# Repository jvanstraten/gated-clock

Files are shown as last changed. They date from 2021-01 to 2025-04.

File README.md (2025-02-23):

Gated Clock
===========

A clock suitable for electronics nerds, built out of 3-input NAND gates.

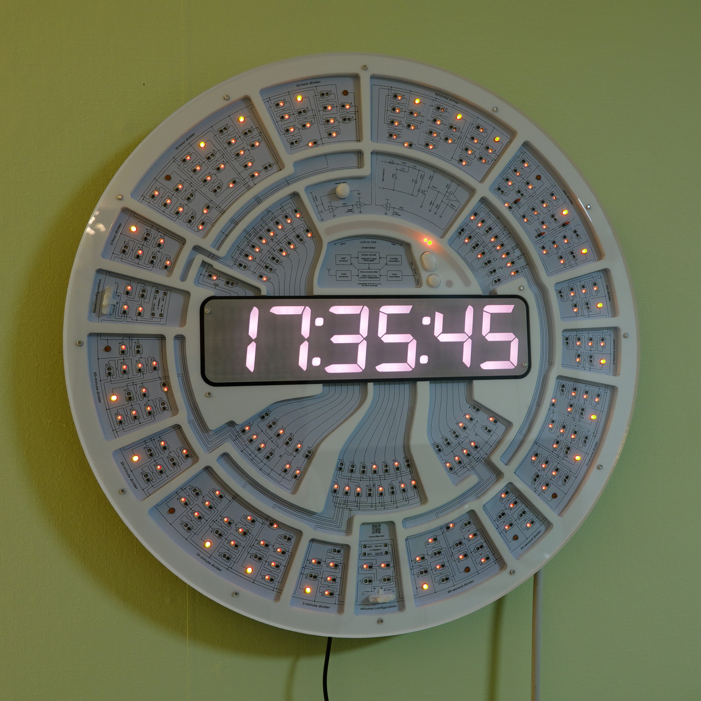
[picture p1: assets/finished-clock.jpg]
Clock


The point of this project is to:

 - build a functional digital clock out of only discrete logic gates (74LVC1G10
   3-input NANDs to be specific) and passives;
 - make sure the entire circuit for as far as this is needed to make it work is
   visible on the front, with LEDs for (almost) all digital signals;
 - actually make it look pretty; and
 - actually make it useful.

Note that none of the above include anything about BOM cost. See the section on
cost below.

The status of the project is that I've manufactured a total of nine clocks for
myself, friends, and family at this point. There's some renewed interest, so a
second run might happen; however, the Teensy LC that the old design used for
misc UI tasks is now EoL. Work is in progress to replace it with a Raspberry Pi
Pico W.

License
-------

Let's get the fine print out of the way first. The license for this stuff is
[Creative Commons BY-NC-SA 4.0](https://creativecommons.org/licenses/by-nc-sa/4.0/).
See also the LICENSE file for the full plaintext.

Note: if anyone out there would like to commercialize this somehow and needs a
different license, I'm all ears. I mostly just want to know about it if someone
does. See also: "why not build a bunch of them and sell them?"

The only exceptions to the license are the 3D models of the electrical parts I
used for the renders (basically, any of the .blend files in the `models`
directory); some of these are converted directly from the STEP files provided
by the part manufacturers and are thus licensed under different terms. I'm
honestly not too sure what these terms are, since most of the legalese they try
to make you read is about limitation of warranty with regards to model
accuracy.

How does it work
----------------

The short version is as follows.

 - The electricity grid oscillates at 50Hz or 60Hz depending on where you live,
   with stipulations about long-term accuracy by law in most places. So, while
   synchronizing clocks to the grid frequency is old-fashioned, it's actually a
   supported use case.

 - A circuit based on a capacitive dropper, an optocoupler, and some active
   filtering translates the high-voltage AC signal to a logic-level clock
   source.

 - A bunch of NAND-gate-based D-flipflops divide this frequency down to
   increasingly lower frequencies. Divider circuits exist for a factor 2,
   factor 3, and factor 5. The chain used is as follows:

    - divide by 5 to get 10Hz or 12.5Hz;
    - divide by 5 or 2x3 (jumper-configurable) to get to 2Hz;
    - divide by 2 to get to 1Hz;
    - divide by 2 to get to 1/2Hz (= 2 seconds);
    - divide by 5 to get to 1/10Hz (= 10 seconds);
    - divide by 2 to get to 1/20Hz (= 20 seconds);
    - divide by 3 to get to 1/60Hz (= 1 minute);
    - divide by 2 to get to 1/120Hz (= 2 minutes);
    - divide by 5 to get to 1/600Hz (= 10 minutes);
    - divide by 2 to get to 1/1200Hz (= 20 minutes);
    - divide by 3 to get to 1/3600Hz (= 1 hour);
    - divide by 2 to get to 1/7200Hz (= 2 hours);
    - divide by 5 or 2 based on the last divider to get to an average of
      1/28800Hz (= 8 hours);
    - divide by 3 to get to 1/86400Hz (= 1 day).

   Note that the division works very different than how you would do it in an
   FPGA. In an FPGA you'd probably have binary counters with a clock-enable
   signal on the registers and call it a day. But that requires *considerably*
   more logic to do. The dividers here are all clocked based on the previous
   output, which omits the clock enable requirement, and they are based on
   shift registers rather than regular binary counters. Note also that the
   dividers are chosen such that each decimal digit of the time it represents
   has its own set of counters, with states independent from the counters for
   the other digits.

 - A bunch more NAND gates in an and-or-invert configuration take the state
   signals and convert them to (active-low) 7-segment display signals for the
   clock readout. These drive the LEDs more-or-less directly.

 - A clock needs to be configurable, of course. It'd be a bit inconvenient if
   you'd have to turn it on at midnight exactly. Therefore, the clock signal
   for the minutes and for the hours passes through a configuration circuit
   with a three-way switch that allows you to override it: the circuit either
   forwards the clock signal in one extreme position of the switch, overrides
   it high in the middle position, and overrides it low in the non-latching,
   opposite position. The subsequent dividers increment on the rising edge of
   the clock signal, so releasing the switch from its non-latching position
   always increments the time, and going from the passthrough position to the
   middle position *may* increment the time (this is an unwanted side effect
   that would require an XOR to avoid, which would take more gates than I had
   room for).

 - Flipflops require a reset signal to be put in a well-defined state. A
   power-on reset circuit asserts this global reset line to do this at powerup,
   and a button allows you to override. This button could also be used to
   synchronize the seconds counter, as the clock starts at 00:00.

 - Because I don't like manually configuring clocks, and especially setting the
   time with the above interface would be annoying, there's also a
   microcontroller in here somewhere. This microcontroller can also override
   the minutes and hours clock signals, so it can also set the time. It can
   also read and override the non-latching position of the manual configuration
   switch, allowing it to convert its function to increment the time when
   you're pushing it outward rather than when you release it, and to
   auto-increment it when you hold it in the extreme position. Different-color
   LEDs are used to indicate the state of these override signals, so it's clear
   when the microcontroller is doing something. The microcontroller can
   synchronize itself using a GPS module (GPS is about the most accurate time
   reference you can get in your home that isn't a literal atomic clock!).

 - Because I had some room left on the board visually, I added a sort of
   synchroscope to it for showing the speed difference between the
   GPS-referenced and grid-referenced time signals. This is completely
   unnecessary for the operation of the clock, but I'm generally also
   interested in seeing the grid frequency fluctuations, so it's kind of a
   two-projects-in-one thing for me.

 - The microcontroller can also override the reset signal, read and override
   the grid frequency clock signal, and read and override the state of the
   7-segment display. This allows it to do fancy stuff like a self-test of the
   circuit (so you don't have to wait a day for it to pass through all states),
   and to override the display with a menu structure in conjunction with three
   soft buttons.

 - Finally, the microcontroller controls LED brightness and (in case of the
   7-segment display) color using not only PWM but also analog dimming.
   Basically, I hate flickering LEDs and LEDs that are way too bright, and
   couldn't make up my mind about the display color so I rammed some RGB LEDs
   in there.

For more details, check out the `primitives` and `subcircuits` directories.
Most of the circuitry is ASCII-art'ed in there, with more elaborate
descriptions.

How did you design it
---------------------

Yeah, about that. I'm used to working in Altium, but didn't want to use it for
this because:

 - arcs, arcs everywhere;
 - it's ridiculously slow nowadays;
 - I only have access to a sponsored license through a student association
   which has nothing to do with this project, and their licenses are
   unaffordable when you're not designing PCBs for profit full-time.

I heard KiCad is good and tried it, but started hating my life within a few
hours. Altium has spoiled me.

So, I did what any reasonable person would do and ~~abandoned the project~~
built my own PCB design flow from scratch using Blender and Python. More
details on this are in the README file of the `primitives` directory.

The practical upshot of doing everything from scratch however is that I could
hook into it wherever I wanted. For example, the Python scripts also generate
VHDL to test the actual circuit logically, with some best-effort timing
estimates even. After generating everything, you can just run `vhdeps ghdl`
or `vhdeps vsim` (see the [vhdeps](https://github.com/abs-tudelft/vhdeps)
for more info) and it will check everything (GHDL is super slow for the
main test case however). It also allowed me to make proper no-compromises 3D
models of the PCBs, something that I always wished Altium would let me do. I
don't just want the holes and outline, damnit, I want the copper traces and
silkscreen and soldermask and whatever as well! Seeing as part of the goals
is for it to be pretty, being able to make proper renders in advance was pretty
important for me.

How do I get one
----------------

tl;dr: I do not sell these, nor do I plan to do so personally. You're free to
build one yourself though (and I'd love to hear about it if you do!), and I'm
open for discussion on commercializing it if that's your cup of tea.

### BOM cost

I personally didn't care too much about this. I mentally give myself an
approximate monthly allowance for hobby stuff, and because this project has
taken so long already, I'm actually way under budget. That means I did
basically *no* cost-optimization.

I can't put an accurate price tag on the thing because I split everything over
multiple orders while prototyping, but I would expect the whole thing to set
you back somewhere around **€500-€800**, assuming you already have the
necessary equipment for SMD soldering and a 3D printer with sufficient build
area.

A lot of that is startup cost though. For example, the main PCB is ~€200 for
the minimum quantity of five even at insanely cheap places like JLCPCB. One
does not simply a 40x40cm four-layer PCB with white soldermask, I guess. The
acrylic lasercutting also has a significant startup cost, and of course part
cost at Mouser or whatever distributor you prefer will go down for higher
volumes as well. The price per clock probably drops off to around €300 or so
per clock for five of them.

### But if it's so much cheaper at scale, why not build a bunch of them and sell them?

I can't believe I'm writing this; it feels so "full-of-myself". The only reason
I'm putting this here is because multiple people have asked me to make one for
them.

No, I won't personally be commercializing these. I honestly can't be bothered
dealing with things like shipping, managing payments, taxes, supply chain,
redesigning the whole thing for pick & placing rather than manual soldering,
and so on. I'm the kind of person to hand perfectly resellable stuff over to a
local goodwill or whatever for free because trying to do anything more stresses
me out so much that it's just not even close to worth it.

*However.*

I love the idea of this thing hanging on someone else's wall as well.
Therefore, I made sure not to use any software or whatever that does not allow
commercial usage, and I did make sure that the thing should work worldwide
(50/60Hz selection, 100-250VAC input voltage, and using GPS instead of DCF77
for time sync). So, in case someone with a more entrepreneurial spirit than I
have wants to pick things up from where I left off to sell these for a profit,
it should be no problem aside from the things I mentioned above. I would expect
*some* compensation (hence why I've slapped a noncommercial license on this
thing for now), but ultimately this is just a hobby project for me. Mostly I
just want to know about it if someone does this. You can contact me at
e.

Above does not apply if you just want to build one yourself and sell the other
four to friends to recoup some of the one-off costs, like I might do. If that's
all you want to do, go for it; I'd still like to know out of curiosity, but I
don't expect anything in return. The limit for me would be when you start making
profit.

Okay, then how do I build one
-----------------------------

You're going to need the following things.

 - A Linux computer or VM, probably. Some or all of it may work on Windows/Mac
   too, but your mileage may vary. The following software is needed:
    - Blender. Scripts updated for blender 4.2. Blender is good with
      compatibility, but with all the scripting going on, you might want to get
      that exact version. The makefiles look for `blender-4.2` in your `PATH`
      first if it exists, before defaulting to just `blender`.
    - Python 3.x. It used to work back on 3.6, nothing has meaningfully changed
      since, and it still works on 3.13 now that I'm writing this update. It
      probably doesn't matter too much if your version is newer than that.
    - [Gerbertools](https://github.com/jvanstraten/gerbertools). Depending on how
      lazy I am you might have to build it yourself, but that should be pretty
      easy.
    - The following regular Python modules: `matplotlib` (3.10) and `qrcode`
      (worked with 6.1 initially, still works with 8.0 without changes).
    - ImageMagick for converting huge SVGs that take forever to render to
      big-enough PNGs.
    - Inkscape for making PDFs out of SVGs (part of the acrylic plate pipeline,
      you'll probably have to customize/redo this though).
    - `git`, as in the commandline version, should exist. It's used by the
      generator to tag the generated boards with the current revision.
    - `make` is abused for some things.
    - `7z` (7zip) is used for packing the generated gerber files into a zip
      file.
    - You may also want [`vhdeps`](https://github.com/abs-tudelft/vhdeps) and a
      compatible simulator, if you intend to change any circuitry.

 - Soldering equipment. If you've never soldered (SMD) before, this might not
   be the best project to start with. The LED drivers in particular are 0.5mm
   pitch TSSOPs with a thermal pad. The boards are designed to be hand-soldered
   though, so the pads are relatively long, and I took care to only connect
   traces to the end that you stuff the soldering iron into, so heating them up
   should be relatively easy. Unless you like to live dangerously, you should
   also have anti-ESD gear and actually use it during assembly.

 - A current-limited lab power supply, multimeter, waveform generator, and
   oscilloscope are very much nice-to-have. I don't think it's humanly possible
   to solder everything correctly the first time, so you will be doing some
   debugging.

 - A 3D-printer with at least 21x25cm build area. I'm using a Prusa MK3s with
   a stock 0.4mm nozzle and print in PETG. I'm not sure how much filament is
   used exactly. You'll want some 3D-print post-processing stuff as well, which
   I'm assuming you'll have if you have a printer.

 - An M3 tap for inner thread.

 - A source for the lasercut acrylic plates. I'm using a local Dutch shop
   ([laserbeest.nl](https://www.laserbeest.nl/)). Unfortunately I'm not sure if
   they ship internationally. Their ordering instructions are a bit "custom",
   so you'll probably have to change the pipeline or do some manual conversion
   work of the generated PDF/SVG files.

 - A source for the two PCBs. I'm used to ordering from JLCPCB, but there are
   more of them out there.

 - A source for the components. I'm using Mouser for everything now, so the
   generated ordering information is for them.

 - A source for the Teensy LC, the GPS module, and the antenna. I got those
   from [TinyTronics](https://www.tinytronics.nl/shop/en); a local shop again,
   but I'm pretty sure they ship internationally, or at least within Europe.
   Either way, the Teensy in particular shouldn't be hard to get your hands on,
   and you can probably jury-rig any GPS module you want in there (or leave it
   out entirely if you don't care enough about GPS sync). The headers you'd
   probably want to mount the Teensy to the support board are not included in
   any ordering list; you can do anything between proper male/female headers
   and just sticking wires through the holes and soldering them.

 - Some miscellaneous parts not in any ordering list because I had them laying
   around:

    - 41 M3x12mm screws with a domed head of at most 6.2mm diameter and about
      2mm thickness, though if you don't have a bunch of screws in stock you
      might want to get longer ones and cut them to size with a thread cutting
      tool;
    - 25 standard M3 hex nuts, 2.5mm thick;
    - a long M3 screw is nice to have to help pull the nuts into the printed
      parts;
    - a screwdriver for the above, obviously;
    - calipers are very useful to have lying around, if only to measure the
      thickness of the acrylic you got;
    - a mains power cord to mount to screw terminals on the support board
      (preferably with grounding lead, though this is technically not necessary
      due to the lack of exposed metal);
    - stuff to clean the acrylic with when you're done (I used "wasbenzine,"
      but that stuff doesn't seem to have a proper English translation for some
      reason. The best translation I suppose would be pure gasoline. Contrary
      to what Google et al will tell you it is *not* white spirit, which would
      be "terpentine" in Dutch, and would be likely to mess up your acrylic).

 - An appropriately filled wallet, because this is not a cheap project. But we
   went over that already.

### 1) File generation

If you're ordering via laserbeest and want to use the existing pipeline, you
will want to set the following environment variables:

 - `ACRYLIC_NAME`: your full name;
 - `ACRYLIC_EMAIL`: your e-mail address; and
 - `ACRYLIC_PHONE`: your phone number.

These are added to the SVG/PDF files that are generated for Laserbeest for
their reference, as per their instructions.

You'll also want to update the header of `generator/orderlist.py` to select
the LED color you want. Seven color schemes are predefined. At the time of
writing I've only tried orange; your mileage may vary with the resistor values
for other colors. LED brightness differs a lot based on color.

Once you have all that, or the computer part at least, run `make` in the root
directory and go get coffee. It takes 20 minutes or so to generate everything
on my fairly beefy computer, though most of it is single-threaded because I'm
lazy, so the beefyness of your computer might not make too much of a
difference.

Note that the root makefile is *not at all* intelligent, and may as well be a
shell script. You may therefore want to comment out part of the `make` recipe
manually while iterating to not regenerate literally everything each time.
There's also `generator/config.py`; if you set the `LAYOUT_ONLY` constant,
things will be way faster, but won't generate any copper, and use
reduced-complexity routing for the circuit on the silkscreen.

Anyway, the pipeline generates the `output` directory, with about a GB's worth
of files in it (hence why I don't try putting the generated files on github).
The filenames should be fairly self-explanatory, at least in conjunction with
the documentation scattered about this repo in the form of README files.
Nevertheless, the most important ones are:

 - `mainboard.zip`: Gerber production files for the main PCB;
 - `support_board.zip`: Gerber production files for the support PCB;
 - `*.*.traces.png`: circuit board assembly instructions (and copper layout);
 - `mainboard.laserbeest.pdf`/`.svg`: acrylic plate production files;
 - `mouser.txt`: Mouser ordering list; and
 - `tinytronics.txt`: TinyTronics ordering list (the Teensy, GPS, and antenna).

### 2) Ordering

You should start by ordering the parts, obviously: the Mouser/TinyTronics
electronics parts, the PCBs, the acrylic sheets, and the consumables if you
don't have them laying around like I do.

As stated, the build process generates `mouser.txt` for the mouser ordering
list, usable [here](https://nl.mouser.com/Tools/part-list-import.aspx). If
things are not in stock, you'll either have to wait or look for alternatives
yourself; you can specify these alternatives in `generator/orderlist.py`, after
which you can regenerate by just running `python3 generator/orderlist.py`. If
you (have to) go for the backorder route, I strongly recommend the "ship items
as they become available" option; in my experience, Mouser doesn't reserve
anything for your order, so by the time the originally problematic part is
finally back in stock, something else might be out of stock again.

After you copy the part list into your basket, make sure to round up the part
count, especially for uncommonly used resistor values and such: Mouser levies
what I can only describe as an "asshole tax" for people who order small amounts
of these, as ordering more will often cost *less*. I've seen an extreme case
where the price break for 10+ was so much cheaper than the price break for 1+
that buying ten was cheaper than buying one! The ordering system does not
notify you of this. In general, by the way, it's good practice to over-order
the tiny parts a little bit, so you don't have to place a new order if you
misplace or break a few of them.

As for the Tinytronics parts, the actual parts are a Teensy LC (which you can
get just about anywhere), and any GPS module with a VCC|GND|TX|RX|PPS pinout
using a standard 2.54mm header. You can probably source both from wherever if
Tinytronics doesn't work for you. Don't forget to buy an antenna with a long
lead as well; they're commonly available for use in cars. Headers to mount
these are not included in the Mouser order either, so you'll need to get them
yourself.

For the PCBs, everything assumes standard 1.6mm 4-layer PCBs with 1oz copper on
the outer layers and something around .5oz on the inner layers. The mainboard
is visible and is assumed to be built with a white soldermask and black
silkscreen, but it's up to you; the support board is not visible and thus the
color does not matter. Stackup was designed with 0.1mm between the outer and
inner layers in mind, but I later found out that JLC only does this for green
soldermask PCBs, so I ended up with 0.2mm separation. Doesn't really matter;
nothing is explicitly impedance-matched. The only thing is that the trace
capacitance calculations I did assume .1mm separation, but that would be the
worse case anyway.

The footprints are designed for conventional soldering by hand. If you want to
use solder paste with an oven or hot air, you might want to rework some
footprints here and there. In particular, the support board has four components
with a thermal pad (the LED drivers and the hot-swap controller), which have a
large hole under the pad to provide access to a conventional soldering iron;
you'll probably want to remove those holes when using solder paste.

As for the acrylic, three sheets are needed:

 - `Front`: clear, 3mm, at least 40x40cm. Includes engraving instructions in
   addition to cuts.
 - `Highlight`: opaque white, 5mm, at least 40x40cm.
 - `Display`: opaque black, 3mm, at least 23x6cm.

The thickness tolerance of Laserbeest's acrylic source is abysmal, apparently
due to how the sheets are made. So everything is designed with about +/-1mm
thickness tolerance in mind. However, you may need to adjust some 3D-printed
parts here and there, or you may need slightly shorter or longer M3 screws.
Of particular importance is that the button and slide switch caps have the
right height,

You may also need to adjust the hole sizes in the `Front` sheet based on laser
width and how gutsy you're feeling. They need to be threaded, so the finished
hole size should be 2.5mm. They are 2.35mm in the design files for Laserbeest,
which worked well based on experimentation.

When you receive the acrylic, don't throw the bubble wrap it undoubtedly comes
wrapped in away! It'll be useful during assembly.

### 3) 3D-printing

I would recommend to wait with this until you have the acrylic, because some of
the parts depend on its thickness to various degrees. I was far too impatient
for this, myself; just be aware that you may need to reprint parts later if you
don't wait. The following parts depend on the thickness of the acrylic:

 - the four quarter panels of the back shell have the clamping surface for the
   screw heads at just the right size for the bottom of the M3x12 screws that
   mate with the clear acrylic sheet to be flush with the front, so this
   recess depends on the thickness of the white and clear acrylic sheets;
 - likewise for the "display extender" part, of which both the total height and
   mounting flange thickness depends on the thickness of the black and clear
   acrylic parts;
 - the button and slide switch caps depend on the thickness of the white
   acrylic sheet.

The Blender sources for the parts are in the `printed` folder, the main one
being `assembly.blend`. When you open it (give it time, the boolean operations
and geometry involved are considerable) you will be presented with some text
and a few "empties;" the axis-looking things in the middle. Their negative-Z
position represents the thickness of the three acrylic sheets. You can select
them by right-clicking (or left-clicking I think, if you're using the 2.8+
keybinds), and then use the transform panel on the top-right of the viewport to
change the Z coordinate to negative the thickness.

Once you've done that, note the note the panel on the top-right of the screen,
listing the assembly steps. You can disable visibility of all the steps except
the first by clicking the eye icons, then work from there. Use numpad 7 to view
the clock from the back (as you will be assembling it), or numpad 9 to view it
from the front. Dragging the middle mouse button will drag the view around,
holding shift as well will pan, and scrolling zooms in and out.

STL files can be generated by selecting the object you want (right/left-click
as before), selecting File -> Export -> STL, ticking the "Selection Only"
checkbox on the right, and picking a nice filename. You'll have to orient them
onto the build plate (most parts have an obvious flat side) using the slicer
for your printer.

I use PETG for everything. PLA might be fine as well, but be careful that in
particular the mounting bracket is strong enough -- wouldn't want the clock to
break off your wall in the middle of the night. I don't exactly consider myself
to be a very experienced 3D-printer, so your mileage may vary.

Some of the parts need build plate supports, so some post-processing is
involved. The slide switch caps in particular needed some TLC for me before
they would slide properly, and I had to drill out the holes in the spacers for
the extra-long headers. If you don't have a 1mm drill and a drill press to do
this with, you can probably mess with the part and print settings until that
one works straight out of the printer though, or you could probably also just
eyeball the correct insertion depth for the headers when soldering.

### 4) Mechanical assembly (dry run)

Once you have the 3D-printed parts, acrylic, and bare PCBs, I would suggest a
dry run of assembling the thing, so you know what goes where and you can be
sure everything fits before all the delicate parts are populated.

 - Carefully clean the clear acrylic sheet. There will be debris from the
   engraving; make sure it doesn't cause scratches! I personally messed up here
   because I assumed there would be protective foil on both sides; there was
   not.

 - Carefully tap the holes in the clear acrylic sheet. Be patient; acrylic
   cracks if you're too rough. Don't use power tools!

 - Place the clear acrylic sheet on bubblewrap, to avoid causing scratches and
   allow the button and slide switch caps to stick out slightly. The rough,
   engraved side should be facing up.

 - Place the black acrylic sheet on top. It is *not* symmetrical in any
   direction: make sure that the colons are off-center *away* from the side
   with the synchroscope and pushbutton cutouts, and of course that the
   screw holes align.

 - Place the printed display extender part on top of the display, again
   ensuring that it is oriented correctly.

 - Mount the black acrylic sheet and display extender using two M3x12 screws.
   Be careful not to exert too much torque; threaded holes in acrylic are
   quite fragile!

 - Place the white acrylic sheet on top. The cutout for the display should
   constrain it in roughly the right place aside from 180deg rotation symmetry;
   align based on the synchroscope engraving and/or button cutouts to avoid
   mounting the plate upside down.

 - Place the three button caps (2x round, 1x oblong) and the two slide switch
   caps in the appropriate cutouts.

 - Carefully place the mainboard on top. First align the slide switch caps with
   the slots in the PCB (and the slide switches themselves if you already
   soldered then), then align the pins on the bottom of the button caps with
   the holes in the PCB, and finally align the holes.

 - If you haven't already, insert nuts in the hex recesses of the four quarter
   panels. There are eleven of these. Pull them in with a screw if necessary,
   and make sure they're all the way in (they should be flush or slightly
   recessed into the bosses. If your print is undersized and they fall out, you
   might want to glue them in.

 - Slot the quarter panels together. They are all different, so there's only
   one way to do this. Secure them by placing screws in the four shared screw
   holes; the assembly shouldn't fall apart anymore after you do this, although
   it will still be quite floppy.

 - Carefully place the panels over the rest of the assembly. The triangular
   screw hole pattern should be at the top of the clock, i.e. the side with the
   synchroscope and buttons.

 - Start by tightening the four screws that hold the quarters together. Again,
   be careful not to exert too much force. Be especially careful if you're
   impatient and are doing this before you have the PCBs: you can easily break
   the 3D-printed parts by tightening the screws without the 1.6mm spacing
   provided by the PCB. Once these four screws are in, screw the remaining ten
   in in any order.

 - Flip the clock over and make sure that the slide switches and buttons move
   freely. If not, disassemble in reverse order and file them down a bit.
   Repeat ad nauseum until they work right. Once done, place the clock down
   on its front again on the bubble wrap.

 - Mount the wall mount bracket to the assembly with three screws. The screws
   mate with the triangular-pattern nuts in the top quarter panel. Be careful
   when tightening these the first time; the screws should be too short to
   reach the PCB, but if they do, you can easily damage the PCB.

 - If you haven't already, insert nuts in the hex recesses of the support board
   interface part. There are four of these. Pull them in with a screw if
   necessary. If your print is undersized and they fall out, you might want to
   glue them in.

 - Mount the panel-mount SMA antenna connector end of the SMA to uFL adapter
   cable that comes with the GPS antenna to the small square SMA insert part,
   making sure to align the flat side of the panel-mount connector with the
   flat side of the hole.

 - Slide the above assembly into the corresponding retaining structure of the
   support board interface part. Note that this might require some "gentle
   persuasion" the first time; it should be more-or-less press-fit.

 - Mount the support board interface assembly onto the main assembly with eight
   screws. They mate in the same way as the wall mount bracket, so be careful
   if the screws may be too long.

 - If you haven't already, insert nuts in the hex recesses of the display light
   guide. There are six of these. Pull them in with a screw if necessary. If
   your print is undersized and they fall out, you might want to glue them in.

 - Mount the display light guide to the support board using six screws. Be
   careful not to place it upside down; follow the silkscreen on the PCB.

 - If you haven't already, insert nuts in the hex recesses of the high-voltage
   top cover and strain relief. There are two of these in either part. You
   know the drill by now.

 - Mount the top and bottom high-voltage covers to the support board using two
   screws. There should only be one way to do this.

 - Mount the strain relief to the bottom high-voltage cover.

 - Place the support board onto the main assembly, making sure to align the
   screw holes. The upright flanges inside the support board interface part
   should constrain it.

 - Place the support board cover on top. Again, some "gentle persuasion" may be
   needed for the SMA connector insert the first time. Finally, clamp it down
   with four screws, that should mate with the four nuts in the support board
   interface part.

 - Carefully lift the clock up by the wall mount. Make sure it's strong enough
   to hold the weight with ease.

 - Find a nice place to mount it to a wall! You can just use a nail or screw to
   do it, or you could print a part that mates with the wall mount bracket if
   you're worried about the strength of the part.

Disassemble in the reverse order as usual. The wall mount can stay mounted to
its quarter panel, but note that you can't remove the quarter panels from the
acrylic without removing the support board assembly, because it hides one of
the fourteen screws that mate with the acylic.

### 5) Electronic assembly

Some preprocessing is required:

 - The 3D-printed parts include a small lead bending tool for the 3mm LEDs. It
   consists of two square printed parts, and is completed using four M3 nuts
   and four M3x12 screws. To use it, push the LED into the hole, bend the leads
   outward far enough for the screws to reach the recesses for the nuts on the
   other side, then carefully tighten the screws while guiding the leads into
   the cutouts for them. Once tightened, cut the exposed part of the leads off
   with pliers. Finally, disassemble everything again to retrieve the LED. I've
   found that two screws on opposite sides is enough.

 - The trace connecting the USB bus voltage to the 5V rail on the Teensy LC
   must be cut, to prevent the power supply on the support board from trying to
   power your PC.

 - The mainboard to support board connectors are slightly too short right out
   of the box: the male side should be soldered flush to the opposite side of
   the PCB rather than having it stick through slightly as usual.

Ultimately, the order in which you solder the parts is up to you. Here's some
tips and recommendations, however.

 - I couldn't be bothered to add part designators to the board generation
   scripts and design entry file formats, so you'll have to use the
   `*.*.traces.png` output files to figure out what to solder where. However,
   the circuitry is so repetitive that you won't need it most of the time.

 - The mainboard circuitry is highly linear, which means you can solder one or
   a few subcircuits at a time and then test whether everything works. Start
   with the reset circuit and the clock pulldown resistor (the 10k resistor
   near the TSSOP I/O expander), then work your way around clockwise for the
   dividers, and finally solder the decoders. You can test using the staggered
   receptable for a standard 2.54mm 5-pin header (push it in upside-down; the
   spring force of the pins will friction-lock it in place). The `f50Hz` signal
   should receive a 0V..5V clock signal, `Vled` and `Vffled` should be pulled
   *down* to somewhere between 2.5V (max brightness) and 4.5V (least
   brightness) to turn the LEDs on, and `0V`/`5V` should be self-explanatory.
   A two-channel waveform generator is ideal for the `f50Hz` and
   `Vled`/`Vffled` signals, the latter because a waveform generator can pull
   down as well (unless you have a super-fancy power supply, it won't be able
   to). If you don't have a waveform generator or only have a single-channel
   generator however, you can probably get the LEDs to light up with a 1:1
   voltage divider using 100R resistors as well, and you can strobe the clock
   by just pushing a 5V wire into the `f50Hz` signal (it will bounce though,
   so this won't be very controlled). Use a properly current-limited power
   supply (somewhere around 400mA should be enough for the whole clock with
   the default LEDs), such that you don't fry something if you accidentally
   short-circuited something. Being able to see the current is also very
   useful, because then you'll see the current rise when a gate output is
   shorted. Other than that, ensure that all LEDs blink when you apply enough
   clock pulses. Some common symptoms:

    - Current shoots up by about 40mA for some flipflop states: there's
      probably a short-circuit to 0V or 5V *after* a 100R filter resistor.

    - Current shoorts up by about 150-200mA for some flipflop states: there's
      probably a short-circuit to 0V or 5V between a gate output and the
      100R filter resistor.

    - Current limit kicks in at around 1.0V to 1.5V: you probably mounted a
      gate rotated 180-degrees.

    - Current limit kicks in immediately: you have a dead short somewhere. You
      can trace this by measuring the voltage across the decoupling capacitors
      while the power supply is on. I got about 2.7mV over the decoupling
      capacitors serving good circuits and less than 2mV for the one that had
      the short, for only 200mA supply current.

    - No unexpected current (the current should be <1mA when the `f50Hz` input
      is idle and the LEDs are off), but one or more flipflops/decoder outputs
      don't work right: usually this is due to a bad soldering joint for one
      of the gates. You'll have to debug this by finding the gate that doesn't
      perform its logic function properly.

    - The circuit works, but a LED doesn't light up: check for bad soldering
      joints in the LED circuitry.

    - Everything is fine in steady-state, but a flipflop doesn't work: I didn't
      personally encounter this, but this is what I'd expect to see if you
      misplaced a capacitor or resistor somewhere in the RC filter circuits.
      The filters are there to solve worst-case hold timing, so the flipflops
      might misbehave with improper filters. I've found that leaving the 330pF
      and 2.2nF capacitors out entirely also works, however (with a sample size
      of only 1 flipflop, though).

 - While soldering the mainboard, put short screws in the screw holes that
   prevent you from accidentally exerting force on the 3mm LEDs or 1.27mm
   jumpers when the board is upside-down. Otherwise, you can easily bend the
   headers, or push the SMD pads for the LEDs right off the board.

 - For the support board, first solder the hot-swap controller circuit and test
   it. There's a lot of critical resistor values there, and if they're wrong,
   the board won't do anything or won't be as protected against
   over/undervoltage and overcurrent as it can be. I would furthermore suggest
   leaving the mains stuff for last, because it's large, and because you'll
   then lose the ability to power the board with a better-protected lab power
   supply.

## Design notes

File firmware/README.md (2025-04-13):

Firmware
========

By design, the clock can operate entirely without any microcontroller firmware.
After all, the whole point is to demonstrate that you can make a useful circuit
with only NAND gates and some discretes. Nevertheless, some auxiliary functions
are handled by a microcontroller:

 - LED brightness and color control;
 - automatically configuring the time using GPS after a blackout;
 - blinking the display before a time is set (either manually or automatically)
   after a blackout;
 - automatic DST changes;
 - the synchroscope display; and
 - handling UI stuff for configuring all of the above.

Build process
-------------

The microcontroller (board) in question is a Teensy LC. I opted for such a
board versus a "discrete" microcontroller primarily because you don't need a
programmer for them, and because Arduino makes it so easy to set something up
quickly. Arduino is however hardly a platform for distributing a reproducible
build with: the user has to manually set options like board, operating
frequency, and USB mode, and many times for Teensy you end up changing system
files to change a buffer size somewhere or something. Therefore, to try to make
things a little better, a docker-based build is provided.

When you run `make` in this directory, the following things will happen:

 - docker will be used to do a build using exactly the Teensy core library
   version I use;
 - the [Teensy loader CLI](https://github.com/PaulStoffregen/teensy_loader_cli)
   will be downloaded and compiled;
 - an attempt will be made to put the first Teensy connected to your system in
   programming mode (this only works when it has a program on it that uses the
   USB for serial communication); and
 - an attempt will be made to program the Teensy (if aforementioned fails,
   you'll have to press the programming button).

So, before running `make`, make sure that you have a working Docker, working
dev essentials (GCC, make, etc), and the libusb 0.1 development headers that
the Teensy loader CLI uses.

### Updating timezone definitions

You can automatically update the timezone database that the clock uses for
auto-DST by running `src/timezones.py`. The database is based on data provided
by [timezonedb.com](https://timezonedb.com/).

User interface and configuration
--------------------------------

The clock has three software-only buttons (labelled up, down, and mode), one
hardware reset button, and two slide switches. To the right of the mode button
there is also a dedicated RGB LED for status information. These elements,
combined with the main 7-segment display and the synchroscope bar, are used to
configure the clock.

Under normal circumstances, the 7-segment display displays the time, the status
LED is off, and the synchroscope display behaves as configured (by default, the
LEDs act like the needle of a electromechanical synchroscope). But there are a
few exceptional cases:

 - If the GPS module is not locked and GPS time synchronization is enabled, the
   status LED turns red.
 - If the time is invalid (for example, after a power cycle), the 7-segment
   display blinks.

The buttons and switches have the following functions in this state.

 - The hardware reset button resets the time. This also "invalidates" the time,
   making the display blink. If GPS synchronization is enabled, you can press
   this button to force resynchronization.
 - The slide switches may be used to manually configure the clock. The left
   switch controls the hours, the bottom switch controls minutes. To configure
   the time, you can use the following procedure.
    - Move both switches to the center position. This prevents the minutes and
      hours counters from updating when the seconds and minutes counters
      overflow.
    - Optionally, press the reset button when you want the seconds counter to
      read zero. There's no way to configure the seconds otherwise. Note that
      you'll want to disable GPS synchronization if you do this, or the clock
      may try to automatically configure itself instead.
    - Configure hours and minutes independently by pushing the respective slide
      switches into their clockwise position. If auto-increment is enabled in
      the clock's settings, the microcontroller will make this process more
      convenient: the counters will then increment when you push the button
      towards the clockwise position and will auto-increment if you keep
      holding it. If you disable this setting, the counters will instead
      increment only when you release the respective switches, but everything
      is handled by the discrete NAND circuit.
    - Move both switches back to the anti-clockwise position.
 - Pressing the down button enables "distraction-free" mode. In this mode, all
   LEDs except for the hours and minutes 7-segment displays and the status LED
   (if the GPS signal is used and lost) are disabled. Press the up button to
   exit this mode.
 - Briefly pressing the mode button will display the date in YYMMDD format, if
   GPS is currently available or has been available at some point since the
   last power cycle. The status LED will turn green to indicate that the clock
   isn't displaying time; also, the colons are turned off. Press mode again to
   return to normal operation.
 - Hold mode down for at least one second to enter the setup menu.

The setup menu consists of a number of configuration parameters, that you can
cycle through using the up and down buttons. You can leave the menu by holding
down the mode button again, by pressing up and down simultaneously, or simply
by waiting. When you leave the menu, any changes made to the configuration are
written to non-volatile memory, so the configuration survives a power cycle.

While in the menu, the current parameter is shown on the left side of the
7-segment display via an abbreviation. Its current value is shown on the right.
The status LED turns dark blue to indicate that you can cycle through the
values with up and down. The behavior of the synchroscope display depends on
the selected parameter.

The mode button is used to change the value of the current parameter. For
"enumerated" values, pressing mode simply advances to the next value. For
numeric values, the status LED will instead turn light blue, at which point
you can change the value by means of the up and down buttons. For most
parameters, the value will also blink to indicate that you can change it;
the only exception is the "display brightness" parameter. Instead, the display
will read `888888` while you're adjusting it, to give you a better idea of what
the brightness looks like, and also such that the clock can better monitor the
worst-case effect of the brightness on its own power consumption. For all
numeric options, pressing mode again confirms the new value, and allows you to
select a different parameter again.

The following parameters are available.

 - Flipflop LED brightness (`Fb`).
 - NAND gate LED brightness (`Gb`).
 - Synchroscope LED brightness (`Sb`).
 - 7-segment display brightness (`db`).
 - 7-segment display color saturation (`dS`).
 - 7-segment display color hue (`dh`).
 - Whether the 7-segment display brightness is automatically adjusted based on
   ambient lighting conditions. This requires an LDR to be installed. When
   enabled, the display brightness setting controls the maximum brightness.
 - Whether the seconds digits should be shown (`Sd`).
 - Configuration of the timing source of the clock and the synchroscope
   (`SYn`). Five modes are available.
    - Normal synchroscope operation (`1`). The clock is timed via the 50Hz or
      60Hz utility frequency, and the synchroscope shows whether the grid (and
      thus the clock itself!) is running slow or fast. Every 360-degree
      revolution of a real synchroscope represents a full 50/60Hz cycle lost
      or gained, which the display tries to model (despite not being a full
      circle) by moving with the same angular rate as a real synchroscope
      would, and rolling over every 84 degrees.
    - Lead-lag mode (`LL`). Like above, but instead, the synchroscope display
      shows the current offset of the seconds counter compared to GPS time.
      When the two center LEDs are both on, the clock is synchronized. When the
      outermost LEDs are both on, the clock is running exactly 30 seconds fast
      or slow. Note that this mode is not available when the seconds display
      is turned off.
    - Synchroscope display off, but still using the utility frequency as the
      clock source (`0`).
    - Synchroscope display off, using an internally-generated 50Hz timing
      source (`50`). When GPS is available, the frequency is referenced to it,
      so long-term stability should be extremely good. When GPS is not
      available, the crystal oscillator of the microcontroller takes over,
      making stability similar to a normal digital clock.
    - As above, but generating 60Hz (`60`).
 - Whether the software-controlled auto-increment logic is enabled for manually
   configuring the clock (`AInc`).
 - The [location code](timezones.md) corresponding to your timezone for GPS
   synchronization and automatic daylight-saving time adjustment (`LC`). Set to
   0 to disable automatic time synchronization.
 - Daylight-saving time configuration (`dSt`). This option is only available
   when automatic time synchronization is enabled. You can set it to `A` (auto)
   to have the clock update the time automatically when DST changes, or you can
   manually enable or disable daylight-saving time using values `1` and `0`.
   This is of course particularly relevant if your region decides to get rid of
   DST, or change its implementation. You can also choose to update the
   firmware in that case; you don't have to change any code to do this, but
   you will need to open the clock back up to attach a USB cable, and of course
   you need a computer that meets the system requirements for building and
   uploading the firmware.

For some of the options, the synchroscope display will show additional
information while the option is selected.

 - When LED brightness/color options are active, the synchroscope depicts the
   current power consumption of the clock. Full-scale is about 2.5A at 5V. When
   you somehow end up drawing too much current by making the displays too
   bright, software and/or hardware will kick in to reduce power consumption;
   at 3A or above brightness levels are automatically reduced across the board.
   Furthermore, if 3.5A or more is sustained, hardware protection circuitry
   will kick in and disable the clock until the next power cycle to prevent
   damage.
 - When the LDR option is selected, the synchroscope depicts the current
   (low-pass-filtered) value of the ambient light sensor.
 - When the location code option is selected, the synchroscope gives a rough
   indication of the GPS signal strength, which may help you find a good place
   for the antenna.

If necessary, you can do a "factory reset" of all options by holding down the
mode button while the clock powers up.

Debugging / Development notes
-----------------------------

### Listening to the serial port

When connected via USB, the board acts as a serial device, and can print some
debug data over serial. It will however only do so after being sent any
character from the host first. In a linux terminal, you can for instance use
the `screen` command to read this data. Note that the device file name may
differ depending on your setup.

- run `screen /dev/ttyUSB0`
- press any character

### Programming using Windows

While the default build process is gearded towards linux, it is possible to
program and debug the board from windows, using WSL. You will need to use
`usbipd-win` to forward the USB connection from windows to the WSL instance.
The workflow is as follows:

- install `usbipd-win` on the host computer.
- start your WSL instance on the host computer.
- in a windows terminal, run `usbipd list` before connecting the Teensy board.
- connect the Teensy board
- run `usbipd list` again to identify the bus id of the Teensy board
- run `usbipd bind --busid=BUSID`, where BUSID is the bus id of the Teensy board
- run `usbipd attach --wsl --busid=BUSID`, to attach the Teensy board to the wsl
  instance
- in WSL, install the required dependencies as stated above, and manually start
  the docker service if needed.
- run `make build` to build the firmware
- run `make program` to start the programming process. This will put the Teensy
  board in programming mode, which will cause it to reconnect.
- run `usbipd attach --wsl --busid=BUSID` again from the windows side to reattach
  the teensy board to WSL
- the programming process should now continue to completion.
- the board will detach again after programming is finished. If you want to
  debug it using the serial connection, simply reattach it again with the same
  command as before.

Note: while developing using WSL, the device will likely show up with a different
name like `/dev/ttyACM0`.

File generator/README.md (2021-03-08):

Circuit board (and acrylic) generator code
==========================================

This hot mess is what generates everything from the various other components in
the repository. The rough structure is as follows:

 - *parts* define off-the-shelf stuff;
 - *models* define 3D models for them (some parts share the same model, hence
   the distinction);
 - *primitives* are things drawn in Blender that define what (parts of) the
   circuit board looks like, which components go where, and the net names for
   their pins; and
 - *subcircuits* connect multiple primitives together via the generated,
   visually-pleasing routing on the front of the mainboard.

Primitives and subcircuits both operate on a CircuitBoard class, which in turn
contains a bunch of layers, as well as tacked-on acrylic plate definitions and
other mechanical data. The local coordinate system of a subcircuit can be
"warped" to achieve the circular transformation you see on the mainboard,
without actually warping the primitives they're built from -- the logic for
this is certainly the most complex part of all this, and god help you if you
have to or want to touch it. Finally, there is some text rendering support. The
text rather arbitrarily uses the Montserrat font from Google, and is rendered
with matplotlib (stop judging me!)

Once the gerbers are generated, [gerbertools](https://github.com/jvanstraten/gerbertools)
is used to turn them into SVGs and Wavefront OBJs, and to run electrical DRC on
them. Depending on how lazy I've been, you may have to build that module
yourself (it should be easy though, since it has virtually no dependencies
outside of a sane compiler toolchain). In total, the rules checked are short
circuits, unrouted nets, clearance (only logic-level, the 230V stuff is checked
manually), annular ring, and hole-to-hole distance. There is also some basic
netlist DRC support that ensures that logic nets in the clock circuit have
exactly one driver and at least one user, and that non-logic nets have at least
two connection points.

The entry point for all this is `compose_*.py`, awkwardly duplicated for the
two PCBs. As if that wasn't ugly enough yet, `post.py` post-processes the SVGs
generated by this and gerbertools to make see-through SVGs of the PCB, along
with net names and a notes layer that shows the pinout and sizing of all
components, which is quite useful for manually checking the circuit. In
general, the circuits are also listed in ASCII art in the primitives
directory... but I didn't go so far as to read those and do circuit-to-PCB
matching automatically. The PCB *is* the circuit.

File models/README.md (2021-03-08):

3D models for parts
===================

This folder contains 3D models for all the parts.

`template.blend` may be used as a template for them; it doesn't have the usual
light and camera and stuff and has the coordinate system scaling properly set
up. `materials.blend` is used as a library for all the materials that the parts
use, so they can be tweaked easily; thus, all part blend files link to this
file. Other than that, however, there's nothing special about these blend
files; their main collection is simply instanced whenever a part is used
somewhere.

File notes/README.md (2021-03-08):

Notes
=====

Assorted notes and LTspice simulation circuits. No clear structure. Basically,
nothing to see here, move along.

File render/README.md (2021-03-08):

Renderings and mechanical integration
=====================================

The stuff in this folder is used to get a "3D CAD" overview of the entire
assembly, and of course to make nice renders of it. The file you're looking for
is `top.blend`, but make sure to run the makefile in the root first, or you'll
get errors about missing links.

The various Python scripts and template files are used to build blend files for
the PCBs, acrylic plates, and their part instances. This is all managed by the
makefile in the root directory. All output products land in the `output`
directory.

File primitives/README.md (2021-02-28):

Circuit primitives
==================

These represent the primitive components for as far as the netlist and PCB
generator is concerned.

Each component consists of a readme file with the circuit, a VHDL model for
simulation, and a .blend file for everything else.

"A .blend file? What?"
----------------------

Yes.

I'm used to working with Altium, but for performance and legal/fiscal reasons
that it just wouldn't cut it for this project. Too many arcs/primitives for it
to reach workable FPS while editing, polar grids are terrible to work with as
I've learned, and ultimately, even if it would have worked, the license I have
access to is not meant for random hobby projects.

I tried KiCad, but started questioning life choices and was ready to ragequit
the whole project within two hours. So I took a step back. "What do I actually
need?"

Well, since the circuit and most of the placement data is generated, and I
worked out the schematics and routing largely in ASCII art, I would at least
want a way to import the bulk of that into whatever PCB design program I'd
use. Like, make "symbols" for the various subcircuits and routing repeated all
over, and then copypaste orientation and coordinate data into the design. Then
do the global routing, stare at 3D models, run DRC, generate gerbers, and
that's basically it.

So, I thought, why go through the trouble of finding a new free or cheap PCB
design tool that might not even exist (at least not to my liking) and then
spend the trouble actually learning to use it sufficiently to make the final
result look nice, when I can just cut out the middle man and generate the damn
Gerber files myself?

This had a few snags of itself, of course.

 - I need DRC of some kind; this PCB is way too expensive for me to want to
   fuck up. Mere electrical DRC (clearance/short circuit, unconnected net) is
   sufficient though, since JLCPCB (and most other fabs) do an online
   manufacturing DRC before you can even place an order. That's just a few
   cleverly chosen boolean operations on polygons; surely there's
   [a library for that?](http://www.angusj.com/delphi/clipper.php)
 - I need a way to visualize the result in 3D to judge how it looks, for the
   same reasons as above.
 - Above things should be done from purely the Gerber files I output (not from
   some internal representation) to check the export process. I can test the
   DRC/3D conversion with known-good stuff that I've already ordered in the
   past, so then everything is checked at least once.
 - I need some way to input coordinate data, because manually calculating
   everything, even procedurally, would be an absolute pain in the ass
   otherwise.

The first few points are handled by the tool in the gerber directory (unnamed
as of the time I'm writing this). It reads Gerber files, can (or will be able
to) output SVGs for quick verification and OBJ files for 3D verification in
Blender, and can do the basic DRC I mentioned. That just leaves coordinate
entry, and, well... I'm used to Blender, and Blender is super easy to script.
So why not.

Blend file data extraction
--------------------------

The data can be extracted from the `.blend` files by just running `make` here.
This runs `blend-export.py` within Blender for all primitives. That generates
`.blend.txt` files, which are straightforward, easy-to-parse text files.

Since these files are just glorified coordinate entry, a couple of rules need
to be adhered to for the scripts to make sense of them.

 - The function of a Blender object depends on the collection it is in. These
   collections roughly correspond to the Gerber layers of a PCB. These layers
   are:

    - `Ctop`: top-side components;
    - `GTO`: top overlay;
    - `GTS`: top soldermask opening;
    - `GTL`: top copper;
    - `G1`: inner copper, just below top;
    - `G2`: inner copper, just above bottom;
    - `GBL`: bottom copper;
    - `GBS`: bottom soldermask openings;
    - `GBO`: bottom overlay;
    - `Cbottom`: bottom-side components;
    - `Mill`: mill data & board outline;
    - `Drill`: drill data;
    - `Acrylic.Display.Cut`: laser cutting data for the display sheet;
    - `Acrylic.Highlight.Cut`: laser cutting data for the highlight sheet;
    - `Acrylic.Front.Cut`: laser cutting data for the front sheet;
    - `Acrylic.Front.Engrave`: engraving data for the front sheet.

   Refer to the README file in mainboard for more information on the acrylic
   sheets.

   An object may be linked in multiple collections at once to easily get the
   same shape on multiple Gerber layers.

 - The following object types are supported:

    - Linear interpolations & flashes (i.e. traces). These may be placed in all
      layers except Drill, Ctop, and Cbottom. They are represented as mesh
      objects. The object center must be at the origin, with no transformation
      applied. A single solidify operator must be present, with mode complex,
      boundary round, offset 0, and the thickness set to the desired trace
      thickness. The exporter only uses vertices and edges with Z=0, but these
      verts/edges are extruded downward to make the thickness operator work,
      allowing you to see more-or-less what you're doing in Blender.

    - Polygonal apertures to represent pads. These may be placed in all layers
      except Drill, Ctop, Cbottom, and Mill. They are represented as mesh
      objects as well, with the same requirements, except without the solidify
      operator. Each polygon becomes an aperture flash on the circuit board.
      The center for the flash is just the median. Note that these regions do
      not automatically receive soldermask openings; for that, the shape must
      be present on both the copper and respective soldermask layer. Soldermask
      expansion is post-processed for all shapes on the soldermask layer,
      however, so the shape can be the same on both.

    - Via/hole objects. These are represented as mesh objects in the Drill
      layer. The mesh data must consist of one or two circular polygons,
      centered around the object origin; the location of the origin is used for
      the drill center. The smaller of the two polygons, or the only polygon,
      represents the (finished) hole size. If there is a second polygon, the
      hole will be plated, and receive a circular pad of its size on all layers
      to form a via. Vias are tented unless a soldermask opening is manually
      added for them. If there is only one polygon, a non-plated hole is made.

    - Text objects. These may be placed in copper, mask, component, and GTO
      layers. Text should be centered; the object origin and orientation around
      Z are used for the location data. Rotation around the other axes should
      be 0. Text objects represent different things for the different layer
      types.

       - Copper layers: text objects represent ports for the primitives, to be
         connected via routing traces (note that Vcc and Gnd do not receive
         such ports, because they are connected via polygon pours on G2 and G1
         respectively).

       - Mask layers: text objects represent net labels for component pins,
         intended for electrical DRC.

       - Component layers: text objects represent references to components, to
         be placed in the 3D model and used for BOM generation. The components
         will be flipped horizontally in their local coordinate system when
         placed on the bottom side.

       - GTO layer: text object are converted to labels. X scale is used for
         the size; Y scale should be the same, as it is ignored. Be aware that,
         due to font differences, the size in Blender does not properly
         correspond to the actual size. Some replacements are made in the text:
          - `#REVISION` is replaced with the short git hash;
          - `#VERSION` is replaced with the latest tag; and
          - `#DATE` is replaced with an ISO 8601 datestamp.

 - Objects not within the classes above are ignored, and may thus be used for
   notes.

 - Five type of net labels are distinguished by a symbol prefix:

    - no prefix: global net. The name will appear in the final netlist as
      written.
    - `~`: global net connection point. The name will appear in the final
      netlist as written, and a global routing connection point is added to the
      primitive for that layer and coordinate.
    - `.` prefix: local net. The name will be prefixed with the instance name
      to make it unique.
    - `>` prefix: input port. Same as `.`, but the net is treated as an input
      of this primitive. A similarly-named input is expected in the VHDL model.
    - `<` prefix: output port. Same as `.`, but the net is treated as an output
      of this primitive. A similarly-named output is expected in the VHDL
      model.

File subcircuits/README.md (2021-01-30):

Circuit descriptions
====================

This directory describes the subcircuits built with the primitive NAND gates to
form the components of the clock. This is done via a netlist, annotated with
the information to do local routing as well.

Local placement and routing can only be done in an axis-aligned grid layout, of
which the gridpoints are described via the `columns` and `rows` directives.
These directives have a list of arguments of which each has the form
`<count>x<length><alignment>`, followed by one argument of the form `<ref>`,
where:

 - `<count>` indicates a number of rows/columns which are specified at once;
 - `<length>` specifies the width/height of the row/column in mm;
 - `<align>` specifies the alignment of the components w.r.t. the column/row,
   where `C` is centered, `L`/`T` is at the lower end of the axis, and `R`/`B`
   is at the upper end; and
 - `<ref>` is the grid position that should be at the subcircuit origin.

Note that columns and rows are specified from top-left to bottom-right, as you
would read a table. That means the Y axis is flipped as the grid coordinates
are converted to PCB coordinates. Note also that fractional grid positions can
be used, which will then be linearly interpolated.

Input and output pins of the subcircuit are placed using
`<in|out> <net> <col> <row>`, where `<net>` is a local netname and `<col>` and
`<row>` are zero-referenced grid coordinates.

Primitives or subcircuits are placed using
`prim <ref> <name> <angle> <col> <row> <pin>=<net> [...]`. Here:

 - `<ref>` is the name of the referenced primitive or subcircuit;
 - `<name>` is the instance name;
 - `<angle>` is a counterclockwise orientation of the primitive/subcircuit
   around its reference point in degrees;
 - `<col>` and `<row>` are zero-referenced grid coordinates;
 - `<pin>` is the name of a pin in the referenced primitive or subcircuit;
 - `<net>` is the net it should be connected to.

Finally, routing is instantiated using `route <col> <net> [...]`, where
`<col>` is the column for the (vertical) routing, and the nets are a list of
local nets routed in that column. Vertical routing is placed on the bottom
layer; horizontal routing is placed on the top layer. All routing is made
visible on the top overlay, using bridges for crossings and thick points for
connection points. Horizontal routing is placed from every pin in a net to
the column, and vertical routing is placed between the topmost and bottommost
connection.

In order to route between columns, special feedthrough primitives are needed.
These are placed as if they are gates. However, this implies that multiple
net names are needed for the same logical net; if both columns have the same
net name, too much horizontal routing would be placed; if they have a
different net name, the electrical DRC would start screaming. Therefore, nets
in subcircuits may be suffixed with an `*` followed by whatever. The router
will consider nets with different suffixes as different, but electrical DRC
will consider them to be aliases for the same electrical net.

During generation, all subcircuits are checked for basic DRC violations. These
are:

 - all true nets must have exactly one driver (either an input pin or a
   subcircuit/primitive output);
 - all true nets must drive at least one thing (either an output pin or a
   subcircuit/primitive input);
 - all net aliases must be associated with exactly one routing column;
 - different nets routed in a single column must not overlap.

Besides the regular Cartesian grid, subcircuits can also be placed on a polar
grid. In this case, the horizontal axis will be treated as an angle, and the
vertical access becomes the radius. The reference radius (along which the
horizontal coordinates are properly millimeters) is configured along with the
polar coordinate system. In polar coordinate systems, primitives are only
rotated around their reference; they are never warped. Subcircuits of
subcircuits however *are* warped.

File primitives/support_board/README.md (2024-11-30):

Support PCB
===========

The support PCB is done entirely in Blender with a single primitive. So, this
comprises the entire board. Its tasks are:

 - supply 5V power (4A) from mains with soft-start, proper UVLO/OVLO, and
   monitoring;
 - detect, isolate, and filter the grid frequency as a clock source for the
   discrete clock circuit;
 - drive the LEDs for the 7-segment displays and colons;
 - control LED PWM and voltage for the gate LEDs, flipflop LEDs, two
   synchroscope channels, and the microcontroller status LED;
 - provide support for a GPS module;
 - control everything using a microcontroller (Teensy LC).

Power supply and grid frequency
-------------------------------

### Mains circuitry

The mains circuitry is as follows.

```
   Screw terminals
       .-----.                5x20 T1A                                       class X 100nF
       |  _  |         L    .----------.     Lp                                  . .    Lc    ____   Lt    ____   Lo
 L ====| (-) |--------------|----------|-----o-------------o----------------o----| |-----o---|____|---o---|____|---.
       |  _  |              '----------'     |             |                |    ' '     |    47R     |    470R    |
 N ====| (-) |---------.                     |             | .-------~      |    ____    |            |            | LTV-816
       |  _  |         |                    .-._           '-|L             '---|____|---'            |         .--|-----~
PE ====| (-) |----.    |                    | / 275VAC       |  RAC20           1Meg HV              ---        | ---
       |     |    |    |                   _|/| 430VDC       |  -05SK            0.5W        SMBJ3V3 \ /        | / \ -->
       '-----'    |    |                    '-'            .-|N                                     .---'       | ---
                -----  |                     |             | '-------~                                |         '--|-----~
                 Gnd   |                     |             |                                          |            |
                       '---------------------o-------------o------------------------------------------o------------'
                       N
```

Between the following groups, minimum creepage is 4mm and minimum clearance is
1mm:

 - L;
 - Lp;
 - Lc, Lt, Lo, and N;
 - everything else.

The 430V varistor and 3V3 transzorb aim to protect the power supply and
optocoupler against spikes when the clock is plugged in. The fuse prevents a
failed-short varistor or safety capacitor from burning the house down. The
power supply has its own fuse built in, but that one's next to impossible to
get to. The 1Meg resistor acts as a bleed resistor for the 100nF capacitor,
draining it to ~30V within about 260ms.

Depending on input voltage and to some extent frequency (designed for
100-250VAC, 50-60Hz), the current through the capacitive dropper will peak at
somewhere between 3mA and 8mA.

The PE connection is kind of optional, since the clock does not have any
exposed metal that doesn't float. I'd always recommend connecting it anyway,
however. Especially while testing it's good not to blow everything up when you
touch something (non-live), regardless of whether it electrocutes you or not.

### Power supply

The main component of the power supply is an off-the-shelf module, the Recom
[RAC20-05SK](https://recom-power.com/pdf/Powerline_AC-DC/RAC20-K.pdf). This
module takes 85-264VAC at its input to provide an isolated 5V at 4A. It seemed
like a safe idea to me to use a module rather than to try to design a live SMPS
myself, especially for something that will be on for long periods of time.

To be safe, however, the module isn't directly connected to the power rail: it
goes through a [TPS26631](https://www.ti.com/lit/ds/symlink/tps2663.pdf)
hot-swap controller that provides undervoltage, overvoltage, and overcurrent
protection, soft-starts the power supply to prevent excessive capacitor inrush
current, and has a current monitor output that's tied to an ADC of the
microcontroller. Furthermore, the output of the module is kind of noisy, so
we'll add an LC filter.

```
                                                _ _ R_ser
                                   . - - - - - . _ _'- - - - - .
                                   .                31mΩ       .                                   Vcc
                                   .         TPS26631          .                                  -----
~------.    I                 L    .   .-------------------.   .                                    |
    V+ |---------^^^^^--------o--------| In            Out |-------o------------------------o-------o-------------o---------------------------o----------.
       |         100nH        |   1,2,3| ____              |18,    |                        |       |             |             '             |          |
       |         15mΩ         |     X--| Shdn              |19,   .-.                       |       | +           | +           '             |          |
 RAC20 |                      |      13|                   |20    | | 16k9                -----   -----         -----         - - - C_load    |        ----- 100nF
 -05SK |           .----------o--------| In_sys            |      | |                10uF -----    .-.  100uF    .-.  100uF   - - - ~340uF    |        -----
       |           |          |       6|                   |      '-'                       |     ' | `         ' | `           .             |          |
       |   100nF -----       .-.    X--| B_gate            |       |     ____      ____     |       |             |             .             |          |
    V- |--.      -----  16k9 | |      4|              Pgth |-------o----|____|----|____|----o-------o-------------o---------------------------)----------'
~------'  |        |         | |    X--| Drv               |16   Pgth    680  Pgl  5k11             |                                         |
          |        |         '-'      5|                   |                                        |                              .----------)----------.
          |        |          |        |                   |                                        |                              |          |          |
          |        |     UVLO o--------| UVLO              |                                        |                              |  4 .-._  | 5        |
          |        |          |       7|             Pgood |-------> Pgood                          |                              '----| - `-._         |
          |        |         .-.       |               ___ |17                                      |                                   |       `-._  1  |     ____
          |        |    1k27 | |       |               Flt |--X                                     |                                   | MCP6#01  _:----o----|____|----o----> Imon
          |        |         | |       |                   |15                        Imon.I        |                                 3 |      _.-'   Imon.B    1k      |
          |        |         '-'       |              Imon |-----------------------------o----------)-----------------------------------| +_.-'                         |
          |        |          |        |                   |14                           |          |                                   '-'   | 2                       |
          |        |      OVP o--------| OVP          Ilim |------------------.          |          |                                         |                         |
          |        |          |       8|                   |11         Ilim   |          |          |                                         |                       ----- 1uF
          |        |         .-.       |             dV/dT |-------.         .-.        .-.         |                                         |                       -----
          |        |    5k11 | |       |                   |10 dVdT| 100nF   | |        | |         |                                         |                         |
          |        |         | |    X--| Mode   Gnd        |     -----       | | 5k11   | | 16k9    |                                         |                         |
          |        |         '-'     12'-------------------'     -----       '-'        '-'         |                                         |                         |
          |        |          |                  |9,EP             |          |          |          |                                         |                         |
        -----    -----      -----              -----             -----      -----      -----      -----                                     -----                     -----
         Gnd      Gnd        Gnd                Gnd               Gnd        Gnd        Gnd        Gnd                                       Gnd                       Gnd
```

The LED controllers draw quite a bit of quiescent current. While the total
current drawn is still less than the maximum that the Teensy board can provide,
it's cutting it close. Therefore, a dedicated 3.3V LDO was added.

```
      Vcc                   3V3
     -----                 -----
       |    .-----------.    |
       o----| In    Out |----o
       |    | BD33FC0FP |    |
       |    |    Gnd    |    |
10uF -----  '-----------'  ----- 10uF
     -----       |         -----
       |         |           |
       |         |           |
     -----     -----       -----
      Gnd       Gnd         Gnd
```

This regulator is overkill; it should supply about 90mA, and can do 1A. The
footprint should be large enough that it shouldn't get too warm.

#### Noise filter

The LC filter is formed by the 100nH inductor, its 15mΩ series resistance,
the 31mΩ equivalent series resistance of the TPS26631's internal FET, the
electrolytic 100uF bulk capacitor, and the ~350uF total capacitive load on
the Vcc rail due to the decoupling capacitors all over the place. This gives
a cutoff frequency of 23.7kHz and a damping ratio of ~1.51.

#### Voltage-based protection

The UVLO, OVP, and Pgth thresholds in the TPS26631 are 1.2V rising, 1.12V
falling. With the selected resistors, this puts the trigger points at:

 - turn on above 4.38V, below 5.00V;
 - power good above 4.71V;
 - power bad below 4.30V;
 - turn off below 4.00V, above 5.47V.

The system may or may not recover from overvoltage, because the 5V happens to
end up at exactly the nominal voltage. However, it shouldn't need to, because
overvoltage should never happen in the first place. The power good signal is
just an I/O signal for the microcontroller, informing it that it should
probably reset everything if it's been low. The microcontroller's internal
pullup will be used.

Note that the resistor values were chosen to limit unique part count, with
minor sacrifices in the trip points. Hence also the usage of 680R and 5k11 in
series; both were already used elsewhere, but the desired resistance value
was not.

#### Current-based protection and monitoring

The 5k11 resistor programs the current limit of the TPS26631 to 3.52A. The
devices allows momentary overcurrent of 2x the set current (so 7.04A) for up
to 25ms, after which it will limit current at the set current for 162ms more.
When that timer expires, it will latch off until a power cycle. At 3x the set
current (10.56A), the device will ignore the timers, and latch off within
3.2us. Finally, at 45A or more, it will latch off within 1us.

The microcontroller can get a reading of the total current draw through the
Imon signal. At 3V3 ADC full scale, the current will be around 7A. The
datasheet mentions vaguely that the Imon signal should not have a capacitor,
but doesn't mention if this is because it affects the frequency response of
the monitoring signal (duh, that's the point), or if it affects internal
behavior. Therefore, to be safe, it's buffered by an opamp before it's
filtered. The microcontroller wants at most 5k source impedance anyway.

### Grid frequency filter

The following circuit is used to filter and amplify the grid frequency signal
from the optocoupler.

```
        3V3                     3V3        3V3                                                      Vcc
       -----                   -----      -----                                                    -----
         |                       |          |   100nF                                                |   100nF
        .-.                     .-.         |    . .                                                 |    . .
        | | 10k                 | | 10k     o----| |----.                                            o----| |----.
        | |                     | |         |    ' '    |                                            |    ' '    |
        '-'                     '-'         |         -----                                74LV1T125 |         -----
         |    ____    F1         |  4 .-._  | 5        Gnd                                     .-._  | 5        Gnd
       I o---|____|---o----------)----| - `-._                                                 |   `-._
         |    100k    |          |    |       `-._  1     F2    ____   F3    ____    O       2 |       `-._  4  ____
         |            |          |    | MCP6#01  _:--------o---|____|---o---|____|---o---------|A        Y_:---|____|---o---> f50hz
 LTV-816 |            |          |  3 |      _.-'          |    100R    |     10k    |       1 |__    _.-'   B  100R    |
~--------|--.         |        H o----| +_.-'              |            |            |      .--|OE_.-'                  |
     .  .'  |         |          |    '-'   | 2    ____    |            |            |      |  '-'   | 3                |
     |-'    |       ----- 100n   o----------)-----|____|---'    100nF -----      Readout/   |        |                ----- 330pF
 --> |      |       -----        |          |      16k9               -----      override   |        |                -----
     |>.    |         |         .-.         |                           |                   |        |                  |
     '  '.  |         |         | | 10k     |                           |                   |        |                  |
~--------|--'         |         | |         |                           |                   |        |                  |
         |            |         '-'         |                           |                   |        |                  |
         |            |          |          |                           |                   |        |                  |
       -----        -----      -----      -----                       -----               -----    -----              -----
        Gnd          Gnd        Gnd        Gnd                         Gnd                 Gnd      Gnd                Gnd
```

The circuit uses the 3V3 rail because it should be less noisy than Vcc, and to
prevent complexity for the readout & override signal to/from the
microcontroller.

The first RC filter stage combined with the Schmitt-trigger configuration of
the opamp should get rid of essentially all transients, and the second RC
filter should get rid of any remaining noise. The resulting signal can be
read by the microcontroller using the readout/override GPIO signal; the 10k
resistor limits current in case it wants to override. What follows is a basic
level shifter to 5V, with a slew-rate limiter similar to those used for the
NAND gates.

LED controllers
---------------

LED brightness and color control is managed by three excessively overpowered
[TLC6C5748QDCARQ1](https://www.ti.com/lit/ds/symlink/tlc6c5748-q1.pdf) LED
controllers. In a nutshell, each of these has 3x16 channels with independent
16-bit enhanced-spectrum PWM output, using a current sink with configurable
current (the product of 3x3-bit max current selection from 3.2mA to 31.9mA,
3x7-bit @ 10-100% per color group, and 48x7-bit @ ~26-100% per channel), with
stuck-at-high and stuck-at-low fault detection per channel.

Most of the 3x48 channels are used for the RGB LEDs of the 7-segment display;
it has 46 RGB LEDs, to be specific. The 47th channel is used for the
microcontroller status LED on the mainboard. Finally, the 48th channel controls
LED brightness of the synchrometer (current only), the gate LEDs
(current + PWM), and the flipflop LEDs (current + PWM) with its red, green, and
blue channels. This means that the color group dimming feature can't really be
used, but the current can still be set between 26% and 100% of the maximum
current.

The design point for the maximum current is 8.0mA (configuration 0b001): 6mA
for just the red color channel was found to be enough to read the display in
sunlight. Thus, the LED current can be configured between about 2mA and 8mA.
The rest is done via the also rather overkill 16-bit PWM.

### 7-segment display channel circuit

The regular 7-segment display LEDs are driven as follows. This circuit is
instanced 6 x 7 = 42 times.

```
               Vcc     Vcc          Vcc
              -----   -----        -----
                |       |            |
               .-.      |            |
      header   | | 100k |            |
         |     | |      |            |
         v     '-'      |            | 5   SN74LVC1G10DCKR
 _______        |       |    1 .---------..
 Segment )------o-------)------|A   Vcc    `.
________                |    3 |             \  _  4   A
Override ---------------)------|B           Y |(_)-----.
                        |    6 |             /         |
                        o------|C   Gnd    ,'          |
                        |      '---------''            | ASMB-KTF0-0A306
                        |            | 2        - - - -|- - - -
                        |            |         :   .---o---.   :
                        |            |         :   |   |   |   :
                        |            |         :  --- --- ---  :
                      ----- 100nF    |         :  \R/ \G/ \B/  :
                      -----          |         :  --- --- ---  :
                        |            |         :   |   |   |   :
                        |            |          - -|- -|- -|- -
                        |            |             |   |   |
                        |            |             |R  |G  |B
                        |            |             |   |   |
                      -----        -----        ---------------
                       Gnd          Gnd          1 RGB channel
                                                  (TLC6C5748)
```

The segment is thus controlled directly by the (active-low) signal from the
discrete circuit without microcontroller involvement, as long as override (an
output from the microcontroller) is inactive (high). When override is activated
however, all high-side segment drivers are on, regardless of the state of the
discrete circuit. The LEDs can then be individually controlled by the
microcontroller using the TLC6C5748.

The SN74LVC1G10DCKR can source up to 32mA (recommended) at 5V. As long as the
maximum current is configured correctly, at maximum brightness this current
would be 24mA, so that's fine.

This circuit should also allow the microcontroller to read out the state of the
segment signal, as long as override is inactive and at least one RGB channel
is on at the 33rd GSCLK cycle. This state is reflected in the LED open
detection flags.

The pullup resistor on the segment line ensures that the segment is off when
the support board is not connected to the mainboard, allowing it to be tested
independently.

Some segments share a single control line (ADn for seconds and minutes tens,
ADEGn for hours tens). For these segments, only one pullup resistor exists, but
the rest of the circuit is repeated. "Logically" speaking the NAND gates could
be "optimized away" because they perform the same logic function, but
electrically this would put too much load on them in the worst case.

### Colon LED circuit

The four colon dots are driven as follows.

```
              Vcc          Vcc
             -----        -----
               |            |
               |            |
               |            |
               |            |
               |      .-._  | 5  SN74LVC1G17DCKR
               |      |   `-._
________       |    2 |     __`-._  4     A
Override )-----)------|   _||    _:-----------.
               |      |      _.-'             |
               |      |  _.-'                 |
               |      '-'   | 3               | MB-KTF0-0A306
               |            |          - - - -|- - - -
               |            |         :   .---o---.   :
               |            |         :   |   |   |   :
               |            |         :  --- --- ---  :
             ----- 100nF    |         :  \R/ \G/ \B/  :
             -----          |         :  --- --- ---  :
               |            |         :   |   |   |   :
               |            |          - -|- -|- -|- -
               |            |             |   |   |
               |            |             |R  |G  |B
               |            |             |   |   |
             -----        -----        ---------------
              Gnd          Gnd          1 RGB channel
                                         (TLC6C5748)
```

This means that they are hardwired to always be on when the clock circuit is
in control of the display, and always off when the microcontroller is in
control. Off course the microcontroller can always turn individual segments
*off*, but it can't turn them on without also turning the colons off.
Basically, this is a hardwired anti-cheating measure.

### Microcontroller status LED circuit

The microcontroller status LED is driven trivially.

```
       Vcc
      -----
        |
        ~   <-- header
        |
        |
        | MB-KTF0-0A306
 - - - -|- - - -
:   .---o---.   :
:   |   |   |   :
:  --- --- ---  :
:  \R/ \G/ \B/  :
:  --- --- ---  :
:   |   |   |   :
 - -|- -|- -|- -
    |   |   |
    ~   ~   ~   <-- header
    |   |   |
    |R  |G  |B
    |   |   |
 ---------------
  1 RGB channel
   (TLC6C5748)
```

### Gate and flipflop LED drive voltage circuits

The control voltage for the gate and flipflop LEDs is generated as follows.

```
       Vcc              Vcc                                Vcc
      -----            -----                              -----
        |                |                                  |
        |                |     . .                          |
        |                o-----| |------.                  .-.
        |                |     ' '      |                  | | 10k
        |                |    100nF   -----                | |
       .-.               |             Gnd                 '-'
  470R | |               |                                  |
       | |               |          F         ____          |
       '-'    .----------)--------------o----|____|---------o-----( Vled
        |     |          |              |     10k           |
        |     |  4 .-._  | 5    100nF -----               2 |
        |     '----| - `-._           -----             .  .'
        |          |       `-._  1  O   |     ____    1 |<'
        |          | MCP6#01  _:--------o----|____|-----|   MMBT4403WT1G
        |   A    3 |      _.-'                 1k    C  |-.
        o----------| +_.-'                              '  '.
        |          '-'   | 2                              3 |R
        |                |                                  |
 ---------------         |       # = 0 or L                .-.
 1 color channel         |                                 | | 100R
   (TLC6C5748)           |                                 | |
                         |                                 '-'
                         |                                  |
                         |                                  |
                       -----                              -----
                        Gnd                                Gnd
```

The current from the TLC6C5748 channel is converted to a voltage by the 470R
resistor, varying between about 1.2V and 4.1V when the channel is on based on
the dot correction value, and 5V when the channel is off. The remainder of
the circuit simply serves to mirror this voltage at Vled, regardless of the
amount of current drawn from it. The transistor is in a voltage follower
configuration, with the base and collector resistors only serving to limit
currents in fault conditions, and the 10k resistor only serving to define the
Vled voltage when the mainboard is not connected. The MCP6001 combined with
the 10k/100nF RC circuit serves to calibrate the Vbe voltage drop of the
transistor out; this voltage drop depends somewhat on the amount of current
drawn otherwise, which in turn would depend on the amount of LEDs that are
on. The RC circuit serves mostly to ensure stability of the opamp. It's
entirely possible that the circuit will work just fine in practice without
any of the 100R/1k/10k resistors or the 100nF capacitor in the filter, in
which case they can just be omitted/bridged.

### Synchroscope drive voltage circuits

Because only one (color) channel remains, while we need two synchroscope
control voltages, some shenanigans are needed here.

```
                     Vcc                Vcc           Vcc                Vcc
                    -----              -----         -----              -----
                      |                  |             |                  |
                      |                  |             |                  |
                     .-.                .-.           .-.                .-.
                     | | 10k            | | 10k       | | 10k            | | 10k
                     | |                | |           | |                | |
                     '-'                '-'           '-'                '-'
                      |                  |             |                  |          _
                      |                  |             o------------------)-----( V1  \_ Output
     PWM A @ 5V ------o A                o-------------)------------------)-----( V2 _/  voltages
 (microcontroller)    |                  |             |                  |
                      |                2 |             | 2                |
                      |              .  .'             '.  .              |
      Vcc             |    ____    1 |<'                 '>| 1    ____    |
     -----            '---|____|-----|   2x MMBT4403WT1G   |-----|____|---o------ PWM B @ 5V
       |                   100k   AR |-.                 .-| BR   100k         (microcontroller)
       |                             '  '.             .'  '
      .-.                              3 |             | 3
 470R | |                                '------o------'
      | |                                       |M
      '-'                                     2 |
       |                                    .  .'
       |   C                              1 |<'
       o------------------------------------|   MMBT4403WT1G
       |                                    |-.
       |                                    '  '.
---------------                               3 |R
1 color channel                                 |
  (TLC6C5748)                                  .-.
                                               | | 100R
                                               | |
                                               '-'
                                                |
                                                |
                                              -----
                                               Gnd
```

The intended mode of operation is that the TLC6C5748 output is always on; it is
only used as a current-mode DAC. As in the Vled circuit, a 470R resistor is
used to convert it to a voltage between 1.2V and 4.1V. The bottom transistor
mirrors this voltage at the M net, with a 100R series resistor for protection.
The remaining two transistors are configured as switches controlled by the
microcontroller; they allow the microcontroller to PWM the two channels
individually. The 10k pullup resistors only serve to define the output voltages
when the mainboard is not connected.

Note that an opamp isn't necessary for the synchrometer, because during normal
operation, there is always only one LED on per channel. Therefore, the current
sourced by V1 and V2 is approximately constant for a given voltage.

### GSCLK and other support circuitry

The three LED controllers are connected as follows.

```
                          3V3       Vcc                            3V3       Vcc                            3V3       Vcc
                         -----     -----                          -----     -----                          -----     -----
                           |         |                              |         |                              |         |
                           |         |                              |         |                              |         |
                           |       ----- 10uF                       |       ----- 10uF                       |       ----- 10uF
                           |       -----                            |       -----                            |       -----
                           |         |                              |         |                              |         |
             .       . .   |   . .   |   .            .       . .   |   . .   |   .            .       . .   |   . .   |   .
         Gnd |---o---| |---o---| |---o---| Gnd    Gnd |---o---| |---o---| |---o---| Gnd    Gnd |---o---| |---o---| |---o---| Gnd
             '   |   ' '   |   ' '   |   '            '   |   ' '   |   ' '   |   '            '   |   ' '   |   ' '   |   '
                 |  100nF  |  100nF  |                    |  100nF  |  100nF  |                    |  100nF  |  100nF  |
                 |29       |54       |56                  |29       |54       |56                  |29       |54       |56
              .-------------------------.              .-------------------------.              .-------------------------.
              | Gnd       Vcc       Gnd |              | Gnd       Vcc       Gnd |              | Gnd       Vcc       Gnd |
            1 |                         | 28         1 |                         | 28         1 |                         | 28
         .----| SIN    TLC6C5748   SOUT |--------------| SIN    TLC6C5748   SOUT |--------------| SIN    TLC6C5748   SOUT |-----.
         |    |                         |     SIO1     |                         |     SIO2     |                         |     |
         |    | SCLK      LAT     GSCLK |              | SCLK      LAT     GSCLK |              | SCLK      LAT     GSCLK |     |
         |    '-------------------------'              '-------------------------'              '-------------------------'     |
 SIN ----'        |2       |3       |55                    |2       |3       |55                    |2       |3       |55       |
SCLK -------------o--------)--------)----------------------o--------)--------)----------------------'        |        |         |
 LAT ----------------------o--------)-------------------------------o--------)-------------------------------'        |         |
SOUT -------------------------------)----------------------------------------)----------------------------------------)---------'
                                    |                                        |                                        |
                         Hours      |                            Minutes     |                            Seconds     |
                                    |                                        |                                        |
                                    '----------------------------------------o----------------------------------------'
                                                                             |
                                                                             |
                                                     3V3                     |
                                                    -----                    |
                                               100nF  |                      |
                                                . .   |                      |
                  3V3                       .---| |---o                      |
                 -----                      |   ' '   |                      |
                   |                      -----       |                      |
                   o-----------.           Gnd  .-._  | 5  SN74LVC1G17DCKR   |
                   |           |                |   `-._                     |
             100nF |       .-------.          2 |     __`-._  4    ____      |
                 -----     | 32MHz |------------|   _||    _:-----|____|-----'
                 -----     '-------'            |      _.-'        47R
                   |           | ECS-3225MV-    |  _.-'
                   o-----------' 320-BN-TR      '-'   | 3
                   |                                  |
                 -----                              -----
                  Gnd                                Gnd
```

Note that they run on 3V3 rather than the standard Vcc (5V). The current sinks
can handle voltages up to 10V regardless of supply voltage, so this is fine,
and saves a few level shifters for the microcontroller.

The oscillator connects to the GSCLK inputs via a buffer, because the trace and
input capacitance would otherwise be greater than what it can drive (max is
15pF, and the trace alone is about that much already).

### Connection table

First TLC6C5748 in daisy chain:

 - OUTx0: hours, tens, segment F
 - OUTx1: hours, tens, segment A
 - OUTx2: hours, units, segment A
 - OUTx3: hours, units, segment B
 - OUTx4: hours, tens, segment G
 - OUTx5: hours, tens, segment B
 - OUTx6: hours, units, segment F
 - OUTx7: hours, units, segment G
 - OUTx8: hours, tens, segment E
 - OUTx9: hours, tens, segment D
 - OUTx10: hours, units, segment D
 - OUTx11: hours, units, segment C
 - OUTx12: hours, tens, segment C
 - OUTx13: colon between minutes and hours, upper segment
 - OUTx14: colon between minutes and hours, lower segment
 - OUTx15: hours, units, segment E

Second TLC6C5748 in daisy chain:

 - OUTx0: minutes, tens, segment F
 - OUTx1: minutes, tens, segment A
 - OUTx2: minutes, units, segment A
 - OUTx3: minutes, units, segment B
 - OUTx4: minutes, tens, segment G
 - OUTx5: minutes, tens, segment B
 - OUTx6: minutes, units, segment F
 - OUTx7: minutes, units, segment G
 - OUTx8: minutes, tens, segment E
 - OUTx9: minutes, tens, segment D
 - OUTx10: minutes, units, segment D
 - OUTx11: minutes, units, segment C
 - OUTx12: minutes, tens, segment C
 - OUTR13: brightness control for flipflop status LEDs
 - OUTB13: brightness control for gate status LEDs
 - OUTG13: brightness control for synchroscope LEDs (analog only, PWM done by
   microcontroller)
 - OUTx14: microcontroller status LED
 - OUTx15: minutes, units, segment E

Third TLC6C5748 in daisy chain:

 - OUTx0: seconds, tens, segment F
 - OUTx1: seconds, tens, segment A
 - OUTx2: seconds, units, segment A
 - OUTx3: seconds, units, segment B
 - OUTx4: seconds, tens, segment G
 - OUTx5: seconds, tens, segment B
 - OUTx6: seconds, units, segment F
 - OUTx7: seconds, units, segment G
 - OUTx8: seconds, tens, segment E
 - OUTx9: seconds, tens, segment D
 - OUTx10: seconds, units, segment D
 - OUTx11: seconds, units, segment C
 - OUTx12: seconds, tens, segment C
 - OUTx13: colon between seconds and minutes, upper segment
 - OUTx14: colon between seconds and minutes, lower segment
 - OUTx15: seconds, units, segment E

Microcontroller and GPS
-----------------------

The clock is controlled using a microcontroller board. This is a little more
expensive than just using a discrete microcontroller, but compared to the rest
of the clock's pricetag it shouldn't really matter too much. Convenience was
more important to me than price.

Originally, the clock used a [Teensy LC](https://www.pjrc.com/teensy/teensyLC.html).
However, they've since reached end of life (and were unobtanium for a long time
anyway, thanks covid), so now there's a revision that uses a Raspberry Pi Pico
W instead. This is now the default, but if you want the original Teensy variant,
you can rename `support_board_teensy.blend` to `support_board.blend`.

In both cases, the board is powered by 5V, but the I/O voltage is 3V3, and the
pins are not 5V-tolerant. Therefore, signals going to and coming from the
5V clock circuitry need to be translated up and down. This is done using
74LV1T125s, with the /OE pin tied to Gnd. In the Teensy's case, the VUSB trace
is to be cut, so it will operate from the local 5V rail rather than USB power.
For the Pico W, there is no such sanity, and instead we need a diode from 5V to
VSYS to avoid USB from trying to power the clock. The circuitry is otherwise
trivial.

GPS connectivity is also achieved with a daughterboard. The connector uses the
pinout of an ATGM336H: 5V, Gnd, TX, RX, PPS. Similar to the microcontroller
boards, this board has its own 3V3 LDO that the I/Os are referenced to.
Therefore, no level shifters are included here.

The Pico W's pinout is as follows.

 - GP0: hours configuration increment switch enable (`hcfg.Ien.L`)
 - GP1 (SPI0 CS): display data latch control (`disp.LAT`)
 - GP2 (SPI0 SCK): display clock (`disp.SCLK`)
 - GP3 (SPI0 TX): display data input (`disp.SIN`)
 - GP4: hours configuration increment switch readout (`hcfg.Isw.L`)
 - GP5: automatic configuration, enable (`cfg.Ren.L`)
 - GP6: automatic configuration, increment hours (`hcfg.Inc.L`)
 - GP7: power good input, GPIO pullup needed (`pwr.Pgood`)
 - GP8 (SPI1 RX): mainboard I/O expander read data (`uc.MISO.L`)
 - GP9 (SPI1 CS): mainboard I/O expander chip select (`uc.CS.L`)
 - GP10 (SPI1 SCK): mainboard I/O expander clock (`uc.SCK.L`)
 - GP11 (SPI1 TX): mainboard I/O expander write data (`uc.MOSI.L`)
 - GP12 (UART0 TX): GPS configuration output (`gps.U2G`)
 - GP13 (UART0 RX): GPS data input (`gps.G2U`)
 - GP14 (input capture?): PPS signal from the GPS (`gps.PPS`)
 - GP15 (input capture?): 50/60Hz readback & override (`f50hz.O`)
 - GP16 (SPI0 RX): display fault data output (`disp.SOUT`)
 - GP17: minutes configuration increment switch readout (`mcfg.Isw.L`)
 - GP18: minutes configuration increment switch enable (`mcfg.Ien.L`)
 - GP19: automatic configuration, increment minutes (`mcfg.Inc.L`)
 - GP20: display override (inverted, `override_n.L`)
 - GP21 (PWM): synchroscope PWM channel B (`sync.BL`)
 - GP22 (PWM): synchroscope PWM channel A (`sync.AL`)
 - GP26: mainboard I/O expander interrupt request (`uc.IRQ.L`)
 - GP27 (ADC1): current monitor ADC (`pwr.Imon`)
 - GP28 (ADC2): LDR (`uc.LDR`)

The Teensy's pinout is as follows.

 - Arduino 0, used as MOSI1: display data input (`disp.SIN`)
 - Arduino 1, used as MISO1: display fault data output (`disp.SOUT`)
 - Arduino 2: minutes configuration increment switch readout (`mcfg.Isw.L`)
 - Arduino 3, usable as PWM or input capture for FTM2 channel 0: 50/60Hz
   readback & override (`f50hz.O`)
 - Arduino 4, usable as input capture for FTM2 channel 1: PPS signal from the
   GPS (`gps.PPS`)
 - Arduino 5: minutes configuration increment switch enable (`mcfg.Ien.L`)
 - Arduino 6, possibly used as CS1: display data latch control (`disp.LAT`)
 - Arduino 7, RX3: GPS data input (`gps.G2U`)
 - Arduino 8, TX3: GPS configuration output (`gps.U2G`)
 - Arduino 9: automatic configuration, increment minutes (`mcfg.Inc.L`)
 - Arduino 10, possibly used as CS0: mainboard I/O expander chip select
   (`uc.CS.L`)
 - Arduino 11, used as MOSI0: mainboard I/O expander write data (`uc.MOSI.L`)
 - Arduino 12, used as MISO0: mainboard I/O expander read data (`uc.MISO.L`)
 - Arduino 13 (LED): display override (non-inverted, `override.L`)
 - Arduino 14, used as SCK0: mainboard I/O expander clock (`uc.SCK.L`)
 - Arduino 15: mainboard I/O expander interrupt request (`uc.IRQ.L`)
 - Arduino 16, used as FTM1 PWM: synchroscope PWM channel B (`sync.BL`)
 - Arduino 17, used as FTM1 PWM: synchroscope PWM channel A (`sync.AL`)
 - Arduino 18, automatic configuration, increment hours (`hcfg.Inc.L`)
 - Arduino 19, hours configuration increment switch readout (`hcfg.Isw.L`)
 - Arduino 20, used as SCK1: display clock (`disp.SCLK`)
 - Arduino 21: hours configuration increment switch enable (`hcfg.Ien.L`)
 - Arduino 22, used as analog 8: current monitor ADC (`pwr.Imon`)
 - Arduino 23: power good input, GPIO pullup needed (`pwr.Pgood`)
 - Arduino 26: automatic configuration, enable (`cfg.Ren.L`)

For the Teensy variant, the LDR was an afterthought. I ended up 3D-soldering a
small circuit with a GL5528 LDR on top of the Teensy for it, using pin 24/A10.
The LDR is connected between 0V and A10, with a 220k pullup resistor from A10
to 3V3, facing down out from the support board cover/housing using some
creative soldering and shrinkwrap. The circuit lets the clock detect ambient
light conditions, and dim itself accordingly.

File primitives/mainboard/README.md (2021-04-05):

Manually placed features of the main PCB
========================================

Includes the board outline, screw holes, etc., and everything else that isn't
generated. This also includes the microcontroller-controlled circuitry, i.e.
the Vled routing, the buttons (including the manual reset button), the
microcontroller status LED, and the synchroscope LEDs.

Mechanical notes
----------------

The mainboard primitives define the shapes of four things: the PCB (of course),
a 5+/-0.9mm thick white acrylic sheet named "Highlight", a 3+/-0.7mm black
acrylic sheet named "Display", and a 3+/-0.7mm transparent acrylic sheet named
"Front". The design is specifically engineered for a local laser cutting shop,
laserbeest.nl. To have them cut elsewhere, you probably need to do some file
conversion work, and might have to change some dimensions here and there (the
2.35mm holes in particular).

They PCB and acrylic sheets are layered as follows:

```
      ⌀ 2.35+0.2                                            ⌀ 2.35+0.2
       |<--->|                   Outside                     |<--->|
       |     |                                               |     |
       |     |                                               |     |
.------. - - .-----------------------------------------------. - - .-----------  ------
|      |     |                                               |     |                 ^
|      |     |              Front (transparant)              |     |              3.0±0.7
|      |     |                              Engraving --> ___|     |___________      v
:------' - - '.----------------.-----------.----------..--==.' - - '.==========  ----------------
| \ \ |       | \ \ \ \ \ \ \ \|           |\ \ \ \ \ ||X X |       |X X X X X       ^         ^
|\ \ \|       |\ \ \ \ \ \ \ \ |           | \ \ \ \ \|| X X|       | Display X   3.0±0.7      |
| \ \ |       | \ \Highlight\ \|           |\ \ \ \ \ ||X X |       |X X X X X       v      5.0±0.9
|\ \ \|       |\ \ \ \ \ \ \ \ | Top side  | \ \ \ \ \|'----' - - - '----------  ------        |
| \ \ |       | \ \ \ \ \ \ \ \|   .--.    |\ \ \ \ \ |     |       |                          v             v
:-----: - - - :-----------------------------------------. - | - - - | - - - - -  ------------------------------
| / / |       | / / / / / PCB / / / / / / / / / / / / / |   |       |                                     1.6±0.1
'-----' - - - '-----------------------------------------' - | - - - | - - - - -  ------------------------------
      |       |   '--'        '--'           '--'           |       |                                      ^
      |       |                Bottom side                  |       |
      |<----->|                                             |<----->|
      ⌀ 3.2±0.2                  Inside                     ⌀ 3.2±0.2
        (14x)                                                  (2x)
```

The highlight sheet serves as a spacer between the front sheet and the PCB, and
to highlight the borders around the many subcircuits. The tallest component on
the front side of the PCB is 4mm high (the 50/60Hz jumpers), so the spacing
must be at least 4mm. The tolerances on sheet thickness at Laserbeest are quite
abysmal; a nominally 5mm thick sheet is just barely thick enough in the worst
case.

The front sheet serves to protect the system from dust and the likes, and allows
it to be cleaned easily. It is also used to form good-looking displays through
engraved surfaces: these surfaces become opaque but translucent, scattering the
LED light and making the segment shapes almost invisible when the LEDs are off.
Note however that the engraved side must be facing inside for this to work,
thus the drawing for the front sheet is mirrored.

The display sheet serves as a black backing for the engraved surfaces on the
front to increase contrast, and the display sheet is intentionally a bit larger
than the engraved surface, thus outlining the display with a thick, black line.

It'd be great if the display and highlight sheets would have a nice press fit,
but this is not doable with a laser. Instead, there is a gap between them of
the thickness of the laser, which seems to be about 0.1 to 0.2mm for
Laserbeest. The 3D-printed part underneath the display might be tweakable to
fit snugly, however.

The whole thing is assembled using a few M3 screws. They screw in from the
back, mating with tapped holes in the front sheet. Being able to see the end
of the screws isn't ideal, but doesn't look *too* too bad, and it beats gluing
everything together. The correct drill size for an M3 tap is 2.5mm, but we need
to account for laser thickness; experimentally, a 2.3mm hole was found to be
uncomfortably tight to tap (lots of squeeking and mild cracking noises, though
the sheet remained visibly intact), while a 2.4mm hole was still slightly
oversized. Thus, 2.35mm was chosen.

The PCB (and the 3D-printed shell structure on the back) screws into the front
panel using 14 screws; 12 on the border, and 2 diagonally across the display.
The highlight sheet is probably quite weak due to all the cutouts, so it's
important for structural integrity that it's firmly clamped between the front
sheet and the PCB. The display sheet and 3D-printed spacer between it and the
support PCB are mounted to the front directly 2 more screws, and are only
fixed this way; this is necessary to clamp everything down to the front sheet
properly despite the large sheet thickness tolerances, which in turn is
necessary for aforementioned structural integrity and to minimize any gap
between the engraved surface on the front sheet and the display sheet.

Support board interface
-----------------------

The mainboard connects to the support board through five extra tall but
otherwise standard 2.54mm 16-pin headers; TSW-108-12-T-S-RA headers on the
mainboard, mating with SSQ-108-01-T-D sockets on the support board, leading
to a board-to-board distance of about 27.5mm when the headers are soldered
flush to the board. The headers surround the display area, so they are just
barely covered by the display sheet, but can still be through-hole.

The headers carry the following signals:

 - 5V power and ground;
 - the 50/60Hz grid-based clock signal;
 - display data (as the LEDs for the time display are on the support board);
 - SPI/I2C+IRQ interface to a 16-bit I/O expander on the mainboard;
 - microcontroller interface for the hours and minutes configuration; and
 - LED control voltages for the flipflop LEDs, NAND gate LEDs, synchroscope,
   and microcontroller status RGB LED.

I/O expander
------------

To limit the amount of signals that need to pass through the headers, an I/O
expander is added to the mainboard. This can be either an MCP23017T (I2C) or an
MCP23S17T (SPI), though SPI must be used with the current control board (or the
I2C protocol would need to be bit-banged). The SPI/I2C pins are pulled high by
10k resistors to allow the mainboard to work without support board while
testing, without noise causing all kinds of stuff to happen. The address and
reset pins are pulled up via a 1k resistor. Only the INTA pin is forwarded to
the support board. The GPIO pinout is as follows:

 - GPA0: mode button, active low with no hardware debouncing.
 - GPA1: down button, active low with no hardware debouncing.
 - GPA2: up button, active low with no hardware debouncing.
 - GPA3: synchroscope H6.
 - GPA4: synchroscope H4.
 - GPA5: synchroscope H2.
 - GPA6: synchroscope H5.
 - GPA7: synchroscope H3.
 - GPB0: synchroscope L6.
 - GPB1: synchroscope L5.
 - GPB2: synchroscope L4.
 - GPB3: synchroscope L3.
 - GPB4: synchroscope L2.
 - GPB5: synchroscope L1.
 - GPB6: synchroscope H1.
 - GPB7: reset readout/override.

Reset circuit
-------------

The mainboard includes the following reset conditioning circuit.

```
                    Vcc          Vcc                                           Vcc
                   -----        -----        100nF                  100nF     -----
                     |            |           . .                    . .        |
                    .-.           o-----------| |-----------o--------| |--------o
               100k | |           |           ' '           |        ' '        |
                    | |     .-._  | 5  SN74LVC1G17DCKR      |             .-._  | 5  SN74LVC1G17DCKR
                    '-'     |   `-._                        |             |   `-._
          ____       |    2 |     __`-._  4  B   ____       |      O    2 |     __`-._  4  B   ____
  .------|____|------o------|   _||    _:-------|____|------)------o------|   _||    _:-------|____|------o------ Arn
  |        1k        |      |      _.-'          10k        |      |      |      _.-'          100        |
  o                  |      |  _.-'                         |      |      |  _.-'                         |
   \  Manual   1uF -----    '-'   | 3                       |      |      '-'   | 3                     ----- 330pF
  o \ reset        -----          |                         |      |            |                       -----
  |                  |            |                         |      |            |                         |
  |                  |            |                         |      |            |                         |
-----              -----        -----                     -----    |          -----                     -----
 Gnd                Gnd          Gnd                       Gnd     |           Gnd                       Gnd
                                                                   |
                                                           From GPIO expander
```

The circuit provides a reset pulse at least 35ms in length at powerup, assuming
Vcc rises fast enough. The circuit can be reset manually by pushing the manual
reset button. Furthermore, the microcontroller can read the state of the reset
circuit and override it in either direction using the GPIO expander. The RC
circuit at the end is a copy of the one used for "fast" NAND gates; it limits
the slew rate to prevent ringing.

The reset signal is not synchronized with the incoming clock in any way.
Therefore, weird stuff might happen when the reset is released at the wrong
time. However, all flipflop circuitry should automatically recover from
invalid states, and the odds of the reset being timed this way are extremely
low during normal operation, as the incoming clock frequency is only 50/60 Hz.

The reset circuit is depicted on the silkscreen as well, although the
decoupling capacitors, switch current limit resistor, and RC filer are omitted.

Clock circuit
-------------

While a clock generation circuit is depicted on the silkscreen, this circuit
is not implemented on the mainboard for the following reasons:

 - the required anti-creepage slots would be ugly;
 - the high-voltage components are large and through-hole, which would again be
   ugly;
 - strong electric fields and the relatively high temperatures of some of the
   parts might cause the circuit board to blacken; and
 - when the cover is off, you don't want surprise electric shocks.

Instead, the clock signal comes straight from the support board. It does
however have a 10k pullup resistor to properly define the signal when the
support board is not connected.

Microcontroller user interface
------------------------------

The microcontroller is controlled using three pushbuttons, and can provide
visual feedback using a dedicated RGB LED next to these buttons. It can of
course also override the value displayed on the synchroscope, and it can
override all display segments on, at which point it can control them
individually using the LED controllers. Thus, a menu structure can be
programmed into it.

The buttons are marked Up, Down, and Mode, the former sharing a single
3D-printed cap. A short press of mode should cycle through the various
configuration parameters, such as time zone and DST setup for GPS
synchronization and LED color/brightness. When any configuration parameter
is active, the display content is overridden to show an abbreviation of the
parameter name and its value; this override is visible by way of the four
colon LEDs turning off (this should be hardwired). The clock should always
return to normal operation after a timeout.

The configuration parameters might be:

 - `br   0`..`br 100` for overall LED brightness control;
 - `GPS  0`..`GPS  1` for enabling or disabling daily GPS synchronization at
   3:00;
 - `nS xxx` depicts number of GPS satellites in view (up/down does nothing);
 - `utc-12`..`utc 12` for timezone setup;
 - `dSt  0`..`dSt  1` to enable/disable automatic DST switching (the DST
   switching date logic would need to be programmed into it via Arduino
   however);
 - `Fb   0`..`Fb 100` for flipflop LED brightness;
 - `Gb   0`..`Gb 100` for NAND gate LED brightness;
 - `Sb   0`..`Sb 100` for synchroscope LED brightness;
 - `db   0`..`dB 100` for setting display and status LED brightness;
 - `dh   0`..`dB 359` for setting display hue;
 - `dS   0`..`dB 100` for setting display saturation.

Letters on 7-segment displays are a bit awkward, but (most) are possible:

```
  b      c      d      F      G      h      n      P      r     S      t      u
                      ---    ---                  ---          ---
|                 |  |      |      |             |   |        |      |
 ---    ---    ---    ---           ---    ---    ---    ---   ---    ---
|   |  |      |   |  |      |   |  |   |  |   |  |      |         |  |      |   |
 ---    ---    ---           ---                               ---    ---    ---
```

A long press of the mode switch should toggle the microcontroller altogether.
When the microcontroller is powered down, all outputs to the clock circuit
are high, the microcontroller status LED is off, and the synchroscope is off.
Only LED brightness setup is retained. The former also means that
auto-increment control of the hours/minute configuration circuit is disabled.
Thus, in this state, the discrete clock circuit is operating without any
"cheating" going on.

Synchroscope
------------

A sort of synchroscope is included (mostly as filler) to show the difference
between the grid frequency and the supposedly much more stable GPS clock.
Hopefully it'll be possible to see load fluctuations in the electrical grid by
this means. For those unaware, the electrical grid "communicates" the current
discrepancy between power consumption and production via minute frequency
fluctuations. When consumption is greater than production, all synchronous
generators physically slow down, thus reducing grid frequency, which is then
detected and results in an increase in production in all power plants
simultaneously merely by regularing the RPM of the generators (and vice versa).
In Europe, the nominal instantaneous frequency is about +/-0.05Hz. That means
the clock will run 1ms slow or fast each second, thus one "revolution" of the
synchrometer per ms of phase shift between the grid and GPS signal is probably
good.

The synchroscope is built using 30 LEDs arranged in an unusual multiplexing
circuit that allows these LEDs to be controlled with only 12 slow GPIO pins and
two DAC/PWM channels, such that any two (modulo) consecutive LEDs can be on
simultaneously with independent dimming for antialiasing and brightness control.
The circuit for this is as follows.

```
         H1                      H2                      H3                      H4                      H5                      H6
          |                       |                       |                       |                       |                       |
          |                       |                       |                       |                       |                       |
         .-.                     .-.                     .-.                     .-.                     .-.                     .-.
         | | Depends             | | Depends             | | Depends             | | Depends             | | Depends             | | Depends
         | | on LED              | | on LED              | | on LED              | | on LED              | | on LED              | | on LED
         '-'                     '-'                     '-'                     '-'                     '-'                     '-'
          |                       |                       |                       |                       |                       |
          |                       |                       |                       |                       |                       |
          |H1R                    |H2R                    |H3R                    |H4R                    |H5R                    |H6R
          |                       |                       |                       |                       |                       |
          | 2                     | 2                     | 2                     | 2                     | 2                     | 2
          '.  .                   '.  .                   '.  .                   '.  .                   '.  .                   '.  .
            '>| 1                   '>| 1                   '>| 1                   '>| 1                   '>| 1                   '>| 1
MMBT4403WT1G  |-----.   MMBT4403WT1G  |-----.   MMBT4403WT1G  |-----.   MMBT4403WT1G  |-----.   MMBT4403WT1G  |-----.   MMBT4403WT1G  |-----.
            .-|     |               .-|     |               .-|     |               .-|     |               .-|     |               .-|     |
          .'  '     |             .'  '     |             .'  '     |             .'  '     |             .'  '     |             .'  '     |
          | 3       |             | 3       |             | 3       |             | 3       |             | 3       |             | 3       |
          |         |             |         |             |         |             |         |             |         |             |         |
V1 -------)---------o-------------)---------)-------------)---------o-------------)---------)-------------)---------'             |         |
V2 -------)-----------------------)---------o-------------)-----------------------)---------o-------------)-----------------------)---------'
          |                       |                       |                       |                       |                       |
          |H1L                    |H2L                    |H3L                    |H4L                    |H5L                    |H6L
          |                       |                       |                       |                       |                       |
          '-o---------------------)-o---------------------)-o---------------------)-o---------------------)-.                     |
            |   .-----------------o-)---o-----------------)-)---o-----------------)-)---o-----------------)-)---.                 |
            |   |   .---------------)---)---o-------------o-)---)---o-------------)-)---)---o-------------)-)---)---.             |
            |   |   |   .-----------)---)---)---o-----------)---)---)---o---------o-)---)---)---o---------)-)---)---)---.         |
            |   |   |   |   .-------)---)---)---)---o-------)---)---)---)---o-------)---)---)---)---o-----o-)---)---)---)---.     |
            |   |   |   |   |   .---)---)---)---)---)---o---)---)---)---)---)---o---)---)---)---)---)---o---)---)---)---)---)---o-'
            |   |   |   |   |   |   |   |   |   |   |   |   |   |   |   |   |   |   |   |   |   |   |   |   |   |   |   |   |   |
            |   |   |   |   |   |   |   |   |   |   |   |   |   |   |   |   |   |   |   |   |   |   |   |   |   |   |   |   |   |
           --- --- --- --- --- --- --- --- --- --- --- --- --- --- --- --- --- --- --- --- --- --- --- --- --- --- --- --- --- ---
           \ / \ / \ / \ / \ / \ / \ / \ / \ / \ / \ / \ / \ / \ / \ / \ / \ / \ / \ / \ / \ / \ / \ / \ / \ / \ / \ / \ / \ / \ /
           --- --- --- --- --- --- --- --- --- --- --- --- --- --- --- --- --- --- --- --- --- --- --- --- --- --- --- --- --- ---
           1|  2|  3|  4|  5|  6|  7|  8|  9| 10| 11| 12| 13| 14| 15| 16| 17| 18| 19| 20| 21| 22| 23| 24| 25| 26| 27| 28| 29| 30|
            |   |   |   |   |   |   |   |   |   |   |   |   |   |   |   |   |   |   |   |   |   |   |   |   |   |   |   |   |   |
            '---o---o---o---'   '---o---o---o---'   '---o---o---o---'   '---o---o---o---'   '---o---o---o---'   '---o---o---o---'
                    |                   |                   |                   |                   |                   |
                    |                   |                   |                   |                   |                   |
                   L1                  L2                  L3                  L4                  L5                  L6
```

Here, H1..6 and L1..6 are outputs of an MCP23S17T GPIO expander, and V1/V2 are
LED control voltages generated on the support board. The control scheme is as
follows.

```
.-------..----.----.----.----.----.----..----.----.----.----.----.----..----.----..------.
| LEDs  || H1 | H2 | H3 | H4 | H5 | H6 || L1 | L2 | L3 | L4 | L5 | L6 || V1 | V2 ||  x   |
|-------++----+----+----+----+----+----++----+----+----+----+----+----++----+----++------|
|  1-2  || 1  | 1  | 0  | 0  | 0  | 0  || 0  | Z  | Z  | Z  | Z  | Z  || 1  | 2  ||  0.* |
|  2-3  || 0  | 1  | 1  | 0  | 0  | 0  || 0  | Z  | Z  | Z  | Z  | Z  || 3  | 2  ||  1.* |
|  3-4  || 0  | 1  | 1  | 1  | 0  | 0  || 0  | Z  | Z  | Z  | Z  | Z  || 3  | 4  ||  2.* |
|  4-5  || 0  | 0  | 0  | 1  | 1  | 0  || 0  | Z  | Z  | Z  | Z  | Z  || 5  | 4  ||  3.* |
|  5-6  || 0  | 0  | 0  | 0  | 1  | 1  || 0  | 0  | Z  | Z  | Z  | Z  || 5  | 6  ||  4.* |
|  6-7  || 1  | 0  | 0  | 0  | 0  | 1  || Z  | 0  | Z  | Z  | Z  | Z  || 7  | 6  ||  5.* |
|  7-8  || 1  | 1  | 0  | 0  | 0  | 0  || Z  | 0  | Z  | Z  | Z  | Z  || 7  | 8  ||  6.* |
|  8-9  || 0  | 1  | 1  | 0  | 0  | 0  || Z  | 0  | Z  | Z  | Z  | Z  || 9  | 8  ||  7.* |
|  9-10 || 0  | 1  | 1  | 1  | 0  | 0  || Z  | 0  | Z  | Z  | Z  | Z  || 9  | 10 ||  8.* |
| 10-11 || 0  | 0  | 0  | 1  | 1  | 0  || Z  | 0  | 0  | Z  | Z  | Z  || 11 | 10 ||  9.* |
| 11-12 || 0  | 0  | 0  | 0  | 1  | 1  || Z  | Z  | 0  | Z  | Z  | Z  || 11 | 12 || 10.* |
| 12-13 || 1  | 0  | 0  | 0  | 0  | 1  || Z  | Z  | 0  | Z  | Z  | Z  || 13 | 12 || 11.* |
| 13-14 || 1  | 1  | 0  | 0  | 0  | 0  || Z  | Z  | 0  | Z  | Z  | Z  || 13 | 14 || 12.* |
| 14-15 || 0  | 1  | 1  | 0  | 0  | 0  || Z  | Z  | 0  | Z  | Z  | Z  || 15 | 14 || 13.* |
| 15-16 || 0  | 1  | 1  | 1  | 0  | 0  || Z  | Z  | 0  | 0  | Z  | Z  || 15 | 16 || 14.* |
| 16-17 || 0  | 0  | 0  | 1  | 1  | 0  || Z  | Z  | Z  | 0  | Z  | Z  || 17 | 16 || 15.* |
| 17-18 || 0  | 0  | 0  | 0  | 1  | 1  || Z  | Z  | Z  | 0  | Z  | Z  || 17 | 18 || 16.* |
| 18-19 || 1  | 0  | 0  | 0  | 0  | 1  || Z  | Z  | Z  | 0  | Z  | Z  || 19 | 18 || 17.* |
| 19-20 || 1  | 1  | 0  | 0  | 0  | 0  || Z  | Z  | Z  | 0  | Z  | Z  || 19 | 20 || 18.* |
| 20-21 || 0  | 1  | 1  | 0  | 0  | 0  || Z  | Z  | Z  | 0  | 0  | Z  || 21 | 20 || 19.* |
| 21-22 || 0  | 1  | 1  | 1  | 0  | 0  || Z  | Z  | Z  | Z  | 0  | Z  || 21 | 22 || 20.* |
| 22-23 || 0  | 0  | 0  | 1  | 1  | 0  || Z  | Z  | Z  | Z  | 0  | Z  || 23 | 22 || 21.* |
| 23-24 || 0  | 0  | 0  | 0  | 1  | 1  || Z  | Z  | Z  | Z  | 0  | Z  || 23 | 24 || 22.* |
| 24-25 || 1  | 0  | 0  | 0  | 0  | 1  || Z  | Z  | Z  | Z  | 0  | Z  || 25 | 24 || 23.* |
| 25-26 || 1  | 1  | 0  | 0  | 0  | 0  || Z  | Z  | Z  | Z  | 0  | 0  || 25 | 26 || 24.* |
| 26-27 || 0  | 1  | 1  | 0  | 0  | 0  || Z  | Z  | Z  | Z  | Z  | 0  || 27 | 26 || 25.* |
| 27-28 || 0  | 1  | 1  | 1  | 0  | 0  || Z  | Z  | Z  | Z  | Z  | 0  || 27 | 28 || 26.* |
| 28-29 || 0  | 0  | 0  | 1  | 1  | 0  || Z  | Z  | Z  | Z  | Z  | 0  || 29 | 28 || 27.* |
| 29-30 || 0  | 0  | 0  | 0  | 1  | 1  || Z  | Z  | Z  | Z  | Z  | 0  || 29 | 30 || 28.* |
| 30-1  || 1  | 0  | 0  | 0  | 0  | 1  || 0  | Z  | Z  | Z  | Z  | 0  || 1  | 30 || 29.* |
'-------''----'----'----'----'----'----''----'----'----'----'----'----''----'----''------'
```

That is:

 - Hi = 1 if ⌊x+i⌋ % 6 < 2 else 0
 - Li = 0 if ⌊x/5⌋ == i-1 or ⌊(x+1)/5⌋ == i-1 else Z
 - V1_pwm = x-⌊x⌋ if ⌊x/2⌋ == 1 else 1-x+⌊x⌋
 - V2_pwm = x-⌊x⌋ if ⌊x/2⌋ == 0 else 1-x+⌊x⌋

where x is a real number in [0,30> (or any real modulo 30).

Li could probably be driven high when disabled as well, and Hi could probably
be Z when disabled as well. This configuration is mostly gut feeling; it makes
sure that the base-emitter junction of the transistors always has a defined
voltage, but prevents the LEDs from ever being reverse-biased without at least
another forward-biased LED in the path to drop the voltage. In theory, some
slight ghosting might occur this way if the reverse leakage current is high
enough, but with the engraved panel in front there's no way you'd see that.

Also, yes, 30 LEDs with antialiasing is ridiculously overkill for a gimmick
like the synchroscope. Just wait until you see the 7-segment display drivers.

The current sinked by V1/V2 is approximately constant during normal operation,
because they always drive only one LED. Therefore, they can be driven directly
by a LED control channel with pullup resistor.

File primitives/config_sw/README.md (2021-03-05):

User configuration interface
============================

```
                         Vcc                            Vcc              Vcc
                        -----                          -----            -----
                          |                              |                |
                          |                              |                |
                         .-.                             |                |
                         | | 22k                         |                |
                         | |                             |                |
                         '-'                             |                | 5   SN74LVC1G10DCKR
                          |      ____                    |        1 .---------..
                    .-----o-----[____]-----o-------------)---o------|A   Vcc    `.
                    |    RunS    22k       |     RunC    |   |    3 |             \  _  4
     Run            |                      |             |   '------|B           Y |(_)----- Run
 (retaining)        |                      |             |        6 |             /
                    |                      |             o----------|C   Gnd    ,'
     :'''''''': 1   |                      |             |          '---------''
     :    <---------'                      |             |                | 2
  ^  '   .    : 2                          |             |                |
  |    .-|<---------o----------.         ----- 1uF     ----- 100nF        |
.------| '    :     |          |         -----         -----              |
|      |  <-. :     |          |           |             |                |
'------| .  | : 3   |          |           |             |                |
  |    '-|<-o-------'          |           |             |                |
  v  .   '    : 4            -----       -----         -----            -----
     :    <---------.         Gnd         Gnd           Gnd              Gnd
     :........:     |
                    |
  Increment         |
 (momentary)        |    Vcc                            Vcc              Vcc
                    |   -----                          -----            -----
JSM07011SAQNL       |     |                              |                |
   switch           |     |                              |                |
                    |    .-.                             |                |
                    |    | | 22k                         |                |
                    |    | |                             |                |
                    |    '-'                             |                | 5   SN74LVC1G10DCKR
                    |     |      ____                    |        1 .---------..
                    '-----o-----[____]-----o-------------)---o------|A   Vcc    `.
                         IncS    22k       |     IncC    |   |    3 |             \  _  4
                                           |             |   '------|B           Y |(_)----- Inc
                                           |             |        6 |             /
                                           |             o----------|C   Gnd    ,'
                                           |             |          '---------''
                                           |             |                | 2
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

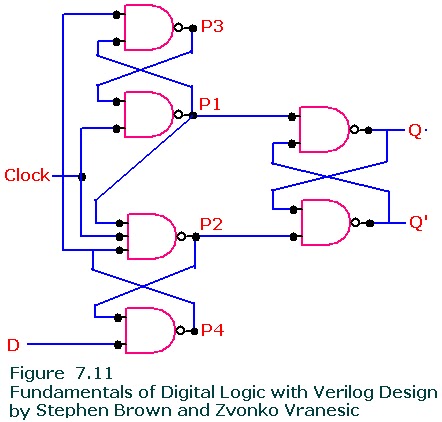
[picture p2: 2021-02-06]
subcircuits/dffn/flipflop.jpg

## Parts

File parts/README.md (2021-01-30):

Part database
=============

Database with metadata for all the parts needed to build the clock. All parts
have a `<name>.meta.txt` file with some ordering information in them. For most
of the parts this is the only thing, but some parts, like the PCBs and the
lasercut acrylic sheets need manufacturing files as well. These also live here.
Note that some (notably the PCBs) are generated.

Most parts also have a 3D model. These models live in the `models` directory
however, as some parts (like different-valued resistors) reuse the same model.
They are linked via the `model` key in `.meta.txt`.

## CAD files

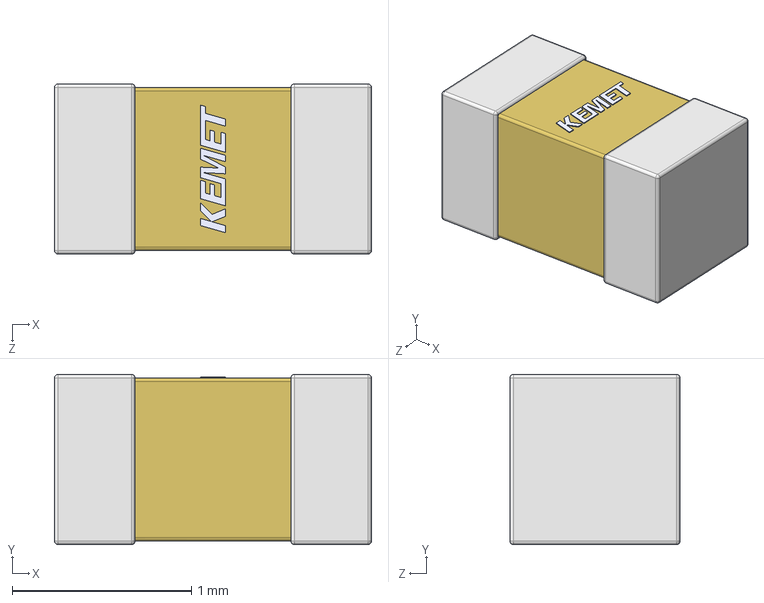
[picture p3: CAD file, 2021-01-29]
models/0603C/0603C.stp
1.77 x 0.95 x 0.95 mm

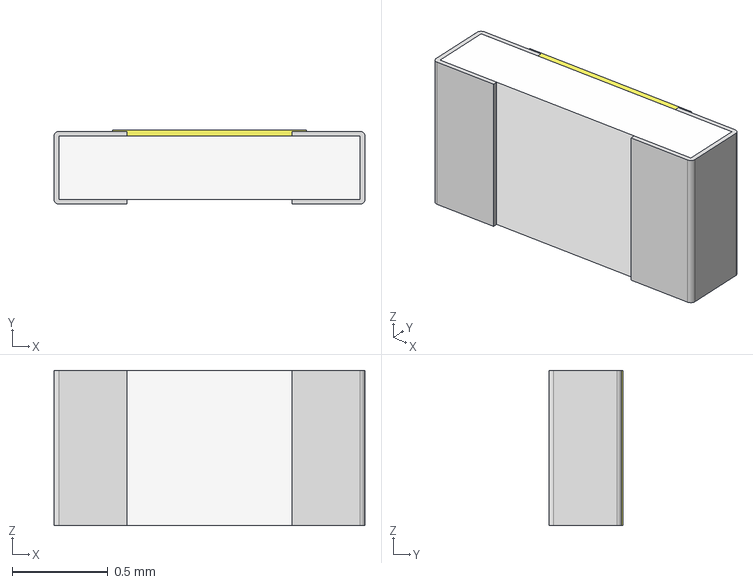
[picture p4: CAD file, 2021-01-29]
models/0603R/0603R.stp
1.63 x 0.389 x 0.813 mm

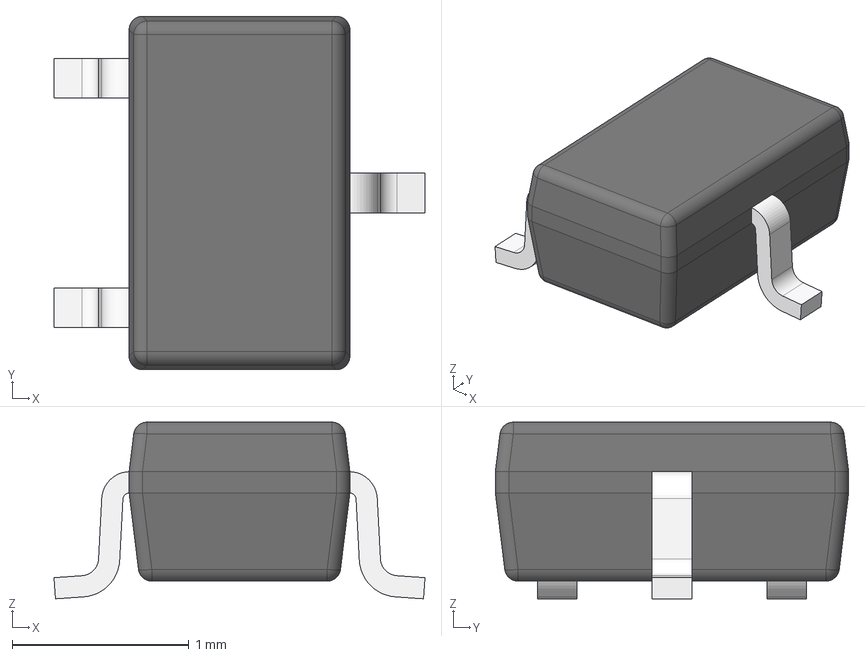
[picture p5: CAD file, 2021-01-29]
models/DCK3/DCK0003A.stp
2.10 x 2.00 x 1.00 mm
BODY-SOT
LEAD-SOT x 3
PIN1-ID

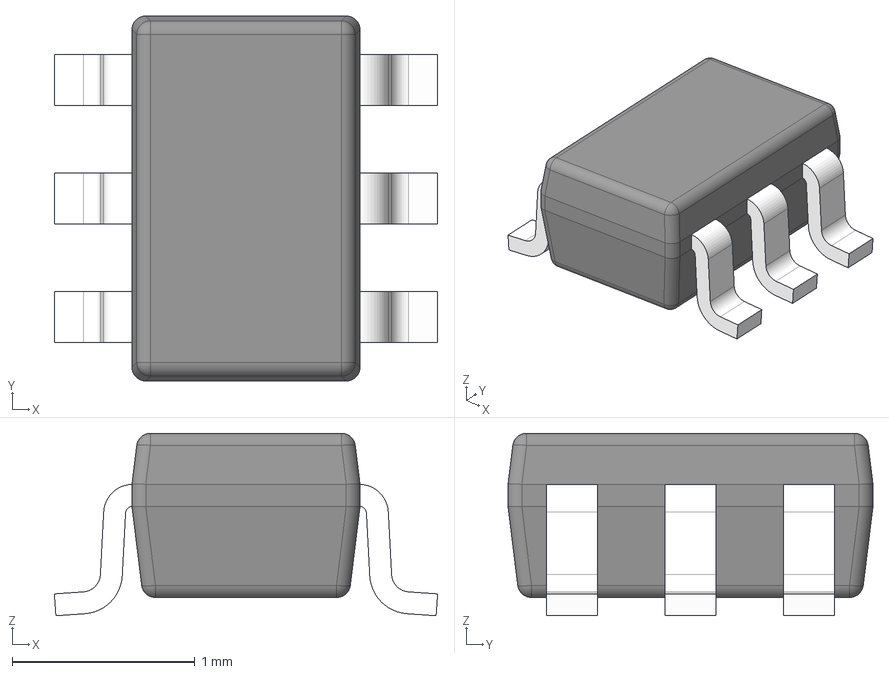
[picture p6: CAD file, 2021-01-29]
models/DCK6/DCK0006A.stp
2.10 x 2.00 x 1.00 mm
BODY-SOT
LEAD-SOT x 6
PIN1-ID

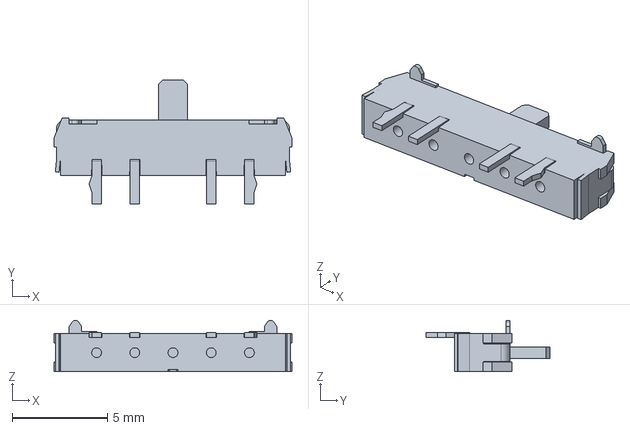
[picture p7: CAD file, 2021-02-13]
models/JSM07011SAQNL/JSM07011SAQNL.stp
12.5 x 6.50 x 2.70 mm

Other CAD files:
manual/renders/bracket.blend
models/0603C/0603C.blend
models/0603R/0603R.blend
models/1206C/1206C.blend
models/APD3224/APD3224.blend
models/B78108E/B78108E.blend
models/C5X11/C5X11.blend
models/DCA56/DCA56.blend
models/DCK3/DCK3.blend
models/DCK5/DCK5.blend
models/DCK6/DCK6.blend
models/ECS-3225/ECS-3225.blend
models/FC-203/FC-203.blend
models/FUSE5X20/FUSE5X20.blend
models/GPS/GPS.blend
models/JSM07011SAQNL/JSM07011SAQNL.blend
models/LED-T1/LED-T1.blend
models/LTST-C230/LTST-C230.blend
models/LTV-816/LTV-816.blend
models/M3NUT/M3NUT.blend
models/M3x12/M3x12.blend
models/M50-19X0005/M50-19X0005.blend
models/M50-3530342/M50-3530342.blend
models/PLCC4/PLCC4.blend
models/PTS526/PTS526.blend
models/PWP20/PWP20.blend
models/R-OL/R-OL.blend
models/RAC20-05SK/RAC20-05SK.blend
models/RPI-PICO-W/RPI-PICO-W.blend
models/RX1M/RX1M.blend
models/SMB/SMB.blend
models/SOD123/SOD123.blend
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

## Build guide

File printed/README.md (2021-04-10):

3D-printed parts
================

Aside from the lasercut acrylic plates, all structural parts, buttons, and
switches are 3D-printed. The parts are sized for a Prusa MK3S, so a build
surface of 21x25cm; this is not just the boundary for packing multiple parts
in one print, but the actual part boundary. The clock has a 40cm diameter,
after all.

Some of the printed parts depend on the actual acrylic thickness that you got.
You can set the sheet thicknesses in the `Makefile` and run `make`, or override
on the command line with
`make FRONT_THICKNESS=... DISPLAY_THICKNESS=... HIGHLIGHT_THICKNESS=...`.
The sizes are set in mm. Note that the generator only tolerates +/-1mm
deviation from nominal; anything more than that will be clamped.

Running this will give you an `stl` directory with a three directories;
`white`, `black`, and `any`. The parts in the `white` directory are visible
from the front of the clock, and should thus be printed in white (assuming
you're using the same color scheme as I did). The parts in the `black`
directory need to be printed black, in order to avoid light bleed between the
segments of the display. The remaining parts can be printed in any color.

Some STL files have `.###` suffixes, with a shared filename as prefix. This
just means the part with the shared filename needs to be printed more than
once. So if you print all the STL files once, you should have exactly the
amount of parts you need.

Here's a list of the parts:

 - `StrainRelief`: mounts to the `HighVoltageBottom` part to clamp down on the
   mains cable.
 - `QP.Grid`, `QP.Seconds`, `QP.Minutes`, and `QP.Hours`: the "quarter panels"
   that, together with the acrylic sheets, sandwich the mainboard for
   protection and slightly improved structural integrity (the prints themselves
   are super flimsy though, they only become somewhat rigid when the clock is
   fully assembled). The screw head recess depths of this part depend on the
   thickness of the acrylic sheets.
 - `WallMountBracket`: a bracket that mounts to the top of the back of the
   clock, providing something that the clock can be hung from. A nail or screw
   will work, but to be safe, you might want to use the following part;
 - `WallMountBracketB`: a bracket that mounts to a wall and mates nicely with
   its counterpart. It's mounted to the wall with two up-to 4mm thick screws,
   spaced 75mm+/-2mm apart.
 - `SupportBoardInterface`: the part that the support board mounts to. It
   itself mounts to the back of the quarter panels.
 - `SupportBoardCover`: the protective cover for the support board.
 - `SMAInsert` OR `NoSMAInsert`: these slot into the square hole formed when
   mating the support board cover and interface parts. The former has a cutout
   for a panel-mount SMA connector; the latter is a blind insert. You only need
   one of these; which you use depends on whether you intend to populate the
   clock with a GPS module or not.
 - `HighVoltageBottom` and `HighVoltageTop`: plastic shielding for the
   mains-referenced parts of the support board. When these are mounted to the
   board, you *SHOULD* not be able to touch any live metal accidentally. But
   be careful anyway when the thing is plugged in! This is just an extra
   precaution.
 - `DisplayExtender`: a printed light guide for the 7-segment displays that
   sits immediately behind the acrylic. The dimensions of this part depend on
   the acrylic thickness.
 - `DisplayLightGuide`: counterpart of the above part, that mounts to the
   support board. Its dimensions do not depend on the acrylic.
 - `SingleButton`, `DualButton`, and `SlideSwitch`: these form the caps for the
   four pushbuttons and two slide switches. `SingleButton` and `SlideSwitch`
   need to be printed twice. These parts heavily depend on the thickness of the
   acrylic, and relatively difficult to print compared to the other parts due
   to their shape; they rely heavily on build plate supports. You'll probably
   need to do some post-processing on these to make them work; this goes
   especially for the slide switches.
 - `HeaderSpacer`: a small part that you can slide over the extra-tall headers
   to give the plastic part the right height. Needs to be printed five times.
   You'll probably need to post-process these with a small drill to make the
   holes large enough for the headers; they're so small that the printer tends
   to clog them.
 - `LedBendBottomDie` and `LedBendTopDie`: these parts aid in bending the leads
   of the 3mm flipflop LEDs. They are not part of the actual clock.

I printed everything with the Prusa defaults for PETG and the
default 0.20mm SPEED setting for the stock 0.4mm nozzle, aside from enabling
build-plate supports for the parts that need it; that worked for me. Your
mileage may vary with other printers or settings.

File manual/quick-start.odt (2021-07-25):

# Installation

While the clock can be hung from a single screw or nail directly, it is recommended to use the included bracket, screws, and wall plugs, as the clock is rather heavy. The wall plugs are suitable for walls made of concrete or solid drywall, using a 5mm drill bit. For wooden walls, the screws can be used directly, using a (roughly) 3mm drill bit. For plasterboard walls, you will need special plugs and screws. The holes must be placed horizontally level, 75mm apart. Small deviations can be corrected when the bracket is installed by means of the slotted holes in the bracket. Placement of the clock on the bracket should be self-explanatory.

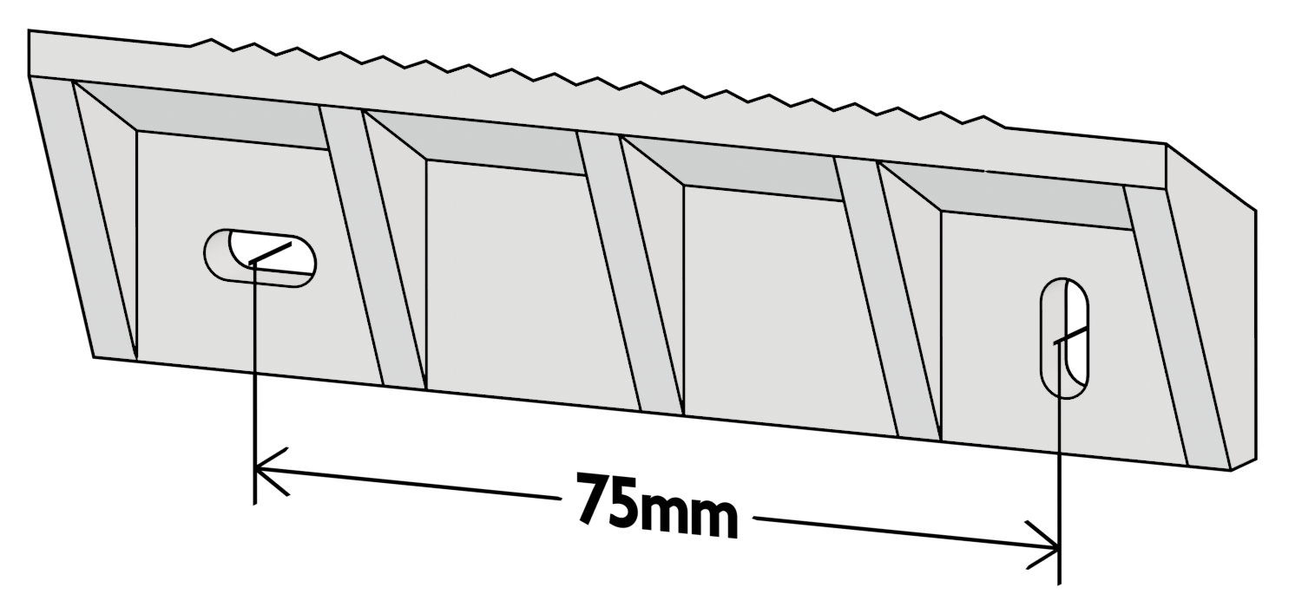
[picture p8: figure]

## GPS antenna

The clock can use GPS for time synchronization and improved synchroscope accuracy, but needs an external antenna to do so. The antenna connects to the SMA connector at the bottom of the clock. Once connected, you must configure your timezone via the location code option in the menu to enable automatic synchronization.

## Power cord

The included ~3m earthed power cord can be replaced if need be, as it is internally attached via screw terminals. Refer to the disassembly procedure for more information. Note that earthing is necessary for safety due to the exposed metal of the antenna connector.

# Usage

## Setting the time

When the clock is first powered on, and automatic time synchronization is disabled, the clock will start counting from midnight. The display will blink to indicate that the time has not been set yet.

To manually configure the time, use the following procedure.

1. If you want to synchronize the seconds counter, press and release the “reset” button when you want the counter to read zero.
2. Set both slide switches to the middle position.
3. Push the slide switch for the minutes counter to the clockwise position to increment the minutes counter. If auto-increment is enabled in the settings, the minutes counter will increment when you first push the slide switch to this position, and will proceed to increment automatically if you continue to hold it there for more than one second. If auto-increment is disabled, the counter will only increment when you release the switch. When the counter reaches 59, it will roll over back to 0 when incremented, without incrementing the hours counter. Rollover of the second counter will not increment the minutes counter.
4. Follow the same procedure for the hours counter.
5. Once the time has been configured, push both slide switches to the counter-clockwise position. Note that failing to do so will prevent the hours counter from incrementing when the minutes counter rolls over, and prevent the minutes counter from incrementing when the seconds counter rolls over.

The display will stop blinking when the minutes or hours counter is first manually incremented. It will start blinking again when the “reset” button is pressed at any time.

## Reading the date

It is possible to read the current date when the clock has had a GPS fix at any time since it was powered on. You can do so by briefly pressing the “mode” button. The date will be shown in YYMMDD format. The status LED will light up green to indicate that the date is being shown, rather than the current time. Press the “mode” button again to return to normal operation. The clock will also do this automatically after some time passes.

## Distraction-free mode

If at any point you find all the blinking lights annoying, you can easily turn all single LEDs and the seconds portion of the main display off by pressing the “down” button. Only the hours and minutes fields, the colon between them, and the status LED (if applicable) remain lit. You can leave distraction-free mode by pressing the “up” button.

## Customization

The behavior and aesthetics of the clock can be customized in various ways. This is done via a menu system. You can enter the menu by holding the “mode” button down for one second. The status LED will light up dark blue to indicate that the menu is open, the display will show an abbreviation for the current option on the left-hand side, its current value on the right-hand side, and the synchroscope will either be off or be used to show a status value related to the currently selected option.

While the menu is open, the buttons have the following behavior.

- Pressing the “up” button advances to the next option.
- Pressing the “down” button returns to the previous option.
- Pressing both “up” and “down” simultaneously, holding the “mode” button down for one second, or not pressing any button for some amount of time exits the menu.
- Depending on the selected option, briefly pressing the “mode” button either increments the option value directly, or enters value adjustment mode. In value adjustment mode, the status LED turns light blue, the value will blink, and the “up” and “down” buttons are used to set the value rather than to cycle through the available options. Press “mode” again to confirm the new value.

The following options are available.

- Flipflop LED brightness (“Fb”). A value from 0 to 100 to control the brightness of the 27 flipflop LEDs in the outside ring of the clock.
- Gate LED brightness (“Gb”). A value from 0 to 100 to control the brightness of the LEDs corresponding to the NAND gates.
- Synchroscope brightness (“Sb”). A value from 0 to 100 to control the brightness of the synchroscope display.
- Main display brightness (“db”). A value from 0 to 100 to control the brightness of the main 7-segment displays. While the value is configured, the display will read “888888” to allow the clock to detect worst-case power consumption of the main display.
- Main display color saturation (“dS”). A value from 0 to 100 to control the color saturation of the main 7-segment displays. 0 means grayscale, 100 means fully saturated.
- Main display color hue (“dH”). A value from 0 to 359 to control the color of the display. 0 is red, 60 is yellow, 120 is green, 180 is light blue, 240 is dark blue, 300 is magenta.
- Light-dependent resistor (“Ldr”). Selects whether the LDR should be used to automatically adjust the brightness of the main display based on ambient lighting conditions (“1”) or not (“0”).
- Seconds display enable (“Sd”). Selects whether the seconds should be shown (“1”) or not (“0”) when not in distraction-free mode.
- Synchronization/synchroscope mode (“Syn”). Selects the behavior of the synchroscope, and controls whether the clock uses the utility frequency or its own crystal oscillator as its timing source. The following options are available:
  - “1”: the clock is timed by the utility frequency, and the synchroscope display acts as a mechanical synchroscope to show how this frequency deviates from the GPS-referenced timing source. When the clock is running slow, the synchroscope “needle” rotates counter-clockwise; when it runs fast, it will rotate clockwise. A full 360-degree rotation of the needle represents a full cycle’s worth of phase shift, representing a 20ms offset for 50Hz, or a 16⅔ms offset for 60Hz. Note that the synchroscope “rolls over” every 84 degrees due to it not being a full circle in size.
  - “LL”: the clock is timed by the utility frequency, and the synchroscope display shows how much the seconds counter of the clock is currently offset compared to GPS time. If the middle two LEDs are both on, the seconds counter is perfectly in sync (but note that the minutes and hours might not be). If the “needle” moves clockwise, the clock is running fast; if it moves counter-clockwise it is running slow. If the outer two LEDs are both on, the seconds counter is exactly ±30s offset.
  - NOTE: this mode is only supported when seconds are displayed on the clock, the display is sufficiently bright, and GPS time is available.
  - “0”: the clock is timed by the utility frequency, but the synchroscope is turned off.
  - “50”: the clock is timed via a 50Hz signal derived from the internal crystal oscillator, which has significantly better short-term accuracy than the utility frequency. Accuracy should then be similar to a normal present-day digital or analog clock. The utility frequency is not used for anything, and the synchroscope is disabled.
  - “60”: as above, but generating a 60Hz signal.
- Auto-increment enable (“Ainc”). When enabled (“1”), the microcontroller embedded in the clock will make manually configuring the time a bit more user-friendly. When disabled (“0”), there is no “cheating:” the microcontroller won’t involve itself in the manual configuration process, leaving everything to the discrete-NAND-based circuit.
- Location code/timezone (“LC”). Set to the code corresponding to your timezone to enable automatic time synchronization via GPS. Set to “0” to disable automatic time synchronization. When enabled, the status LED will light up red during normal operation if no GPS fix is available.
- Daylight saving time mode (“dSt”). Only available when a location code is configured. Set to “A” to enable automatic resynchronization when DST changes. Set to “1” or “0” to manually configure DST.
- The synchroscope display will show additional information when the following options are selected.
- For “Fb” through “dH” (all LED brightness and color options), the synchroscope shows the current power consumption of the clock. Full scale is about 2.5A (at 5V). At 3A or more, the clock will automatically reduce brightness. At 3.5A or more, hardwired protection circuitry will disable the clock entirely until it is power-cycled to prevent damage. The embedded power supply is rated for 4A.
- For “Ldr,” the synchroscope shows the current (filtered) brightness level as detected by the LDR.
- For “LC,” the synchroscope shows a poor-man’s GPS signal strength indication, which may aid in finding a suitable place for the GPS antenna.

## Configuration storage and resetting to defaults

The clock will save its configuration to non-volatile memory when you exit the menu (or when the clock does this automatically due to inactivity). This means that your settings will survive a power cycle. You can restore the clock to its “factory” settings by holding down the “mode” button while it is powering up.

## Firmware update

It is possible to update the clock’s firmware using a computer that runs Linux and a micro-B USB cable. However, you will have to remove the support board to access the USB connector. Once removed, plug the bare support board into a wall outlet to power it up (this won’t damage the board, and as long as the high-voltage covers are installed, no live metal will be exposed) and plug the USB connector of the Teensy LC into your computer, then follow the firmware upload instructions on the GitHub repository.

# Disassembly and reassembly

This section describes how the clock may be disassembled for as far as this is useful. The reassembly procedure is in the reverse order. For the initial assembly procedure, refer to the GitHub repository.

1. Place the clock face down on a soft, flat surface, such as a piece of bubble wrap or a bed.
2. Remove the four indicated screws, then lift off the cover. It may resist slightly due to the antenna connector and LDR insert at the bottom of the clock.

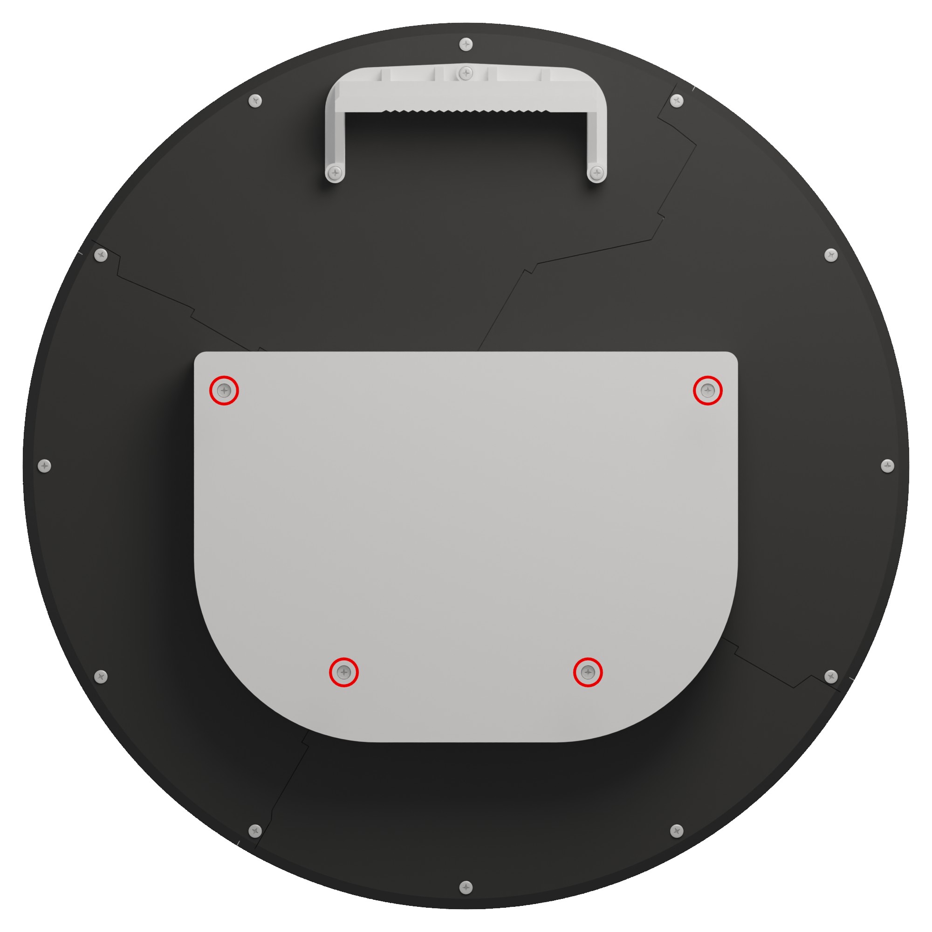
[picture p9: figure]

3. Remove the uncovered support circuit board. It is no longer attached via screws; the four screws you just removed keep both it and the cover in place. However, there are five board-to-board connectors that connect the support board to the mainboard. These can be very stiff. You can use your fingers as levers between the white plastic part that the support board rests on and the circuit board to carefully pull the board out. Note that it is normal to see the circuit board bend slightly while you’re doing this. Alternate between the five connectors to prevent excessive torsion on the connectors when one of the connectors eventually does come loose. The board will probably jump up once all connectors are sufficiently loose.

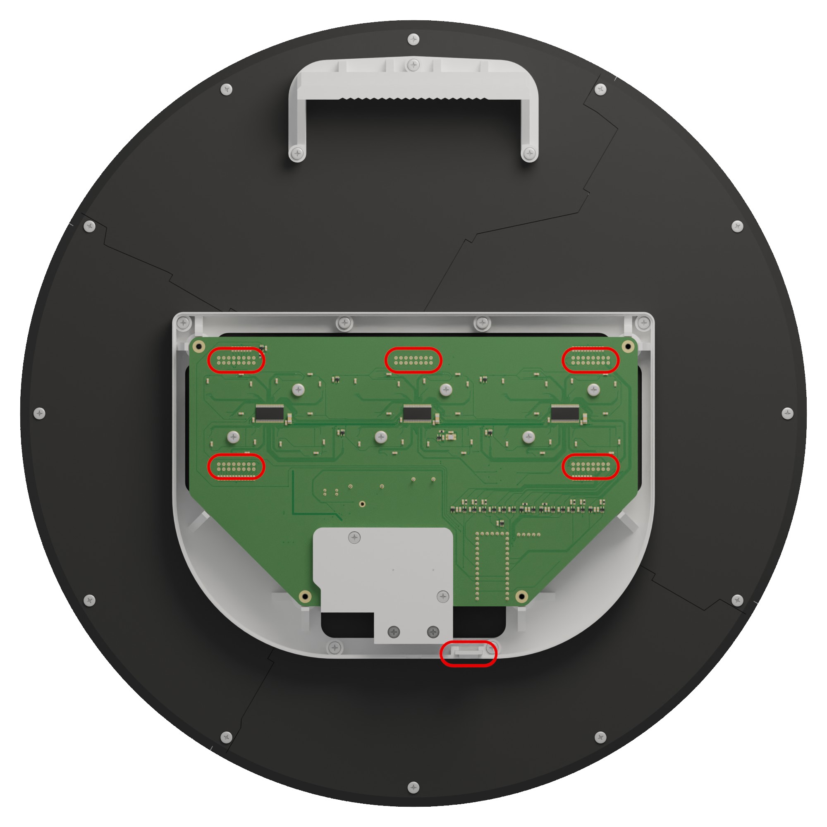
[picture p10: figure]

4. At this point, you can lift the support board out. Note however that it will still be connected via wires to a small insert piece, also indicated above. You can simply pull this out. Be careful not to bend the pins when you set the board down!
5. When reassembling, make sure that all the connectors are properly aligned to their sockets in the mainboard before pressing down. Make sure that they are all fully seated by pressing down on top of each of the five connectors before replacing the cover.
6. If you want to replace the mains fuse or connect a different power cord, remove the strain relief and high-voltage cover by removing the following screws. Start with the screws marked with 1, then remove the strain relief. Then remove the screws marked with 2 to remove both the top and bottom high-voltage cover. When replacing the power cord, be careful not to over-fasten the screws in the screw terminals; you may strip the thread if you do that! The fuse should be replaced with a T1A (slow-blow 1A) fuse at most, or a fuse with a lower rating if you feel confident enough (you might have to replace it again at some point, then).

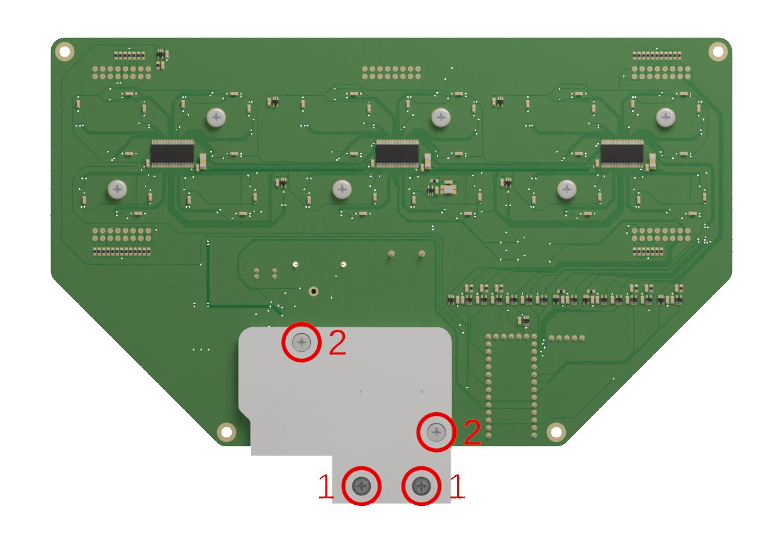
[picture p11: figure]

7. If you want to remove the mainboard, for example to clean it or make repairs, continue by removing the 8 indicated screws that hold the white plastic piece in place, then remove this piece. You may also remove the wall mount bracket with the 3 remaining indicated screws, but you don’t have to.

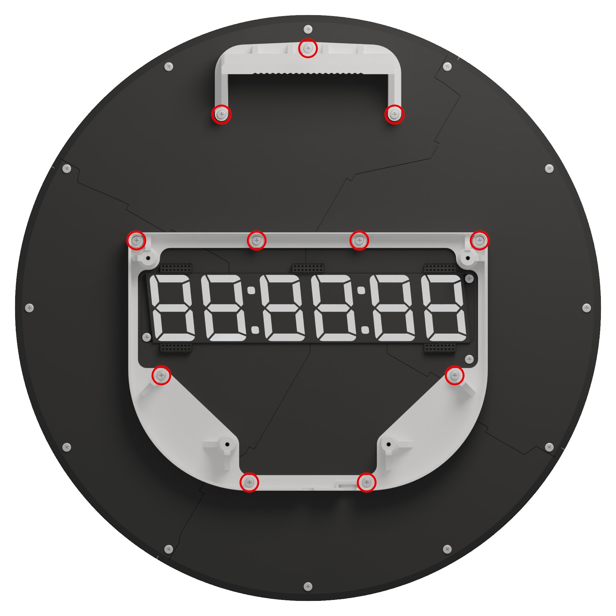
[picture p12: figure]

8. Remove the 14 indicated screws that keep the transparent acrylic, highlight acrylic, mainboard, and plastic cover sandwiched together. The two screws in the center don’t have to be removed. Once done, the complete sandwich comes apart.

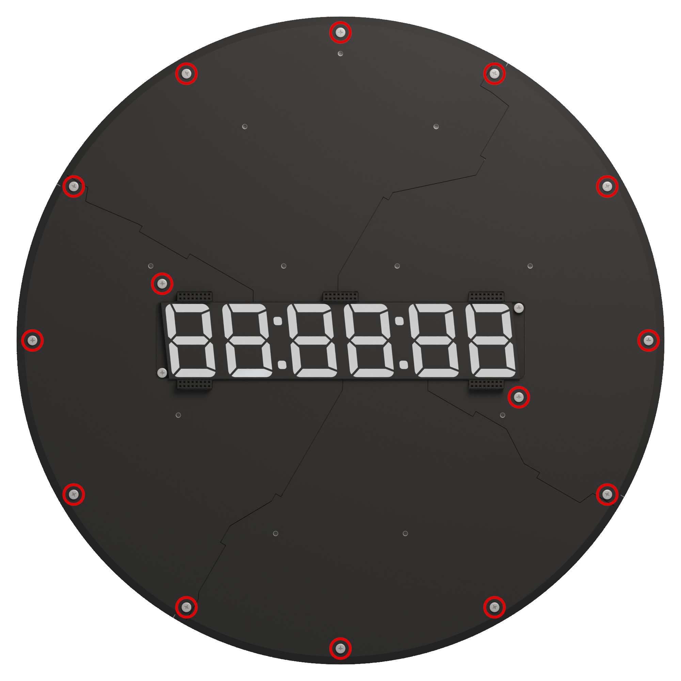
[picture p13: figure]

9. To reassemble, make sure to replace and properly align the buttons and slide switches as indicated below, then carefully replace the mainboard. Start by aligning the minutes slide switch (at the bottom), then align the seconds slide switch (to the right, viewed from the back), and only then align the buttons. They usually snap right into place, but you may need a small screwdriver to align them manually.

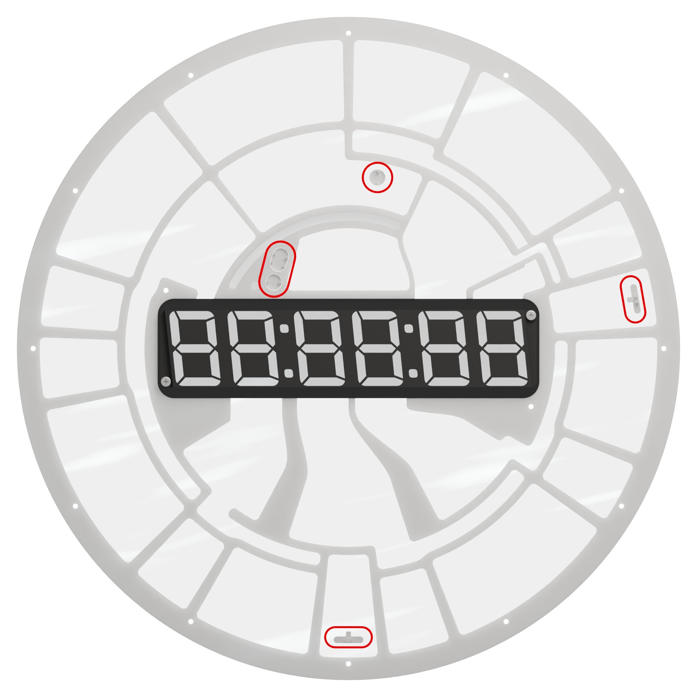
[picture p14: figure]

Quick start guide

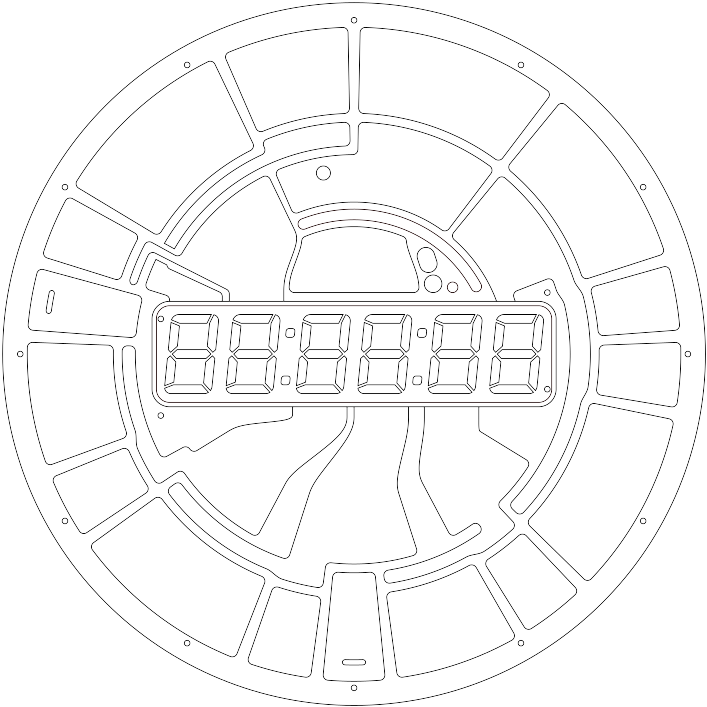
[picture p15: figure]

For more information, visit

https://github.com/jvanstraten/gated-clock/

# Location Codes

To enable GPS synchronization and automatic daylight saving time adjustment, you need to configure a timezone code using the “LC” option in the menu. The following table lists the codes corresponding to major cities.

Afghanistan/Kabul: 40

Albania/Tirane: 7

Algeria/Algiers: 1

American Samoa/Pago Pago: 67

Andorra/Andorra: 7

Angola/Luanda: 1

Anguilla/Anguilla: 8

Antarctica/Casey: 32

Antarctica/Davis: 33

Antarctica/DumontDUrville: 34

Antarctica/Mawson: 35

Antarctica/McMurdo: 36

Antarctica/Palmer: 21

Antarctica/Rothera: 9

Antarctica/Syowa: 4

Antarctica/Troll: 37

Antarctica/Vostok: 38

Antigua and Barbuda/Antigua: 8

Argentina/Buenos Aires: 9

Argentina/Catamarca: 9

Argentina/Cordoba: 9

Argentina/Jujuy: 9

Argentina/La Rioja: 9

Argentina/Mendoza: 9

Argentina/Rio Gallegos: 9

Argentina/Salta: 9

Argentina/San Juan: 9

Argentina/San Luis: 9

Argentina/Tucuman: 9

Argentina/Ushuaia: 9

Armenia/Yerevan: 41

Aruba/Aruba: 8

Australia/Adelaide: 60

Australia/Brisbane: 34

Australia/Broken Hill: 60

Australia/Darwin: 61

Australia/Eucla: 62

Australia/Hobart: 39

Australia/Lindeman: 34

Australia/Lord Howe: 63

Australia/Macquarie: 39

Australia/Melbourne: 39

Australia/Perth: 42

Australia/Sydney: 39

Austria/Vienna: 7

Azerbaijan/Baku: 41

Åland Islands/Mariehamn: 43

Bahamas/Nassau: 10

Bahrain/Bahrain: 4

Bangladesh/Dhaka: 38

Barbados/Barbados: 8

Belarus/Minsk: 4

Belgium/Brussels: 7

Belize/Belize: 11

Benin/Porto-Novo: 1

Bermuda/Bermuda: 17

Bhutan/Thimphu: 38

Bolivia/La Paz: 8

Bonaire, Sint Eustatius and Saba/Kralendijk: 8

Bosnia and Herzegovina/Sarajevo: 7

Botswana/Gaborone: 2

Brazil/Araguaina: 9

Brazil/Bahia: 9

Brazil/Belem: 9

Brazil/Boa Vista: 8

Brazil/Campo Grande: 8

Brazil/Cuiaba: 8

Brazil/Eirunepe: 12

Brazil/Fortaleza: 9

Brazil/Maceio: 9

Brazil/Manaus: 8

Brazil/Noronha: 13

Brazil/Porto Velho: 8

Brazil/Recife: 9

Brazil/Rio Branco: 12

Brazil/Santarem: 9

Brazil/Sao Paulo: 9

British Indian Ocean Territory/Chagos: 38

Brunei Darussalam/Brunei: 42

Bulgaria/Sofia: 43

Burkina Faso/Ouagadougou: 3

Burundi/Bujumbura: 2

Cabo Verde/Cape Verde: 58

Cambodia/Phnom Penh: 33

Cameroon/Douala: 1

Canada/Atikokan: 12

Canada/Blanc-Sablon: 8

Canada/Cambridge Bay: 14

Canada/Creston: 15

Canada/Dawson: 16

Canada/Dawson Creek: 15

Canada/Edmonton: 14

Canada/Fort Nelson: 15

Canada/Glace Bay: 17

Canada/Goose Bay: 17

Canada/Halifax: 17

Canada/Inuvik: 14

Canada/Iqaluit: 10

Canada/Moncton: 17

Canada/Nipigon: 10

Canada/Pangnirtung: 10

Canada/Rainy River: 18

Canada/Rankin Inlet: 18

Canada/Regina: 11

Canada/Resolute: 18

Canada/St Johns: 19

Canada/Swift Current: 11

Canada/Thunder Bay: 10

Canada/Toronto: 10

Canada/Vancouver: 20

Canada/Whitehorse: 16

Canada/Winnipeg: 18

Canada/Yellowknife: 14

Cayman Islands/Cayman: 12

Central African Republic/Bangui: 1

Chad/Ndjamena: 1

Chile/Easter: 68

Chile/Punta Arenas: 21

Chile/Santiago: 22

China/Shanghai: 42

China/Urumqi: 38

Christmas Island/Christmas: 33

Cocos (Keeling) Islands/Cocos: 52

Colombia/Bogota: 12

Comoros/Comoro: 4

Congo/Brazzaville: 1

Congo/Kinshasa: 1

Congo/Lubumbashi: 2

Cook Islands/Rarotonga: 69

Costa Rica/Costa Rica: 11

Croatia/Zagreb: 7

Cuba/Havana: 23

Curaçao/Curacao: 8

Cyprus/Famagusta: 43

Cyprus/Nicosia: 43

Czechia/Prague: 7

Côte d'Ivoire/Abidjan: 3

Denmark/Copenhagen: 7

Djibouti/Djibouti: 4

Dominica/Dominica: 8

Dominican Republic/Santo Domingo: 8

Ecuador/Galapagos: 11

Ecuador/Guayaquil: 12

Egypt/Cairo: 2

El Salvador/El Salvador: 11

Equatorial Guinea/Malabo: 1

Eritrea/Asmara: 4

Estonia/Tallinn: 43

Eswatini/Mbabane: 2

Ethiopia/Addis Ababa: 4

Falkland Islands/Stanley: 9

Faroe Islands/Faroe: 59

Fiji/Fiji: 70

Finland/Helsinki: 43

France/Paris: 7

French Guiana/Cayenne: 9

French Polynesia/Gambier: 71

French Polynesia/Marquesas: 72

French Polynesia/Tahiti: 69

French Southern Territories/Kerguelen: 35

Gabon/Libreville: 1

Gambia/Banjul: 3

Georgia/Tbilisi: 41

Germany/Berlin: 7

Germany/Busingen: 7

Ghana/Accra: 3

Gibraltar/Gibraltar: 7

Greece/Athens: 43

Greenland/Danmarkshavn: 3

Greenland/Nuuk: 24

Greenland/Scoresbysund: 25

Greenland/Thule: 17

Grenada/Grenada: 8

Guadeloupe/Guadeloupe: 8

Guam/Guam: 34

Guatemala/Guatemala: 11

Guernsey/Guernsey: 59

Guinea-Bissau/Bissau: 3

Guinea/Conakry: 3

Guyana/Guyana: 8

Haiti/Port-au-Prince: 10

Holy See/Vatican: 7

Honduras/Tegucigalpa: 11

Hong Kong/Hong Kong: 42

Hungary/Budapest: 7

Iceland/Reykjavik: 3

India/Kolkata: 44

Indonesia/Jakarta: 33

Indonesia/Jayapura: 45

Indonesia/Makassar: 42

Indonesia/Pontianak: 33

Iran/Tehran: 46

Iraq/Baghdad: 4

Ireland/Dublin: 64

Isle of Man/Isle of Man: 59

Israel/Jerusalem: 47

Italy/Rome: 7

Jamaica/Jamaica: 12

Japan/Tokyo: 45

Jersey/Jersey: 59

Jordan/Amman: 48

Kazakhstan/Almaty: 38

Kazakhstan/Aqtau: 49

Kazakhstan/Aqtobe: 35

Kazakhstan/Atyrau: 49

Kazakhstan/Oral: 49

Kazakhstan/Qostanay: 50

Kazakhstan/Qyzylorda: 35

Kenya/Nairobi: 4

Kiribati/Enderbury: 73

Kiribati/Kiritimati: 74

Kiribati/Tarawa: 55

Kuwait/Kuwait: 4

Kyrgyzstan/Bishkek: 50

Laos/Vientiane: 33

Latvia/Riga: 43

Lebanon/Beirut: 51

Lesotho/Maseru: 2

Liberia/Monrovia: 3

Libya/Tripoli: 2

Liechtenstein/Vaduz: 7

Lithuania/Vilnius: 43

Luxembourg/Luxembourg: 7

Macao/Macau: 42

Madagascar/Antananarivo: 4

Malawi/Blantyre: 2

Malaysia/Kuala Lumpur: 42

Malaysia/Kuching: 42

Maldives/Maldives: 35

Mali/Bamako: 3

Malta/Malta: 7

Marshall Islands/Kwajalein: 55

Marshall Islands/Majuro: 55

Martinique/Martinique: 8

Mauritania/Nouakchott: 3

Mauritius/Mauritius: 41

Mayotte/Mayotte: 4

Mexico/Bahia Banderas: 26

Mexico/Cancun: 12

Mexico/Chihuahua: 27

Mexico/Hermosillo: 15

Mexico/Matamoros: 18

Mexico/Mazatlan: 27

Mexico/Merida: 26

Mexico/Mexico City: 26

Mexico/Monterrey: 26

Mexico/Ojinaga: 14

Mexico/Tijuana: 20

Micronesia/Chuuk: 34

Micronesia/Kosrae: 56

Micronesia/Pohnpei: 56

Moldova/Chisinau: 65

Monaco/Monaco: 7

Mongolia/Choibalsan: 42

Mongolia/Hovd: 33

Mongolia/Ulaanbaatar: 42

Montenegro/Podgorica: 7

Montserrat/Montserrat: 8

Morocco/Casablanca: 5

Mozambique/Maputo: 2

Myanmar/Yangon: 52

Namibia/Windhoek: 2

Nauru/Nauru: 55

Nepal/Kathmandu: 53

Netherlands/Amsterdam: 7

New Caledonia/Noumea: 56

New Zealand/Auckland: 36

New Zealand/Chatham: 75

Nicaragua/Managua: 11

Niger/Niamey: 1

Nigeria/Lagos: 1

Niue/Niue: 67

Norfolk Island/Norfolk: 76

North Korea/Pyongyang: 45

North Macedonia/Skopje: 7

Northern Mariana Islands/Saipan: 34

Norway/Oslo: 7

Oman/Muscat: 41

Pakistan/Karachi: 35

Palau/Palau: 45

Palestine/Gaza: 54

Palestine/Hebron: 54

Panama/Panama: 12

Papua New Guinea/Bougainville: 56

Papua New Guinea/Port Moresby: 34

Paraguay/Asuncion: 28

Peru/Lima: 12

Philippines/Manila: 42

Pitcairn/Pitcairn: 77

Poland/Warsaw: 7

Portugal/Azores: 25

Portugal/Lisbon: 59

Portugal/Madeira: 59

Puerto Rico/Puerto Rico: 8

Qatar/Qatar: 4

Romania/Bucharest: 43

Russia/Anadyr: 55

Russia/Astrakhan: 41

Russia/Barnaul: 33

Russia/Chita: 45

Russia/Irkutsk: 42

Russia/Kaliningrad: 2

Russia/Kamchatka: 55

Russia/Khandyga: 45

Russia/Kirov: 4

Russia/Krasnoyarsk: 33

Russia/Magadan: 56

Russia/Moscow: 4

Russia/Novokuznetsk: 33

Russia/Novosibirsk: 33

Russia/Omsk: 38

Russia/Sakhalin: 56

Russia/Samara: 41

Russia/Saratov: 41

Russia/Srednekolymsk: 56

Russia/Tomsk: 33

Russia/Ulyanovsk: 41

Russia/Ust-Nera: 34

Russia/Vladivostok: 34

Russia/Volgograd: 66

Russia/Yakutsk: 45

Russia/Yekaterinburg: 35

Rwanda/Kigali: 2

Réunion/Reunion: 41

Saint Barthélemy/St Barthelemy: 8

Saint Helena, Ascension and Tristan da Cunha/St Helena: 3

Saint Kitts and Nevis/St Kitts: 8

Saint Lucia/St Lucia: 8

Saint Martin (French part)/Marigot: 8

Saint Pierre and Miquelon/Miquelon: 29

Saint Vincent and the Grenadines/St Vincent: 8

Samoa/Apia: 78

San Marino/San Marino: 7

Sao Tome and Principe/Sao Tome: 3

Saudi Arabia/Riyadh: 4

Senegal/Dakar: 3

Serbia/Belgrade: 7

Seychelles/Mahe: 41

Sierra Leone/Freetown: 3

Singapore/Singapore: 42

Sint Maarten (Dutch part)/Lower Princes: 8

Slovakia/Bratislava: 7

Slovenia/Ljubljana: 7

Solomon Islands/Guadalcanal: 56

Somalia/Mogadishu: 4

South Africa/Johannesburg: 2

South Georgia and the South Sandwich Islands/South Georgia: 13

South Korea/Seoul: 45

South Sudan/Juba: 6

Spain/Canary: 59

Spain/Ceuta: 7

Spain/Madrid: 7

Sri Lanka/Colombo: 44

Sudan/Khartoum: 2

Suriname/Paramaribo: 9

Svalbard and Jan Mayen/Longyearbyen: 7

Sweden/Stockholm: 7

Switzerland/Zurich: 7

Syria/Damascus: 57

Taiwan, Province of China/Taipei: 42

Tajikistan/Dushanbe: 35

Tanzania/Dar es Salaam: 4

Thailand/Bangkok: 33

Timor-Leste/Dili: 45

Togo/Lome: 3

Tokelau/Fakaofo: 73

Tonga/Tongatapu: 73

Trinidad and Tobago/Port of Spain: 8

Tunisia/Tunis: 1

Turkey/Istanbul: 4

Turkmenistan/Ashgabat: 35

Turks and Caicos Islands/Grand Turk: 10

Tuvalu/Funafuti: 55

USA/Adak: 30

USA/Anchorage: 31

USA/Boise: 14

USA/Chicago: 18

USA/Denver: 14

USA/Detroit: 10

USA/Honolulu: 69

USA/Indiana/Indianapolis: 10

USA/Indiana/Knox: 18

USA/Indiana/Marengo: 10

USA/Indiana/Petersburg: 10

USA/Indiana/Tell City: 18

USA/Indiana/Vevay: 10

USA/Indiana/Vincennes: 10

USA/Indiana/Winamac: 10

USA/Juneau: 31

USA/Kentucky/Louisville: 10

USA/Kentucky/Monticello: 10

USA/Los Angeles: 20

USA/Menominee: 18

USA/Metlakatla: 31

USA/Midway: 67

USA/New York: 10

USA/Nome: 31

USA/North Dakota/Beulah: 18

USA/North Dakota/Center: 18

USA/North Dakota/New Salem: 18

USA/Phoenix: 15

USA/Sitka: 31

USA/Wake: 55

USA/Yakutat: 31

Uganda/Kampala: 4

Ukraine/Kiev: 43

Ukraine/Simferopol: 4

Ukraine/Uzhgorod: 43

Ukraine/Zaporozhye: 43

United Arab Emirates/Dubai: 41

United Kingdom/London: 59

Uruguay/Montevideo: 9

Uzbekistan/Samarkand: 35

Uzbekistan/Tashkent: 35

Vanuatu/Efate: 56

Venezuela/Caracas: 8

Viet Nam/Ho Chi Minh: 33

Virgin Islands (British)/Tortola: 8

Virgin Islands (U.S.)/St Thomas: 8

Wallis and Futuna/Wallis: 55

Western Sahara/El Aaiun: 5

Yemen/Aden: 4

Zambia/Lusaka: 2

Zimbabwe/Harare: 2

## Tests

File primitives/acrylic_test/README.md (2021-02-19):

Test thingy for acrylic plates
==============================

Just a test order.

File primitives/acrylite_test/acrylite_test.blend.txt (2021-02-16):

hole 164.5447998046875 -94.99996948242188 3.199999794562331
hole 94.99999237060547 -164.54478454589844 3.199999794562331
hole 189.99996948242188 1.486753626522841e-05 3.199999794562331
hole 2.973507253045682e-05 -189.99996948242188 3.199999794562331
hole -94.99996185302734 -164.5447998046875 3.199999794562331
hole -164.5447998046875 -95.00000762939453 3.199999794562331
hole -189.99996948242188 -4.460260606720112e-05 3.199999794562331
hole -164.5447998046875 94.99993133544922 3.199999794562331
hole -95.0000228881836 164.54478454589844 3.199999794562331
hole -5.947014506091364e-05 189.99996948242188 3.199999794562331
hole 94.99993133544922 164.5447998046875 3.199999794562331
hole 164.54476928710938 95.00003814697266 3.199999794562331
hole -109.9999771118164 19.999954223632812 3.199999794562331
hole 110.00000762939453 -20.000041961669922 3.199999794562331
layer Acrylite.Front.Cut
mode C0.1
line -111.24394226074219 20.122568130493164 -111.24996948242188 20.000051498413086
line -111.22593688964844 20.243906021118164 -111.24394226074219 20.122568130493164
line -111.19612121582031 20.36289405822754 -111.22593688964844 20.243906021118164
line -111.15479278564453 20.4783878326416 -111.19612121582031 20.36289405822754
line -111.10234069824219 20.58927345275879 -111.15479278564453 20.4783878326416
line -111.03926849365234 20.694482803344727 -111.10234069824219 20.58927345275879
line -110.96619415283203 20.793004989624023 -111.03926849365234 20.694482803344727
line -110.8838119506836 20.88389015197754 -110.96619415283203 20.793004989624023
line -110.79291534423828 20.966262817382812 -110.8838119506836 20.88389015197754
line -110.69438171386719 21.039329528808594 -110.79291534423828 20.966262817382812
line -110.58915710449219 21.102384567260742 -110.69438171386719 21.039329528808594
line -110.47826385498047 21.154823303222656 -110.58915710449219 21.102384567260742
line -110.3627700805664 21.196142196655273 -110.47826385498047 21.154823303222656
line -110.24378204345703 21.22593879699707 -110.3627700805664 21.196142196655273
line -110.12244415283203 21.243928909301758 -110.24378204345703 21.22593879699707
line -109.99992370605469 21.249940872192383 -110.12244415283203 21.243928909301758
line -109.87741088867188 21.243915557861328 -109.99992370605469 21.249940872192383
line -109.75607299804688 21.225910186767578 -109.87741088867188 21.243915557861328
line -109.6370849609375 21.196096420288086 -109.75607299804688 21.225910186767578
line -109.52159118652344 21.15476417541504 -109.6370849609375 21.196096420288086
line -109.41070556640625 21.102312088012695 -109.52159118652344 21.15476417541504
line -109.30549621582031 21.039243698120117 -109.41070556640625 21.102312088012695
line -109.20697021484375 20.96616554260254 -109.30549621582031 21.039243698120117
line -109.11608123779297 20.8837833404541 -109.20697021484375 20.96616554260254
line -109.0337142944336 20.792888641357422 -109.11608123779297 20.8837833404541
line -108.96064758300781 20.69435691833496 -109.0337142944336 20.792888641357422
line -108.89759063720703 20.589139938354492 -108.96064758300781 20.69435691833496
line -108.84514617919922 20.478248596191406 -108.89759063720703 20.589139938354492
line -108.8038330078125 20.362751007080078 -108.84514617919922 20.478248596191406
line -108.77404022216797 20.243757247924805 -108.8038330078125 20.362751007080078
line -108.75604248046875 20.122419357299805 -108.77404022216797 20.243757247924805
line -108.75003051757812 19.999900817871094 -108.75604248046875 20.122419357299805
line -108.75605773925781 19.877382278442383 -108.75003051757812 19.999900817871094
line -108.77406311035156 19.756044387817383 -108.75605773925781 19.877382278442383
line -108.80387115478516 19.637056350708008 -108.77406311035156 19.756044387817383
line -108.84520721435547 19.521562576293945 -108.80387115478516 19.637056350708008
line -108.89766693115234 19.410676956176758 -108.84520721435547 19.521562576293945
line -108.96073150634766 19.30546760559082 -108.89766693115234 19.410676956176758
line -109.0338134765625 19.206945419311523 -108.96073150634766 19.30546760559082
line -109.11619567871094 19.116060256958008 -109.0338134765625 19.206945419311523
line -109.20708465576172 19.033689498901367 -109.11619567871094 19.116060256958008
line -109.30561065673828 18.960622787475586 -109.20708465576172 19.033689498901367
line -109.41082763671875 18.897565841674805 -109.30561065673828 18.960622787475586
line -109.52172088623047 18.845125198364258 -109.41082763671875 18.897565841674805
line -109.63722229003906 18.803808212280273 -109.52172088623047 18.845125198364258
line -109.75621795654297 18.774009704589844 -109.63722229003906 18.803808212280273
line -109.8775634765625 18.756017684936523 -109.75621795654297 18.774009704589844
line -110.00008392333984 18.75000762939453 -109.8775634765625 18.756017684936523
line -110.12260437011719 18.75603485107422 -110.00008392333984 18.75000762939453
line -110.24394226074219 18.7740421295166 -110.12260437011719 18.75603485107422
line -110.36293029785156 18.803855895996094 -110.24394226074219 18.7740421295166
line -110.47842407226562 18.845190048217773 -110.36293029785156 18.803855895996094
line -110.58930969238281 18.897645950317383 -110.47842407226562 18.845190048217773
line -110.69451904296875 18.960716247558594 -110.58930969238281 18.897645950317383
line -110.79303741455078 19.033796310424805 -110.69451904296875 18.960716247558594
line -110.88391876220703 19.116178512573242 -110.79303741455078 19.033796310424805
line -110.96629333496094 19.20707130432129 -110.88391876220703 19.116178512573242
line -111.03936004638672 19.30560302734375 -110.96629333496094 19.20707130432129
line -111.1024169921875 19.41082191467285 -111.03936004638672 19.30560302734375
line -111.15485382080078 19.52171516418457 -111.1024169921875 19.41082191467285
line -111.19617462158203 19.63721466064453 -111.15485382080078 19.52171516418457
line -111.2259750366211 19.756206512451172 -111.19617462158203 19.63721466064453
line -111.24396514892578 19.877546310424805 -111.2259750366211 19.756206512451172
line -111.24996948242188 20.000051498413086 -111.24396514892578 19.877546310424805
line 108.75001525878906 -19.99994468688965 108.75604248046875 -19.87742805480957
line 108.75604248046875 -19.87742805480957 108.7740478515625 -19.75609016418457
line 108.7740478515625 -19.75609016418457 108.80386352539062 -19.637102127075195
line 108.80386352539062 -19.637102127075195 108.8451919555664 -19.521608352661133
line 108.8451919555664 -19.521608352661133 108.89764404296875 -19.410722732543945
line 108.89764404296875 -19.410722732543945 108.9607162475586 -19.305513381958008
line 108.9607162475586 -19.305513381958008 109.0337905883789 -19.20699119567871
line 109.0337905883789 -19.20699119567871 109.11617279052734 -19.116106033325195
line 109.11617279052734 -19.116106033325195 109.20706939697266 -19.033733367919922
line 109.20706939697266 -19.033733367919922 109.30560302734375 -18.96066665649414
line 109.30560302734375 -18.96066665649414 109.41082763671875 -18.897611618041992
line 109.41082763671875 -18.897611618041992 109.52172088623047 -18.845172882080078
line 109.52172088623047 -18.845172882080078 109.63721466064453 -18.80385398864746
line 109.63721466064453 -18.80385398864746 109.7562026977539 -18.774057388305664
line 109.7562026977539 -18.774057388305664 109.8775405883789 -18.756067276000977
line 109.8775405883789 -18.756067276000977 110.00006103515625 -18.75005531311035
line 110.00006103515625 -18.75005531311035 110.12257385253906 -18.756080627441406
line 110.12257385253906 -18.756080627441406 110.24391174316406 -18.774085998535156
line 110.24391174316406 -18.774085998535156 110.36289978027344 -18.80389976501465
line 110.36289978027344 -18.80389976501465 110.4783935546875 -18.845232009887695
line 110.4783935546875 -18.845232009887695 110.58927917480469 -18.89768409729004
line 110.58927917480469 -18.89768409729004 110.69448852539062 -18.960752487182617
line 110.69448852539062 -18.960752487182617 110.79301452636719 -19.033830642700195
line 110.79301452636719 -19.033830642700195 110.88390350341797 -19.116212844848633
line 110.88390350341797 -19.116212844848633 110.96627044677734 -19.207107543945312
line 110.96627044677734 -19.207107543945312 111.03933715820312 -19.305639266967773
line 111.03933715820312 -19.305639266967773 111.1023941040039 -19.410856246948242
line 111.1023941040039 -19.410856246948242 111.15483856201172 -19.521747589111328
line 111.15483856201172 -19.521747589111328 111.19615173339844 -19.637245178222656
line 111.19615173339844 -19.637245178222656 111.22594451904297 -19.75623893737793
line 111.22594451904297 -19.75623893737793 111.24394226074219 -19.87757682800293
line 111.24394226074219 -19.87757682800293 111.24995422363281 -20.00009536743164
line 111.24995422363281 -20.00009536743164 111.24392700195312 -20.12261390686035
line 111.24392700195312 -20.12261390686035 111.22592163085938 -20.24395179748535
line 111.22592163085938 -20.24395179748535 111.19611358642578 -20.362939834594727
line 111.19611358642578 -20.362939834594727 111.15477752685547 -20.47843360900879
line 111.15477752685547 -20.47843360900879 111.1023178100586 -20.589319229125977
line 111.1023178100586 -20.589319229125977 111.03925323486328 -20.694528579711914
line 111.03925323486328 -20.694528579711914 110.96617126464844 -20.79305076599121
line 110.96617126464844 -20.79305076599121 110.8837890625 -20.883935928344727
line 110.8837890625 -20.883935928344727 110.79290008544922 -20.966306686401367
line 110.79290008544922 -20.966306686401367 110.69437408447266 -21.03937339782715
line 110.69437408447266 -21.03937339782715 110.58915710449219 -21.10243034362793
line 110.58915710449219 -21.10243034362793 110.47826385498047 -21.154870986938477
line 110.47826385498047 -21.154870986938477 110.36276245117188 -21.19618797302246
line 110.36276245117188 -21.19618797302246 110.24376678466797 -21.22598648071289
line 110.24376678466797 -21.22598648071289 110.12242126464844 -21.24397850036621
line 110.12242126464844 -21.24397850036621 109.9999008178711 -21.249988555908203
line 109.9999008178711 -21.249988555908203 109.87738037109375 -21.243961334228516
line 109.87738037109375 -21.243961334228516 109.75604248046875 -21.225954055786133
line 109.75604248046875 -21.225954055786133 109.63705444335938 -21.19614028930664
line 109.63705444335938 -21.19614028930664 109.52156066894531 -21.15480613708496
line 109.52156066894531 -21.15480613708496 109.41067504882812 -21.10235023498535
line 109.41067504882812 -21.10235023498535 109.30546569824219 -21.03927993774414
line 109.30546569824219 -21.03927993774414 109.20694732666016 -20.96619987487793
line 109.20694732666016 -20.96619987487793 109.1160659790039 -20.883817672729492
line 109.1160659790039 -20.883817672729492 109.03369140625 -20.792924880981445
line 109.03369140625 -20.792924880981445 108.96062469482422 -20.694393157958984
line 108.96062469482422 -20.694393157958984 108.89756774902344 -20.589174270629883
line 108.89756774902344 -20.589174270629883 108.84513092041016 -20.478281021118164
line 108.84513092041016 -20.478281021118164 108.8038101196289 -20.362781524658203
line 108.8038101196289 -20.362781524658203 108.77400970458984 -20.243789672851562
line 108.77400970458984 -20.243789672851562 108.75601959228516 -20.12244987487793
line 108.75601959228516 -20.12244987487793 108.75001525878906 -19.99994468688965
layer Acrylite.Front.Engrave
mode region
vert -105.18405151367188 27.497739791870117
vert -105.36800384521484 27.490962982177734
vert -105.55172729492188 27.47967529296875
vert -105.73512268066406 27.463882446289062
vert -105.91807556152344 27.443592071533203
vert -106.10047912597656 27.4188175201416
vert -106.28221893310547 27.38957405090332
vert -106.46318054199219 27.355880737304688
vert -106.64326477050781 27.3177547454834
vert -106.82235717773438 27.27522087097168
vert -107.00035095214844 27.22830581665039
vert -107.17713928222656 27.17703628540039
vert -107.35261535644531 27.121444702148438
vert -107.52667999267578 27.061561584472656
vert -107.69921875 26.997426986694336
vert -107.87013244628906 26.9290771484375
vert -108.03932189941406 26.856552124023438
vert -108.20668029785156 26.779897689819336
vert -108.37210083007812 26.69915771484375
vert -108.53549194335938 26.614383697509766
vert -108.6967544555664 26.525623321533203
vert -108.85578918457031 26.432933807373047
vert -109.01250457763672 26.336368560791016
vert -109.16680145263672 26.235986709594727
vert -109.3185806274414 26.13184928894043
vert -109.46775817871094 26.024019241333008
vert -109.6142578125 25.912559509277344
vert -109.75797271728516 25.797536849975586
vert -109.89881896972656 25.67902183532715
vert -110.0367202758789 25.557086944580078
vert -110.17158508300781 25.431804656982422
vert -110.30333709716797 25.30324935913086
vert -110.43189239501953 25.171499252319336
vert -110.55717468261719 25.03663444519043
vert -110.67911529541016 24.89873695373535
vert -110.7976303100586 24.75788688659668
vert -110.91265106201172 24.614171981811523
vert -111.02411651611328 24.467676162719727
vert -111.13194274902344 24.31848907470703
vert -111.236083984375 24.166702270507812
vert -111.33646392822266 24.012405395507812
vert -111.43302917480469 23.855690002441406
vert -111.52571868896484 23.696653366088867
vert -111.61447143554688 23.535388946533203
vert -111.69924926757812 23.37199592590332
vert -111.77998352050781 23.20656967163086
vert -111.85663604736328 23.039215087890625
vert -111.92915344238281 22.87002944946289
vert -111.99749755859375 22.699113845825195
vert -112.06163787841797 22.526573181152344
vert -112.12152099609375 22.352510452270508
vert -112.17711639404297 22.17702865600586
vert -112.22838592529297 22.00023651123047
vert -112.27529907226562 21.82223892211914
vert -112.31783294677734 21.643144607543945
vert -112.35595703125 21.463058471679688
vert -112.38965606689453 21.282093048095703
vert -112.41889190673828 21.100353240966797
vert -112.44366455078125 20.917951583862305
vert -112.46395111083984 20.734996795654297
vert -112.47974395751953 20.551599502563477
vert -112.49103546142578 20.367870330810547
vert -112.49781036376953 20.18391990661621
vert -112.50006866455078 19.999858856201172
vert -112.50006866455078 -19.999858856201172
vert -112.49781036376953 -20.18391990661621
vert -112.49103546142578 -20.367870330810547
vert -112.47974395751953 -20.551599502563477
vert -112.46395111083984 -20.734996795654297
vert -112.44366455078125 -20.917951583862305
vert -112.41889190673828 -21.100353240966797
vert -112.38965606689453 -21.282093048095703
vert -112.35595703125 -21.463058471679688
vert -112.31783294677734 -21.643144607543945
vert -112.27529907226562 -21.82223892211914
vert -112.22838592529297 -22.00023651123047
vert -112.17711639404297 -22.17702865600586
vert -112.12152099609375 -22.352510452270508
vert -112.06163787841797 -22.526573181152344
vert -111.99749755859375 -22.699113845825195
vert -111.92915344238281 -22.87002944946289
vert -111.85663604736328 -23.039215087890625
vert -111.77998352050781 -23.20656967163086
vert -111.69924926757812 -23.37199592590332
vert -111.61447143554688 -23.535388946533203
vert -111.52571868896484 -23.696653366088867
vert -111.43302917480469 -23.855690002441406
vert -111.33646392822266 -24.012405395507812
vert -111.236083984375 -24.166702270507812
vert -111.13194274902344 -24.31848907470703
vert -111.02411651611328 -24.467676162719727
vert -110.91265106201172 -24.614171981811523
vert -110.7976303100586 -24.75788688659668
vert -110.67911529541016 -24.89873695373535
vert -110.55717468261719 -25.03663444519043
vert -110.43189239501953 -25.171499252319336
vert -110.30333709716797 -25.30324935913086
vert -110.17158508300781 -25.431804656982422
vert -110.0367202758789 -25.557086944580078
vert -109.89881896972656 -25.67902183532715
vert -109.75797271728516 -25.797536849975586
vert -109.6142578125 -25.912559509277344
vert -109.46775817871094 -26.024019241333008
vert -109.3185806274414 -26.13184928894043
vert -109.16680145263672 -26.235986709594727
vert -109.01250457763672 -26.336368560791016
vert -108.85578918457031 -26.432933807373047
vert -108.6967544555664 -26.525623321533203
vert -108.53549194335938 -26.614383697509766
vert -108.37210083007812 -26.69915771484375
vert -108.20668029785156 -26.779897689819336
vert -108.03932189941406 -26.856552124023438
vert -107.87013244628906 -26.9290771484375
vert -107.69921875 -26.997426986694336
vert -107.52667999267578 -27.061561584472656
vert -107.35261535644531 -27.121444702148438
vert -107.17713928222656 -27.17703628540039
vert -107.00035095214844 -27.22830581665039
vert -106.82235717773438 -27.27522087097168
vert -106.64326477050781 -27.3177547454834
vert -106.46318054199219 -27.355880737304688
vert -106.28221893310547 -27.38957405090332
vert -106.10047912597656 -27.4188175201416
vert -105.91807556152344 -27.443592071533203
vert -105.73512268066406 -27.463882446289062
vert -105.55172729492188 -27.47967529296875
vert -105.36800384521484 -27.490962982177734
vert -105.18405151367188 -27.497739791870117
vert -104.99999237060547 -27.499998092651367
vert -79.99999237060547 -27.499998092651367
vert -79.81593322753906 -27.497739791870117
vert -79.6319808959961 -27.490962982177734
vert -79.44825744628906 -27.47967529296875
vert -79.26486206054688 -27.463882446289062
vert -79.0819091796875 -27.443592071533203
vert -78.89950561523438 -27.4188175201416
vert -78.71776580810547 -27.38957405090332
vert -78.53680419921875 -27.355880737304688
vert -78.35671997070312 -27.3177547454834
vert -78.17762756347656 -27.27522087097168
vert -77.9996337890625 -27.22830581665039
vert -77.82284545898438 -27.17703628540039
vert -77.64736938476562 -27.121444702148438
vert -77.47330474853516 -27.061561584472656
vert -77.30076599121094 -26.997426986694336
vert -77.12985229492188 -26.9290771484375
vert -76.96066284179688 -26.856552124023438
vert -76.79330444335938 -26.779897689819336
vert -76.62788391113281 -26.69915771484375
vert -76.46449279785156 -26.614383697509766
vert -76.30323028564453 -26.525623321533203
vert -76.14419555664062 -26.432933807373047
vert -75.98748016357422 -26.336368560791016
vert -75.83318328857422 -26.235986709594727
vert -75.68140411376953 -26.13184928894043
vert -75.5322265625 -26.024019241333008
vert -75.38572692871094 -25.912559509277344
vert -75.24201202392578 -25.797536849975586
vert -75.10116577148438 -25.67902183532715
vert -74.96326446533203 -25.557086944580078
vert -74.82839965820312 -25.431804656982422
vert -74.69664764404297 -25.30324935913086
vert -74.5680923461914 -25.171499252319336
vert -74.44281005859375 -25.03663444519043
vert -74.32086944580078 -24.89873695373535
vert -74.20235443115234 -24.75788688659668
vert -74.08733367919922 -24.614171981811523
vert -73.97586822509766 -24.467676162719727
vert -73.8680419921875 -24.31848907470703
vert -73.76390075683594 -24.166702270507812
vert -73.66352081298828 -24.012405395507812
vert -73.56695556640625 -23.855690002441406
vert -73.4742660522461 -23.696653366088867
vert -73.38551330566406 -23.535388946533203
vert -73.30073547363281 -23.37199592590332
vert -73.22000122070312 -23.20656967163086
vert -73.14334869384766 -23.039215087890625
vert -73.07083129882812 -22.87002944946289
vert -73.00248718261719 -22.699113845825195
vert -72.93834686279297 -22.526573181152344
vert -72.87846374511719 -22.352510452270508
vert -72.82286834716797 -22.17702865600586
vert -72.77159881591797 -22.00023651123047
vert -72.72468566894531 -21.82223892211914
vert -72.6821517944336 -21.643144607543945
vert -72.64402770996094 -21.463058471679688
vert -72.6103286743164 -21.282093048095703
vert -72.58109283447266 -21.100353240966797
vert -72.55632019042969 -20.917951583862305
vert -72.5360336303711 -20.734996795654297
vert -72.5202407836914 -20.551599502563477
vert -72.50894927978516 -20.367870330810547
vert -72.5021743774414 -20.18391990661621
vert -72.49991607666016 -19.999858856201172
vert -72.49991607666016 19.999858856201172
vert -72.5021743774414 20.18391990661621
vert -72.50894927978516 20.367870330810547
vert -72.5202407836914 20.551599502563477
vert -72.5360336303711 20.734996795654297
vert -72.55632019042969 20.917951583862305
vert -72.58109283447266 21.100353240966797
vert -72.6103286743164 21.282093048095703
vert -72.64402770996094 21.463058471679688
vert -72.6821517944336 21.643144607543945
vert -72.72468566894531 21.82223892211914
vert -72.77159881591797 22.00023651123047
vert -72.82286834716797 22.17702865600586
vert -72.87846374511719 22.352510452270508
vert -72.93834686279297 22.526573181152344
vert -73.00248718261719 22.699113845825195
vert -73.07083129882812 22.87002944946289
vert -73.14334869384766 23.039215087890625
vert -73.22000122070312 23.20656967163086
vert -73.30073547363281 23.37199592590332
vert -73.38551330566406 23.535388946533203
vert -73.4742660522461 23.696653366088867
vert -73.56695556640625 23.855690002441406
vert -73.66352081298828 24.012405395507812
vert -73.76390075683594 24.166702270507812
vert -73.8680419921875 24.31848907470703
vert -73.97586822509766 24.467676162719727
vert -74.08733367919922 24.614171981811523
vert -74.20235443115234 24.75788688659668
vert -74.32086944580078 24.89873695373535
vert -74.44281005859375 25.03663444519043
vert -74.5680923461914 25.171499252319336
vert -74.69664764404297 25.30324935913086
vert -74.82839965820312 25.431804656982422
vert -74.96326446533203 25.557086944580078
vert -75.10116577148438 25.67902183532715
vert -75.24201202392578 25.797536849975586
vert -75.38572692871094 25.912559509277344
vert -75.5322265625 26.024019241333008
vert -75.68140411376953 26.13184928894043
vert -75.83318328857422 26.235986709594727
vert -75.98748016357422 26.336368560791016
vert -76.14419555664062 26.432933807373047
vert -76.30323028564453 26.525623321533203
vert -76.46449279785156 26.614383697509766
vert -76.62788391113281 26.69915771484375
vert -76.79330444335938 26.779897689819336
vert -76.96066284179688 26.856552124023438
vert -77.12985229492188 26.9290771484375
vert -77.30076599121094 26.997426986694336
vert -77.47330474853516 27.061561584472656
vert -77.64736938476562 27.121444702148438
vert -77.82284545898438 27.17703628540039
vert -77.9996337890625 27.22830581665039
vert -78.17762756347656 27.27522087097168
vert -78.35671997070312 27.3177547454834
vert -78.53680419921875 27.355880737304688
vert -78.71776580810547 27.38957405090332
vert -78.89950561523438 27.4188175201416
vert -79.0819091796875 27.443592071533203
vert -79.26486206054688 27.463882446289062
vert -79.44825744628906 27.47967529296875
vert -79.6319808959961 27.490962982177734
vert -79.81593322753906 27.497739791870117
vert -79.99999237060547 27.499998092651367
vert -104.99999237060547 27.499998092651367
layer Acrylite.Display.Cut
mode C0.1
line -104.99983978271484 -29.999866485595703 -105.24525451660156 -29.99686050415039
line -105.24525451660156 -29.99686050415039 -105.49051666259766 -29.987831115722656
line -105.49051666259766 -29.987831115722656 -105.73548126220703 -29.97278594970703
line -105.73548126220703 -29.97278594970703 -105.98001098632812 -29.951732635498047
line -105.98001098632812 -29.951732635498047 -106.22394561767578 -29.9246826171875
line -106.22394561767578 -29.9246826171875 -106.46714782714844 -29.89165496826172
line -106.46714782714844 -29.89165496826172 -106.70946502685547 -29.85266876220703
line -106.70946502685547 -29.85266876220703 -106.95075225830078 -29.80774688720703
line -106.95075225830078 -29.80774688720703 -107.19086456298828 -29.756919860839844
line -107.19086456298828 -29.756919860839844 -107.42965698242188 -29.700214385986328
line -107.42965698242188 -29.700214385986328 -107.66698455810547 -29.637664794921875
line -107.66698455810547 -29.637664794921875 -107.9027099609375 -29.56930923461914
line -107.9027099609375 -29.56930923461914 -108.13668060302734 -29.495189666748047
line -108.13668060302734 -29.495189666748047 -108.36875915527344 -29.41535186767578
line -108.36875915527344 -29.41535186767578 -108.59880828857422 -29.32984161376953
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

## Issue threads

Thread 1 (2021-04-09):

TODO list

jvanstraten, 2021-04-09:
## PCBs

 - [ ] 230V circuit resistors: replace with 1/4W through-hole to avoid explosions
 - [ ] Update the X2 cap footprint to support different size caps, since it's hard to source

## Acrylic

 - [ ] Make a nicer way to set name/email/phone for Laserbeest drawing output
 - [ ] Add a way to change color of highlight sheet to black for people who want white on black PCBs
 - [ ] Lasercut the display sheet twice, because there's plenty of room on the sheet for that

## Printed parts

 - [ ] Revise positioning of screws and nuts in various places to make 12mm screws actually consistently long enough everywhere
 - [ ] Make positioning independent of acrylic thickness using 3D-printed washer stacks
 - [ ] Increase strength of strain relief
 - [ ] Increase strength of wall mount
 - [ ] Make opposite end of the wall mount to allow the clock to be more securely mounted to the wall
 - [ ] Increase strength and tolerances of the support board supports, because they keep breaking off
 - [ ] Fix color of light guide and display extender (needs to be black to avoid bleed)
 - [ ] Make a (pluggable) hole in the support board assembly for a USB connector to the Teensy LC (assuming standard male/female headers in between)
 - [ ] Add a plug for the GPS antenna connector for people who don't use a GPS module

## COTS parts

 - [ ] Add fasteners
 - [ ] Add power cable

## Firmware

 - [ ] Finish synchroscope
 - [ ] UI stuff
 - [ ] Automatic time config from GPS
 - [ ] DST?
 - [ ] Blink after loss of power/grid frequency until reconfigured using GPS or manually
 - [ ] Self test routines
 - [ ] ...

## Repository cleanup

 - [ ] Stick everything in a Docker container for reproducibility
 - [ ] Retry programming the Teensy from Docker now that I know what the original problem probably was
 - [ ] Edit/revise all readme files
 - [ ] Add pictures
 - [ ] Stop being lazy and actually push gerbertools to PyPI

## Organization

 - [ ] Work out how much to order for friends etc and what color LEDs everyone wants
 - [ ] Figure out if the subsequent exchange of money and goods would make the Belastingdienst upset (despite not charging for services)

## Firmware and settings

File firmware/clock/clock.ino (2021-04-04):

class TLC6C5748x3 {
public:

  struct Channel {
    uint16_t pwm_r;
    uint16_t pwm_g;
    uint16_t pwm_b;
    uint8_t dc_r;
    uint8_t dc_g;
    uint8_t dc_b;
    bool open_r;
    bool open_g;
    bool open_b;
    bool short_r;
    bool short_g;
    bool short_b;
  };

  struct Data {
    Channel ch[16];
    uint8_t mc_r;
    uint8_t mc_g;
    uint8_t mc_b;
    uint8_t bc_r;
    uint8_t bc_g;
    uint8_t bc_b;
    bool dsprpt;
    bool tmgrst;
    bool rfresh;
    bool espwm;
    bool lsdvlt;
  };

  Data data[3];

  bool shift_bit(bool d = false) {
    digitalWrite(0, d);
    delayMicroseconds(1);
    digitalWrite(20, HIGH);
    delayMicroseconds(1);
    digitalWrite(20, LOW);
    delayMicroseconds(1);
    return digitalRead(1);
  }
  
  void shift_word(uint16_t d, uint8_t nb) {
    for (int8_t i = nb - 1; i >= 0; i--) {
      shift_bit(d & (1 << i));
    }
  }
  
  void update() {
    // MSB of third device first!

    delayMicroseconds(10);
    
    /*// Send control data while reading fault data from previous cycle.
    digitalWrite(6, LOW);
    delayMicroseconds(50);
    for (int8_t device = 2; device >= 0; device--) {
      Data &d = data[device];
      d.ch[15].open_b = shift_bit(true);  // write 768 (select control latch), read 767
      d.ch[15].open_g = shift_bit(true);  // write 767 (control data write command in next 8 bits, 0x96), read 766
      d.ch[15].open_r = shift_bit(false); // write 766, read 765
      d.ch[14].open_b = shift_bit(false); // write 765, read 764
      d.ch[14].open_g = shift_bit(true);  // write 764, read 763
      d.ch[14].open_r = shift_bit(false); // write 763, read 762
      d.ch[13].open_b = shift_bit(true);  // write 762, read 761
      d.ch[13].open_g = shift_bit(true);  // write 761, read 760
      d.ch[13].open_r = shift_bit(false); // write 760, read 759
      // next shift is write 759, read 758
      for (int8_t channel = 12; channel >= 0; channel--) {
        Channel &c = d.ch[channel];
        c.open_b = shift_bit();
        c.open_g = shift_bit();
        c.open_r = shift_bit();
      }
      // next shift is write 720, read 719
      for (int8_t channel = 15; channel >= 0; channel--) {
        Channel &c = d.ch[channel];
        c.short_b = shift_bit();
        c.short_g = shift_bit();
        c.short_r = shift_bit();
      }
      // next shift is write 672, (read 671)
      for (uint16_t i = 0; i < 302; i++) {
        shift_bit();
      }
      // next shift is write 370
      shift_bit(d.lsdvlt);
      shift_bit(d.espwm);
      shift_bit(d.rfresh);
      shift_bit(d.tmgrst);
      shift_bit(d.dsprpt);
      // next shift is write 365
      shift_word(d.bc_b, 7);
      shift_word(d.bc_g, 7);
      shift_word(d.bc_r, 7);
      // next shift is write 344
      shift_word(d.mc_b, 3);
      shift_word(d.mc_g, 3);
      shift_word(d.mc_r, 3);
      // next shift is write 335
      for (int8_t channel = 15; channel >= 0; channel--) {
        const Channel &c = d.ch[channel];
        shift_word(c.dc_b, 7);
        shift_word(c.dc_g, 7);
        shift_word(c.dc_r, 7);
      }
      // full shift complete
    }
    delayMicroseconds(50);
    digitalWrite(6, HIGH);*/

    // Read fault data from previous cycle.
    digitalWrite(6, LOW);
    delayMicroseconds(10);
    for (int8_t device = 2; device >= 0; device--) {
      Data &d = data[device];
      // next shift is write 768, read 767
      for (int8_t channel = 15; channel >= 0; channel--) {
        Channel &c = d.ch[channel];
        c.open_b = shift_bit();
        c.open_g = shift_bit();
        c.open_r = shift_bit();
      }
      // next shift is write 720, read 719
      for (int8_t channel = 15; channel >= 0; channel--) {
        Channel &c = d.ch[channel];
        c.short_b = shift_bit();
        c.short_g = shift_bit();
        c.short_r = shift_bit();
      }
      // next shift is write 672, (read 671)
      for (uint16_t i = 0; i < 373; i++) {
        shift_bit();
      }
      // full shift complete
    }

    // Send control data.
    for (int8_t device = 2; device >= 0; device--) {
      Data &d = data[device];
      shift_bit(true);  // write 768 (select control latch)
      shift_bit(true);  // write 767 (control data write command in next 8 bits, 0x96)
      shift_bit(false); // write 766
      shift_bit(false); // write 765
      shift_bit(true);  // write 764
      shift_bit(false); // write 763
      shift_bit(true);  // write 762
      shift_bit(true);  // write 761
      shift_bit(false); // write 760
      // next shift is write 759, read 758
      for (uint16_t i = 0; i < 389; i++) {
        shift_bit();
      }
      // next shift is write 370
      shift_bit(d.lsdvlt);
      shift_bit(d.espwm);
      shift_bit(d.rfresh);
      shift_bit(d.tmgrst);
      shift_bit(d.dsprpt);
      // next shift is write 365
      shift_word(d.bc_b, 7);
      shift_word(d.bc_g, 7);
      shift_word(d.bc_r, 7);
      // next shift is write 344
      shift_word(d.mc_b, 3);
      shift_word(d.mc_g, 3);
      shift_word(d.mc_r, 3);
      // next shift is write 335
      for (int8_t channel = 15; channel >= 0; channel--) {
        const Channel &c = d.ch[channel];
        shift_word(c.dc_b, 7);
        shift_word(c.dc_g, 7);
        shift_word(c.dc_r, 7);
      }
      // full shift complete
    }
    delayMicroseconds(10);
    digitalWrite(6, HIGH);

    delayMicroseconds(10);

    // Send grayscale data.
    digitalWrite(6, LOW);
    delayMicroseconds(2);
    for (int8_t device = 2; device >= 0; device--) {
      Data &d = data[device];
      shift_bit(false);
      for (int8_t channel = 15; channel >= 0; channel--) {
        const Channel &c = d.ch[channel];
        shift_word(c.pwm_b, 16);
        shift_word(c.pwm_g, 16);
        shift_word(c.pwm_r, 16);
      }
    }
    delayMicroseconds(10);
    digitalWrite(6, HIGH);
    
  }


};

TLC6C5748x3 led_ctrl;

void setup() {
  pinMode(0, OUTPUT);   // LED driver SIN
  pinMode(1, INPUT);    // LED driver SOUT
  pinMode(2, INPUT);    // minutes Isw
  pinMode(3, INPUT);    // 50Hz override/readout
  pinMode(4, INPUT);    // GPS PPS
  pinMode(5, OUTPUT);   // minutes Ien
  digitalWrite(5, HIGH);
  pinMode(6, OUTPUT);   // LED driver LAT
  pinMode(7, INPUT);    // GPS RX
  pinMode(8, OUTPUT);   // GPS TX
  digitalWrite(8, HIGH);
  pinMode(9, OUTPUT);   // minutes Inc
  digitalWrite(9, HIGH);
  pinMode(10, OUTPUT);  // I/O CS
  digitalWrite(10, HIGH);
  pinMode(11, OUTPUT);  // I/O MOSI
  digitalWrite(11, LOW);
  pinMode(12, INPUT);   // I/O MISO
  pinMode(13, OUTPUT);  // display override
  digitalWrite(13, LOW);
  pinMode(14, OUTPUT);  // I/O SCK
  digitalWrite(14, LOW);
  pinMode(15, INPUT);   // I/O IRQ
  pinMode(16, OUTPUT);  // synchroscope PWM A
  digitalWrite(16, LOW);
  pinMode(17, OUTPUT);  // synchroscope PWM B
  digitalWrite(17, LOW);
  pinMode(18, OUTPUT);  // hours Inc
  digitalWrite(18, HIGH);
  pinMode(19, INPUT);   // hours Isw
  pinMode(20, OUTPUT);  // LED driver SCLK
  pinMode(21, OUTPUT);  // hours Ien
  digitalWrite(21, HIGH);
  pinMode(22, INPUT);   // power Imon
  pinMode(23, INPUT);   // power good
  pinMode(26, OUTPUT);  // minutes/hours Ren
  digitalWrite(26, HIGH);
  for (uint8_t dev = 0; dev < 3; dev++) {
    led_ctrl.data[dev].mc_r = 1;
    led_ctrl.data[dev].mc_g = 1;
    led_ctrl.data[dev].mc_b = 1;
    led_ctrl.data[dev].bc_r = 0x7F;
    led_ctrl.data[dev].bc_g = 0x7F;
    led_ctrl.data[dev].bc_b = 0x7F;
    led_ctrl.data[dev].dsprpt = true;
    led_ctrl.data[dev].tmgrst = false;
    led_ctrl.data[dev].rfresh = false;
    led_ctrl.data[dev].espwm = true;
    led_ctrl.data[dev].lsdvlt = false;
    for (uint8_t ch = 0; ch < 16; ch++) {
      led_ctrl.data[dev].ch[ch].pwm_r = 0x4000;
      led_ctrl.data[dev].ch[ch].pwm_g = 0x2000;
      led_ctrl.data[dev].ch[ch].pwm_b = 0x0000;
      led_ctrl.data[dev].ch[ch].dc_r = 0x0F;
      led_ctrl.data[dev].ch[ch].dc_g = 0x0F;
      led_ctrl.data[dev].ch[ch].dc_b = 0x0F;
    }
  }
  led_ctrl.data[1].ch[13].pwm_r = 0x8000;
  led_ctrl.data[1].ch[13].pwm_g = 0x8000;
  led_ctrl.data[1].ch[13].pwm_b = 0x8000;
  led_ctrl.data[1].ch[13].dc_r = 0x3F;
  led_ctrl.data[1].ch[13].dc_g = 0x3F;
  led_ctrl.data[1].ch[13].dc_b = 0x3F;
  led_ctrl.data[1].ch[14].pwm_r = 0x0400;
  led_ctrl.data[1].ch[14].pwm_g = 0x0200;
  led_ctrl.data[1].ch[14].pwm_b = 0x0000;
}

void loop() {
  // put your main code here, to run repeatedly:
  led_ctrl.update();
  delay(200);
}

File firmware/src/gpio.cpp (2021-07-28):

#include "gpio.hpp"

#include <WProgram.h>
#include "pwr.hpp"
#include "sine.hpp"

/**
 * Regular GPIO & MCP23S17 logic.
 */
namespace gpio {

/**
 * Starts a SPI transaction by pulling SS low.
 */
static inline void spi_start() {
    digitalWrite(PIN_EXP_CS, LOW);
}

/**
 * Synchronously transfers a byte using the SPI.
 */
static uint8_t spi_xfer(uint8_t val) {
    while (!(SPI0_S & (1ul << 5)));
    SPI0_DL = val;
    while (!(SPI0_S & (1ul << 7)));
    return SPI0_DL;
}

/**
 * Drains the receive buffer and asserts SS, returning the last byte read.
 */
static void spi_stop() {
    digitalWrite(PIN_EXP_CS, HIGH);
}

/**
 * Starts a SPI transaction to the given MCP23S17 register.
 */
static void mcp_start(bool write, uint8_t reg) {
    spi_start();
    spi_xfer(write ? 0b01001110 : 0b01001111);
    spi_xfer(reg);
}

/**
 * Synchronously writes a byte to the MCP23S17.
 */
static void mcp_write_byte(uint8_t reg, uint8_t val) {
    mcp_start(true, reg);
    spi_xfer(val);
    spi_stop();
}

/**
 * Synchronously writes two bytes to the MCP23S17.
 */
static void mcp_write_word(uint8_t reg, uint16_t val) {
    mcp_start(true, reg);
    spi_xfer(val & 0xFF);
    spi_xfer(val >> 8);
    spi_stop();
}

/**
 * Synchronously reads two bytes from the MCP23S17.
 */
static uint16_t mcp_read_word(uint8_t reg) {
    mcp_start(false, reg);
    uint16_t val = spi_xfer(0);
    val |= (uint16_t)spi_xfer(0) << 8;
    spi_stop();
    return val;
}

/**
 * The latest value read from the I/O expander's GPIO port.
 */
uint16_t mcp_gpio_in = 0;

/**
 * The value to write to the I/O expander's GPIO port.
 */
uint16_t mcp_gpio_out = 0;

/**
 * The value to write to the I/O expander's IODIR register. 1 means output,
 * 0 means input (so this value is inverted w.r.t. the IODIR register; who
 * the hell makes 1 mean input?)
 */
uint16_t mcp_iodir = 0;

/**
 * Synchroscope LED position. ranges from 0 to 30*256-1.
 */
uint16_t synchro = 0;

/**
 * Whether the synchroscope should be enabled.
 */
bool synchro_enable = false;

/**
 * Button event code for the UI logic to use. Must be cleared to NONE by the UI
 * logic.
 */
Event event = Event::NONE;

/**
 * Configures the GPIO logic.
 */
void setup() {

    // Initial I/O configuration with Arduino.
    pinMode(PIN_EXP_CS, OUTPUT);    digitalWrite(PIN_EXP_CS, HIGH);
    pinMode(PIN_EXP_MOSI, OUTPUT);  digitalWrite(PIN_EXP_MOSI, HIGH);
    pinMode(PIN_EXP_MISO, INPUT);
    pinMode(PIN_EXP_SCK, OUTPUT);   digitalWrite(PIN_EXP_SCK, HIGH);
    pinMode(PIN_EXP_IRQ, INPUT);

    analogWriteResolution(16);
    pinMode(PIN_SYNCHRO_A, OUTPUT); analogWrite(PIN_SYNCHRO_A, 65535);
    pinMode(PIN_SYNCHRO_B, OUTPUT); analogWrite(PIN_SYNCHRO_B, 65535);

    pinMode(PIN_MIN_ISW, INPUT);
    pinMode(PIN_MIN_IEN, OUTPUT);   digitalWrite(PIN_MIN_IEN, HIGH);
    pinMode(PIN_MIN_INC, OUTPUT);   digitalWrite(PIN_MIN_INC, HIGH);
    pinMode(PIN_HR_ISW, INPUT);
    pinMode(PIN_HR_IEN, OUTPUT);    digitalWrite(PIN_HR_IEN, HIGH);
    pinMode(PIN_HR_INC, OUTPUT);    digitalWrite(PIN_HR_INC, HIGH);
    pinMode(PIN_REN, OUTPUT);       digitalWrite(PIN_REN, HIGH);

    // Configure the SPI unit.
    SIM_SCGC4  |= (1ul << 22);  // enable SPI clock
    SPI0_C1     = (0ul << 7)    // disable SPI interrupt
                | (1ul << 6)    // enable SPI system
                | (0ul << 5)    // disable transmit interrupt
                | (1ul << 4)    // select SPI master mode
                | (0ul << 3)    // SPI clock polarity idle low
                | (0ul << 2)    // SPI clock phase 0
                | (0ul << 1)    // slave select pin config is don't care
                | (0ul << 0);   // MSB first
    SPI0_C2     = (0ul << 7)    // disable match interrupt
                | (0ul << 6)    // use 8-bit SPI
                | (0ul << 5)    // disable transmit DMA
                | (0ul << 4)    // disable mode-fault function, whatever that is
                | (0ul << 3)    // disable bidirectional mode
                | (0ul << 2)    // disable receive DMA
                | (0ul << 1)    // no need for low power stuff
                | (0ul << 0);   // normal SPI pin directions
    SPI0_BR     = (0ul << 4)    // disable prescaler
                | (2ul << 0);   // divide by 8

    // Connect the hardware-controlled SPI pins to the SPI unit.
    CORE_PIN11_CONFIG = PORT_PCR_MUX(2) | PORT_PCR_SRE | PORT_PCR_DSE;
    CORE_PIN12_CONFIG = PORT_PCR_MUX(2) | PORT_PCR_SRE | PORT_PCR_DSE;
    CORE_PIN14_CONFIG = PORT_PCR_MUX(2) | PORT_PCR_SRE | PORT_PCR_DSE;
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

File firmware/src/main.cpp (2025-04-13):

#include <Arduino.h>
#include "pwr.hpp"
#include "clk.hpp"
#include "led.hpp"
#include "gps.hpp"
#include "gpio.hpp"
#include "timer.hpp"
#include "sine.hpp"
#include "synchro.hpp"
#include "ldr.hpp"
#include "ui.hpp"
#include "tz.hpp"

/**
 * Initialization function called by Arduino's main().
 */
void setup() {
    Serial.begin(115200);
    pwr::setup();
    clk::setup();
    led::setup();
    gps::setup();
    gpio::setup();
    timer::setup();
    ldr::setup();
    tz::setup();
    ui::setup();
}

/**
 * Main loop, called by Arduino's main().
 */
void loop() {

    // Update everything.
    unsigned long t1 = micros();
    pwr::update();
    clk::update();
    led::update();
    gps::update();
    synchro::update();
    gpio::update();
    ldr::update();
    tz::update();
    ui::update();
    unsigned long t2 = micros();

    // Write debug output via USB serial if enabled.
    static bool debugging = false;
    if (Serial.available()) {
        debugging = true;
    }
    if (debugging) {
        static uint32_t grid_period;
        if (timer::grid_period) {
            grid_period = timer::grid_period;
        }
        static unsigned long debug_timer;
        unsigned long now = millis();
        if (now - debug_timer > 1000) {
            int32_t f_mhz = ((int64_t)48000000 * 1000 / grid_period);
            Serial.printf("update micros: %lu\n", t2 - t1);
            Serial.printf("grid: %d mHz\n", f_mhz);
            Serial.printf("gpio exp: %04X\n", gpio::mcp_gpio_in);
            if (gps::valid) {
                Serial.printf(
                    "gps time: %04d-%02d-%02d %02d:%02d:%02d.%04d\n",
                    gps::year, gps::month, gps::day,
                    gps::hours, gps::minutes, gps::seconds, gps::milliseconds
                );
            } else {
                Serial.printf("gps time: no fix\n");
            }
            Serial.printf("gps signal: %d\n", gps::signal_strength);
            if (led::displayed_time_valid) {
                Serial.printf(
                    "displayed time: %02d:%02d:%02d\n",
                    led::displayed_hours, led::displayed_minutes, led::displayed_seconds
                );
            } else {
                Serial.printf("displayed time: unknown\n");
            }
            Serial.printf("pgood: %d\n", digitalRead(23));
            Serial.printf("current: %d mA\n", pwr::current);
            Serial.printf("LDR adc: %d samples\n", ldr::debug_adc_value());
            Serial.printf("LDR illuminance: %d/64 lux\n", ldr::debug_illuminance());
            Serial.printf("LDR brightness: %d%%\n", ldr::dimmed_brightness(100, 1, 640) + 1);
            Serial.println("");
            debug_timer = now;
        }
    }

}

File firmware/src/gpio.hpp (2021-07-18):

#include <inttypes.h>

#pragma once

/**
 * Regular GPIO & MCP23S17 logic.
 */
namespace gpio {

// I/O expander pin number definitions (Arduino). NOTE: do not change, fixed
// to hardware SPI ports.
static const int PIN_EXP_CS                 = 10;
static const int PIN_EXP_MOSI               = 11;
static const int PIN_EXP_MISO               = 12;
static const int PIN_EXP_SCK                = 14;
static const int PIN_EXP_IRQ                = 15;

// Synchroscope PWM pin number definitions (Arduino).
static const int PIN_SYNCHRO_A              = 16;
static const int PIN_SYNCHRO_B              = 17;

// Synchroscope selection pin number definitions (MCP23S17).
static const uint16_t PIN_SYNCHRO_H_MASK    = 0b0100000011111000;
static const uint16_t PIN_SYNCHRO_L_MASK    = 0b0011111100000000;
static const uint16_t PIN_SYNCHRO_TAB[30]   = {
    0b0110000000100000, // 1-2
    0b0010000010100000, // 2-3
    0b0010000010010000, // 3-4
    0b0010000001010000, // 4-5
    0b0011000001001000, // 5-6
    0b0101000000001000, // 6-7
    0b0101000000100000, // 7-8
    0b0001000010100000, // 8-9
    0b0001000010010000, // 9-10
    0b0001100001010000, // 10-11
    0b0000100001001000, // 11-12
    0b0100100000001000, // 12-13
    0b0100100000100000, // 13-14
    0b0000100010100000, // 14-15
    0b0000110010010000, // 15-16
    0b0000010001010000, // 16-17
    0b0000010001001000, // 17-18
    0b0100010000001000, // 18-19
    0b0100010000100000, // 19-20
    0b0000011010100000, // 20-21
    0b0000001010010000, // 21-22
    0b0000001001010000, // 22-23
    0b0000001001001000, // 23-24
    0b0100001000001000, // 24-25
    0b0100001100100000, // 25-26
    0b0000000110100000, // 26-27
    0b0000000110010000, // 27-28
    0b0000000101010000, // 28-29
    0b0000000101001000, // 29-30
    0b0110000100001000  // 30-1
};

// Microcontroller button pin number definitions (MCP23S17).
static const int PIN_BTN_MODE               = 0;
static const int PIN_BTN_DOWN               = 1;
static const int PIN_BTN_UP                 = 2;
static const uint16_t PIN_BTN_MODE_MASK     = 0b0000000000000001;
static const uint16_t PIN_BTN_DOWN_MASK     = 0b0000000000000010;
static const uint16_t PIN_BTN_UP_MASK       = 0b0000000000000100;
static const uint16_t PIN_BTN_MASK          = 0b0000000000000111;

// Clock configuration pin number definitions (Arduino).
static const int PIN_MIN_ISW                = 2;
static const int PIN_MIN_IEN                = 5;
static const int PIN_MIN_INC                = 9;
static const int PIN_HR_ISW                 = 19;
static const int PIN_HR_IEN                 = 21;
static const int PIN_HR_INC                 = 18;
static const int PIN_REN                    = 26;

// Clock reset pin number definition (MCP23S17).
static const int PIN_RESET                  = 15;
static const uint16_t PIN_RESET_MASK        = 0b1000000000000000;

/**
 * The latest value read from the I/O expander's GPIO port.
 */
extern uint16_t mcp_gpio_in;

/**
 * The value to write to the I/O expander's GPIO port.
 */
extern uint16_t mcp_gpio_out;

/**
 * The value to write to the I/O expander's IODIR register. 1 means output,
 * 0 means input (so this value is inverted w.r.t. the IODIR register; who
 * the hell makes 1 mean input?)
 */
extern uint16_t mcp_iodir;

/**
 * Synchroscope LED position. ranges from 0 to 30*256-1.
 */
extern uint16_t synchro;

/**
 * Whether the synchroscope should be enabled.
 */
extern bool synchro_enable;

/**
 * Event code for the event shared variable.
 */
enum class Event {
    NONE,    // no event
    CANCEL,  // up + down
    SHORT,   // short mode press
    LONG,    // long mode press
    UP_INIT, // up initial press
    UP_AUTO, // up auto-increment
    DN_INIT, // down initial press
    DN_AUTO, // down auto-increment
    RESET,   // circuit reset released
    INACTIVE // 30 seconds after last input
};

/**
 * Button event code for the UI logic to use. Must be cleared to NONE by the UI
 * logic.
 */
extern Event event;

/**
 * Configures the GPIO logic.
 */
void setup();

/**
 * Updates the GPIO logic.
 */
void update();

} // namespace timer

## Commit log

2021-01-29 Distinguish primitive inputs and outputs
    [nand1.blend, nand2.blend, nand3.blend]
2021-01-29 Complete blender to gerber, add decode10
2021-01-30 Refactor for consistency
    [nand1.blend, nand2.blend, nand3.blend]
2021-01-30 Add nonlinear coordinate transformers
    [feed.blend]
2021-01-31 Remove gerber submod, it can just be its own thing
2021-01-31 Add soldermask expansion
2021-02-02 Add circuit that's actually in the clock
2021-02-05 Add D-flipflop
    [cross.blend, feeda.blend, ffled.blend]
2021-02-05 First recursive subcircuit, div2
    [tie.blend]
2021-02-08 Fix soldermask expansion scale
2021-02-08 Fix incorrect circuit for div2
2021-02-08 Fix hold timing, rework prims for gnd/vcc planes
    [nand1.blend, nand1s.blend, nand2.blend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]
2021-02-12 Timing broken everywhere
    [cross.blend, jumper.blend]
2021-02-12 Add RC delay inside flipflop to fix hold timing
    [nand2q.blend, nand3qn.blend]
2021-02-13 Add slide switch for config circuit
    [JSM07011SAQNL.stp]
2021-02-14 Add configuration circuit
    [c-2328702-4-a-3d.stp, config.circuit.txt, config_sw.blend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]
2021-02-14 Add div5or2 from notes; it has a clkout hazard tho
    [config.circuit.txt]
2021-02-15 Make mainboard primitive
    [mainboard.blend]
2021-02-16 Add SVG/PDF generation for laserbeest.nl
2021-02-16 Laserbeest offerte aangevraagd
    [acrylite_test.blend, mainboard.blend]
2021-02-19 Add highlight plate & generated cutouts
    [config.circuit.txt, mainboard.blend]
2021-02-19 Remove ~ and * suffixes with extreme prejudice
    [nand2q.blend, nand3qn.blend]
2021-02-19 Orient FFC connector in config correctly
    [config_uc.blend, config_uc.blend.txt]
2021-02-20 Add physical DRC
    [config_uc.blend, config_uc.blend.txt]
2021-02-20 Fully routed Gnd and Vcc
    [config_sw.blend, config_sw.blend.txt, config_uc.blend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]
2021-02-24 Layout freeze
    [config.circuit.txt]
2021-02-25 Refactor/add parts, redo config_uc
    [c-2328702-4-a-3d.stp, config_uc.blend, config_uc.blend.txt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]
2021-02-25 Fix/update text
    [config.circuit.txt, config_uc.blend, config_uc.blend.txt]
2021-02-25 Complete ffled primitive
    [ffled.blend]
2021-02-25 Add white line around front cutouts
    [ffled.blend]
2021-02-25 Routed everything except Arn and ClkIn
    [config_uc.blend]
2021-02-26 Finish top overlay with circuits
2021-02-26 Finish top silkscreen
    [config_sw.blend, config_sw.blend.txt, config_uc.blend.txt]
2021-02-26 Choose LEDs and resistors after testing
    [config_uc.blend, config_uc.blend.txt, nand1.blend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]
2021-02-26 WIP on synchroscope
    [APD3224.blend]
2021-02-27 Add some documentation, add extra screw holes
2021-02-27 Jury-rig a copper layer view of the board
2021-02-28 Fix VHDL sim, fix decoders
    [config_sw.vhd.txt, config_uc.vhd.txt]
2021-02-28 WIP on rendering
    [acrylic.template.blend, mainboard.template.blend, top.blend]
2021-02-28 Add parts to rendered version of PCB
    [0603C.blend, 0603R.blend, DCK3.blend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]
2021-03-01 Minor changes and WIP on 3D-printed parts
    [LTST-C230-cover.blend, back-shell.blend, nand1.blend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]
2021-03-02 Add a bunch of 3D models
    [1206C.blend, ADP3224.blend, LTST-C230.blend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]
2021-03-03 Start work on support board
    [DCA56.blend, M3x12.blend, support_board.blend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]
2021-03-04 Routed display LEDs to LED controllers
2021-03-05 Documentation, and tie LED drivers to 3V3
    [config_sw.blend, config_sw.blend.txt, top.blend]
2021-03-05 Correctly orient transistors
    [top.blend]
2021-03-06 Finish top half of support board
2021-03-06 Finish designing and documenting circuitry
2021-03-06 Route power supply
    [B78108E.blend, LTV-816.blend, PWP20.blend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]
2021-03-06 Route grid frequency filter
    [top.blend]
2021-03-07 Finish all routing & all part 3D models
    [ADP3224.blend, APD3224.blend, C5X11.blend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]
2021-03-07 WIP on layout/circuit verification toolchain
    [APD3224.verif.blend, ASMB-KTF0-0A306.verif.blend, B72214U2271K501.verif.blend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]
2021-03-08 Version 0.2?
    [B78108E.blend, HDR-2X8-F.verif.blend, HDR-2X8-M.verif.blend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]
2021-03-08 Minor fixes
    [config_uc.blend, config_uc.blend.txt]
2021-03-09 Random changes
    [top.blend]
2021-03-13 Add 3D-printed parts, finish order lists
    [LTST-C230-cover.blend, M3NUT.blend, back-shell.blend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]
2021-03-14 Final touches before ordering things
    [hv.3mf]
2021-04-04 Update readme, add LED bending die
    [led-bender.blend, led-bending-die.3mf, led-bending-die.bottom.stl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]
2021-04-06 Refactor led driver, do input capture stuff
2021-04-09 Replace 47R and X cap
    [R-OL.blend, R47-500m.verif.blend]
2021-04-10 Revise 3D-printed parts, fix render/top.blend
    [LTST-C230-cover.blend, buttons.blend, display-extender.3mf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]
2021-04-12 Improve LED init sequence
2021-05-28 WIP adding LED color scheme selection logic
2021-06-09 Increase PCB error tolerance
2021-06-21 Update printed parts for LDR
2021-07-16 Make verif models appropriately generic
    [LTST-C230-GATE.verif.blend, LTST-C230-UC.verif.blend, R-APD3224.verif.blend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]
2021-07-18 Various fixes to PCB docs and silkscreen
    [APD3224.verif.blend, config_uc.blend, config_uc.blend.txt]
2021-07-24 Fix hue offset, improve synchroscope gamma
    [gpio.cpp, led.cpp]
2021-07-25 Add quick-start guide
    [acrylic.template.blend, bracket.blend]
2021-07-28 Blue flipflop LED needs higher resistance value
2024-10-18 build: remove checked-in Blender export files
    [config_sw.blend.txt, config_uc.blend.txt]
2024-11-30 Modified support board for RP2040
    [D-1N5819HW.verif.blend, GPS.blend, RPI-PICO-W.blend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]
2025-02-23 Fix orientation of diode feeding pico on silkscreen and assembly instructions
2025-02-23 Fix printed/Makefile to work with blender 4.2
2025-02-23 Increase pin hole size for header spacers
    so hopefully they don't need to be adjusted after printing this time
2025-04-05 Full dimming support. You can now configure minimum brightness levels for all 4 led classes, and ldr is now no longer an on/off option, but a trigger to configure at what light level to start dimming.
    [ldr.cpp, ldr_calc.c, main.cpp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]
